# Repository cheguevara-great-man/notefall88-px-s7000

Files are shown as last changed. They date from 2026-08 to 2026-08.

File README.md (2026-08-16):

# NoteFall 88

NoteFall 88 是面向 Casio PX-S7000 的可拆卸单排琴键提示灯。钢琴通过 USB-MIDI 直接连接 ESP32-S3；ESP32-S3 驱动一条覆盖 88 键的 APA102C/SK9822 灯带，并通过 Wi-Fi 连接 NoteFall Studio 平板 App/PWA 或内置 Core 网页。

> 钢琴上只有一排灯。瀑布流只在屏幕里显示。

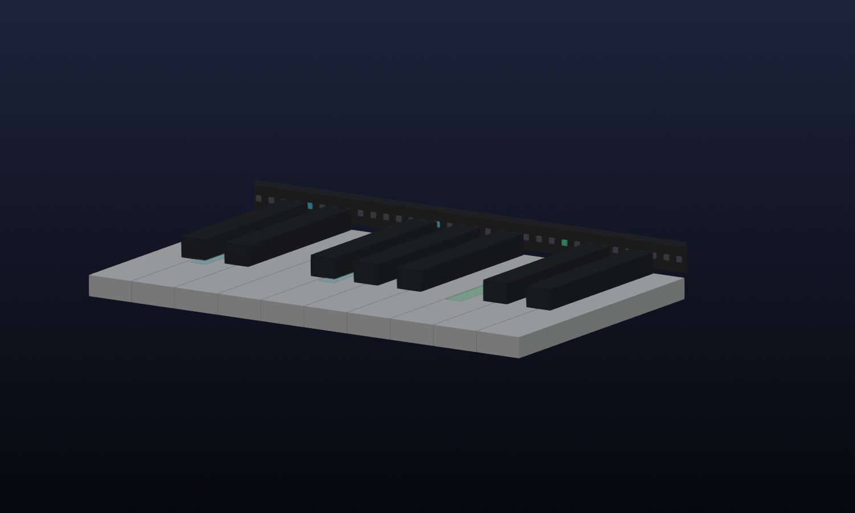
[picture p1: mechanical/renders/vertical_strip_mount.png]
竖直裸灯带安装原理


> 琴键一侧不使用贯穿全长的 3D 打印盒。灯带竖直安装、发光面朝演奏者且前方无遮挡，宽角度光束的下半部分直接照亮对应琴键。可选黑色薄承载片只负责保持灯带笔直，不包裹灯珠，也不是打印件。

安装时若对“朝演奏者”或照键角度有疑问，以 [带标注的剖面光路图](docs/optical-installation.svg) 为准：灯带不是朝上，也不是架高悬空，而是紧邻键面竖直安装在钢琴自带的固定黑色立面上。

## 最终架构

```text
PX-S7000 USB TO HOST <──USB-MIDI──> ESP32-S3-DevKitC-1 N8R8
                                             │
                                SPI ──> 74AHCT125 ──> 单排灯带
                                             │
                                           Wi-Fi
                                             │
                         NoteFall Studio App / PWA / Core 网页
```

网页端可直接导入 MIDI、MusicXML、XML 和 MXL，按需显示瀑布流或五线谱，并提供实时、等我弹和跟随我三种练习模式、左右手筛选、25%–200% 五个百分点步进变速、±12 半音同步移调、A–B 循环和命中/错键/漏键统计。MusicXML 的小节轨既可两点设整小节 A–B，也可从已选小节开始一轮新的、不会把前段误记为漏音的练习。实时模式可启用按 MIDI/MusicXML 真实拍号、速度变化和反复顺序生成的 Web Audio 节拍器，以及一小节预备拍；常用练习设置刷新后保留。实时分析还会计算拍点早晚、平均/P95 时序误差、力度均值与波动、最长连续命中和逐键难点；瀑布流在对应琴键上即时给出命中、错键、漏键标记。每次练习连同原始乐谱 SHA-256、模式、声部、速度、移调与循环范围仅保存在本机，可导出 JSON；任意历史会话可重新打开为时间/键位复盘，且同曲目多次记录会以稳定前后窗口显示准确率与时序改善趋势。自适应教练按内容身份而非曲名汇总同谱近期历史，避免同名不同谱串曲，再找出错漏最集中的片段和较弱声部，给出有证据的模式、速度、A–B 建议并可一键应用；进一步的“弱点巡回”会按反复展开后的小节、近期权重、错漏、拍点和左右手差异生成最多三关不重叠的训练路线，自动配置整小节循环、模式、声部与速度，并要求每关连续达标而不是偶然弹对；进度只保存在本机，可中断恢复。跟随我模式只要求用户弹一只手，另一只手经带时间戳的 USB-MIDI OUT 队列由 PX-S7000 自身音源演奏；若实机没有 OUT 端点则明确降级为无伴奏跟随。IndexedDB 曲库支持文件夹、并发内容去重，以及带 SHA-256、规模上限和原子恢复的完整备份；演奏录制包含力度、MIDI 通道和延音踏板，可导出标准 MIDI。钢琴按键数据走 USB 直达 ESP32，因此按键反馈不依赖无线链路。ESP32 自动连接已保存的家庭 Wi-Fi，同时永久保留 `NoteFall-88` 救援热点；Android Studio App 在局域网内自动发现设备并在地址变化后重连，浏览器可使用当前家庭 IP 或路由器支持时的 `http://notefall.local`，永久救援入口始终是 `http://192.168.4.1/recovery`。

曲库中的“今日练习”把单曲教练提升到跨曲目：只接受覆盖至少 60% 目标音、且没有 A–B 循环的全曲记录作为掌握证据，薄弱曲优先，连续稳定后按 1/3/7/14/30/60 天逐级安排复习。短循环刷出的 100% 不会延长整曲复习间隔；全部计算和历史仍只留在本机。

“示范当前声部”可从当前位置按所选左手、右手或双手，将乐谱音符和 CC64 踏板用 1.5 秒有界前瞻队列送回 PX-S7000 自身音源；变速、A–B 循环、换踏和重复同音都使用同一时间线。没有 MIDI OUT 时仍能静音预览谱面、瀑布流和实体目标灯；页面进后台、断连、循环回跳和手动停止都会执行踏板释放与 16 通道急停。演奏录制完成后也可不经导出直接用钢琴回放：保留 MIDI 通道、力度和 CC64/66/67，不把音量、音色等无关控制回写到钢琴，长音的 Note Off 按后续时间窗精确排程而不被 60 秒协议上限提前截断。

等待类模式要求目标和弦当前同时物理按住且没有仍按住的错误键，不能把各音逐个点过后松开来绕过和弦训练；目标音在整组和弦成立前只暂存、不计分，提前松键会撤销该音的暂存命中，因此也不能靠重复点按刷分。若正确和弦保持期间松开错误键，会立即一次性提交整组命中并推进，无需重弹。

实时判定与演奏录音使用 ESP32 在 USB 回调处采集的单调时间戳；浏览器通过低往返样本同步两端时钟，因此 Wi-Fi 排队抖动不会直接变成虚假的早/晚误差。旧固件或异常时间戳会明确降级为到达时间，不伪造同步精度。

实时模式不再用一套固定宽容度覆盖整首曲子：自适应、宽容、严格三档会按每个位置的真实拍速生成逐和弦窗口；快速重复同音还会受相邻同音间隔约束，避免一次按键误认成前后两个音。改变练习速度会保持相同的音乐拍值比例，练习面板同时显示当前现实毫秒范围。

录制导出会保留手指真实离键时刻、CC88 高分辨率力度前缀以及连续 CC64 半踏板、CC66/67 控制；实时练习分析在钢琴启用该选项时使用完整 14 位力度。若停止录制时延音踏板仍踩下，会自动补一个 CC64=0，避免文件回放时挂住踏板。

每个正确音还保留谱面目标力度。表现力分析会把整台琴/演奏者普遍偏轻或偏重的“力度基准”与相对强弱轮廓分开：前者单独显示，后者以 0–100 分进入历史趋势、复盘时间段和教练建议；谱面没有足够强弱变化时不会伪造轮廓分。

实时模式还会在 Note On 命中后继续跟踪物理 Note Off 与 CC64：分别记录手指松键和踏板抬起后的实际收音，计算谱面时值覆盖、无踏板释放精度、提前收音率与踏板延长量。MusicXML 的 staccato、staccatissimo、detached-legato 和 tenuto 会修正目标门控；没有可靠踏板记号时只报告踏板延长，不把过踏板武断判成错误。

和弦同步分析只合并乐谱中起点完全相同且完整命中的音，不把琶音、邻近快速音或漏音后的残缺和弦误判为“不齐”。它分别给出和弦展开宽度、P95、整齐度分，以及右手相对左手的有符号提前/滞后；这些证据进入时间复盘、历史趋势、教练调速和带连续达标门槛的双手专项巡回。

MusicXML 谱面中的延音踏板开始、停止、换踏和 0–100% 半踏深度会展开到真实反复播放时间线，先以 `PED ↓ / ↑ / ↻ / 百分比` 在 Web Canvas 与 Android 原生瀑布流中提前提示，再与 PX-S7000 的连续 CC64 输入逐动作匹配。判定按当前速度换算实际毫秒偏差，A–B 重复逐遍隔离，区分漏踏、多余动作、时机和深度；结果进入实时洞察、分段复盘、历史趋势、自适应调速与实时踏板专项关卡。没有踏板记号的谱面不会伪造提示或踏板分数。

手机锁屏、切换 App 或页面进入后台时，网页会确定性暂停乐谱时钟和预备拍、急停钢琴伴奏、熄灭目标灯，并停止且保留当前录音，避免浏览器节流造成批量漏键、延迟伴奏或静默录音缺口；返回前台后停在同一练习位置，由用户手动继续。

为避免手机在误开录制后无限占用内存，单次录制最多 4 小时或 200,000 个 MIDI 事件；达到任一上限会自动停止、明确提示，并允许下载上限前已经完整保存的部分。

MusicXML 目标时间线会按常见反复、多结尾和标准 D.C./D.S./Fine/Coda 导航属性展开，并支持普通/附点 beat-unit 的精确 metric modulation；五线谱光标通过播放小节到书写小节的映射正确回跳，而不是只按页面顺序判分。

首次仍通过 UART 线刷；此后可从家庭 LAN 或永久救援热点用管理密码更新双槽固件或 LittleFS 网页。上传中断不会切换启动槽；新固件必须通过内部自检并被真实 HTTP/WebSocket 客户端访问，未确认或启动异常会自动回滚。固件内置不依赖 LittleFS 的 `/recovery`。家庭 Wi-Fi 上的控制首次用管理密码解锁，随后浏览器持久保存随机令牌且 ESP 重启后仍有效；修改管理密码会撤销旧令牌。详见 [安全更新说明](docs/update.md)、[网络与救援](docs/deploy/network-and-recovery.md) 与 [WebSocket 协议](docs/protocol.md)。

手机离线使用由 ESP32 自己托管完整网页保证，不虚假依赖在局域网 HTTP 上通常不可注册的 Service Worker。浏览器曲库提供配额/持久化诊断和可校验备份；安全上下文、origin 隔离及 iOS/Android 验收边界见 [手机离线与本地数据](docs/mobile-offline-and-storage.md)。Studio 已把 3:2 横屏大平板作为正式目标，Xiaomi Pad 7 Ultra 的布局策略、首屏琴盘约束和自动化视口验收见 [Studio 平板布局](docs/studio-tablet-layout.md)。

Studio 还能在平板本地导入 MSCZ/MSCX、GP/GP3/GP4/GP5/GPX/GTP/PTB 和 KAR：锁定版本的 WebAssembly 在独立 Worker 中转为 MusicXML，不依赖 CDN，不进入 ESP32，完成后立即释放约 20 MB 运行时。转换后的标准 MusicXML 进曲库，二次打开无需重新转换。真实 MSCX 端到端浏览器门禁会同时验证三个音符的练习时间线和 OSMD 五线谱。

内置安装向导把断电接线/保险丝/无损材料/三点灯位/机械稳定等人工确认，与 ESP 连接、PX-S7000 USB 枚举、MIDI IN 端点和真实中央 C Note On 自动证据合并；未齐全时始终显示“硬件尚未验收”，并可导出不含密码的 JSON 报告。详见 [引导式验收说明](docs/commissioning.md)。

## 硬件基线

- 乐鑫 ESP32-S3-DevKitC-1-N8R8
- 5 V、144 像素/米、IP30 的 APA102C 或 SK9822；当前实物为 `32 + 72 + 72` 三段焊成的一条逻辑链
- 共 176 像素；计入两个照片拟合焊缝后物理长度约 `1230.42 mm`，覆盖 1222 mm 的 88 键键床
- 74AHCT125 成品电平转换模块
- 5 V / 5 A 有认证成品电源、3 A 总保险、20 AWG 首尾两端注电
- H5 给 USB-to-UART 口供电，H7 给 OTG Y 线的第 3 口供电；Y 线数据口经 USB-A 转 USB-B 打印机线连接钢琴
- Micro-Fit 4P 锁扣输入线和 XT30 远端注电线；所有引脚、线色和代焊验收已固定

第一次实际制作直接按 [五步装机清单](docs/first-build.md) 执行。完整采购见 [BOM 表](docs/bom.csv)，接线见 [硬件说明](docs/hardware.md) 与 [USB Host/供电决策记录](docs/decisions/001-native-usb-host-and-vbus.md)，可直接发给代焊方的规格见 [线束制造表](docs/harness.csv)、[线束图](docs/wiring-harness.svg) 和 [代工消息模板](docs/vendor-order-template.md)。逐项完成证据与实物边界见 [工程完成度审计](docs/completion-audit.md)。参数化控制盒如下；它只保护 ESP32 和接线，不安装在琴键上。

当前这台 PX-S7000 已购买商家确认可共点的 KF301‑2P/3P 端子与 74AHCT125N 裸芯片；KF301 到货后先逐孔验证共点关系，符合说明就直接用于配电，无需另买端子。实际购买记录、与通用 BOM 的差异及到货后唯一执行顺序见 [本机部署资料](docs/deploy/README.md)。历史问答保留用于解释决策，但不替代接线图和验收规范。

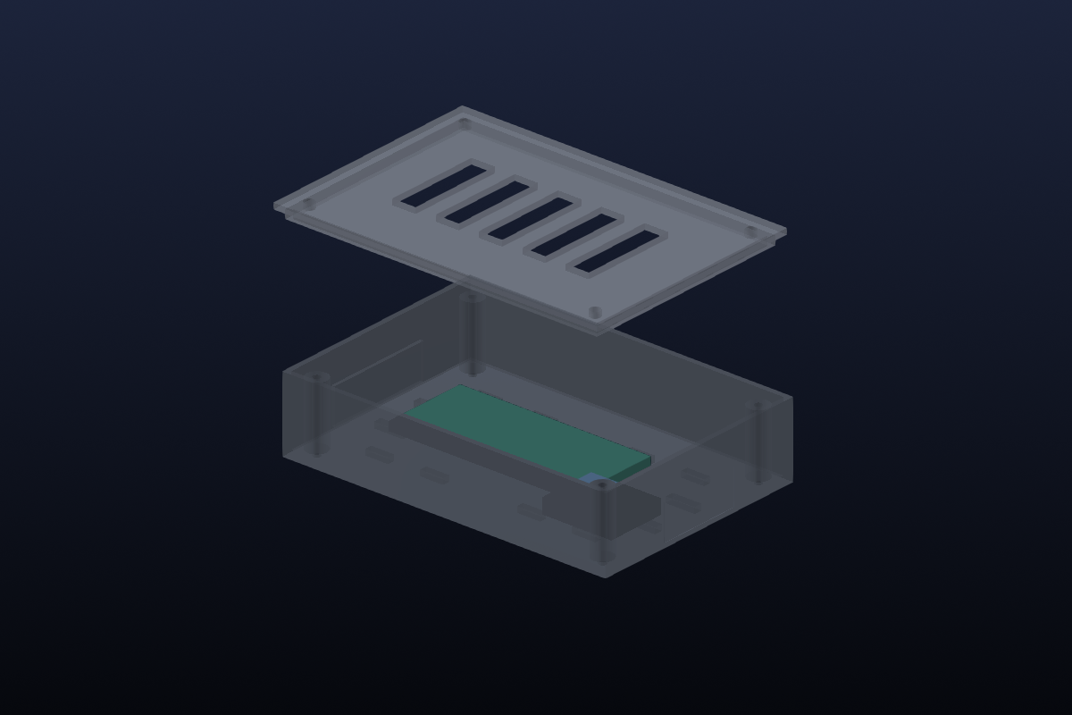
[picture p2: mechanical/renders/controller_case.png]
控制盒爆炸图


## 仓库内容

- `firmware/`：ESP32-S3 固件、USB-MIDI Host、Wi-Fi/WebSocket 和 APA102/SK9822 驱动
- `web/`：手机/平板/电脑通用网页，包含乐谱、曲库、练习、录制、诊断和校准
- `studio/`：Studio 独立 PWA 资源与 Capacitor Android/iOS 原生平台工程；平板主力入口
- `mechanical/`：可选控制器保护盒的 CadQuery 参数化模型；琴键侧没有打印导轨
- `config/system.json`：88 键、灯带、电气和机械参数的唯一来源
- `scripts/generate.py`：生成灯位映射、固件头文件和制造文件
- `tests/`：映射、功耗和机械包络测试
- `docs/`：接线、装配、校准、测试和开源项目技术调研

MusicXML 的当前支持范围、目标时间线与 OSMD 谱面之间的边界见 [MusicXML 说明](docs/musicxml.md)；练习指标定义和本地数据边界见 [练习分析说明](docs/practice-analytics.md)；手机与 ESP32 的稳定消息边界见 [WebSocket 协议](docs/protocol.md)。入站消息在进入练习状态前执行长度、类型、整数范围及 88 键校准完整性验证；实体按键灯先于网页广播刷新，并在诊断中显示 USB 回调到 SPI 完成的内部延迟。

## 从这里开始

全新乐鑫 N8R8 开发板无需先安装完整 PlatformIO：从 [GitHub Releases](https://github.com/cheguevara-great-man/notefall88-px-s7000/releases) 下载对应版本的 `notefall88-factory-*.zip`，完整解压并按包内 `FLASHING.md` 操作。脚本会验证板型、文件大小和 SHA-256，再要求明确确认后擦写。

1. 照片审查已确认琴键后方约 18–22 mm 固定立面可容纳 12 mm 灯带；下单后按 [一次性现场复核](docs/measurements.md) 用纸条做无接触安装验收，不需要打印试件或购买额外灯带。
2. 按 [BOM](docs/bom.csv) 买最终件，再按 [装配说明](docs/assembly.md) 让卖家代焊线束并组装。
3. 按 [刷机说明](docs/flashing.md) 首次写入固件和网页，并立即修改默认热点密码。
4. 严格依次执行 [断电检查、校准和验收](docs/testing.md)。

## 本地验证

```powershell
python -m pip install -r requirements-dev.txt
python scripts/generate.py --check
python -m pytest

cd web
npm.cmd ci
npm.cmd test -- --run
npm.cmd run build
npm.cmd run build:studio
npm.cmd run verify:studio
npx.cmd playwright-cli install-browser chromium
npm.cmd run smoke:browser
npx.cmd playwright-cli install-browser webkit
$env:NOTEFALL_BROWSER="webkit"; npm.cmd run smoke:browser

cd ..\studio
npm.cmd ci
npm.cmd run sync

cd ..
.\.venv\Scripts\platformio.exe run -d firmware
.\.venv\Scripts\platformio.exe run -d firmware -t buildfs
python scripts/render_cad.py
```

可选的真实 MusicXML 内容级交叉验证使用独立 `music21` 解析器；先按 [MusicXML 说明](docs/musicxml.md) 检出固定版本 OSMD 语料，再运行 `requirements-audit.txt` 与 `scripts/crosscheck_musicxml.py`。该环境不进入正式产品依赖。

网页构建结果直接写入 `firmware/data/`。JS/CSS 以预压缩 `.gz` 存储，ESP32 按原 URL 和正确 MIME/Content-Encoding 提供，既节省 Flash 也避开旧版 `mklittlefs` 的长文件名限制。随后可用 `platformio run -d firmware -t uploadfs` 写入开发板文件系统。

## 当前事实边界

软件、映射、CAD 和固件可以数字验证；Casio 官方文档确认 PX-S7000 的 USB-B 可双向发送/接收 MIDI 并驱动琴内音源，且把键盘发送的 Performance Controller 与外部接收的 C 组 Sound Generator 分开。固件不会依据时间相似性删除真实输入，只把疑似输出镜像计入诊断；具体实机的端点地址与镜像计数仍需验收。实际灯位偏移、温升和琴漆材料相容性也必须在实物上完成最终确认。网页校准允许反向灯带、修正全局像素偏移，并为个别琴键做 ±4 像素微调，不需要重新写固件。

NoteFall 原创源码和 Core 发行物采用 MIT 许可证。包含 GPL `webmscore-webpack5` 运行时的 Studio PWA/Android/iOS 组合发行物按 GPL-3.0 传递，完整正文、对应源码和固定完整性会随包提供；边界见 [ADR-005](docs/decisions/005-studio-score-converter.md)。现有项目的硬件拓扑、通信方式、功能、优缺点和采用边界见 [开源项目技术调研](docs/open-source-review.md)；为什么把 AGPL-3.0 的 Piano Trainer Studio 提升为第一软件参考但不直接 fork，见 [PTS 采用决策](docs/pts-adoption-decision.md)。组合能力的逐项领先性证据见 [竞争能力审计](docs/competitive-benchmark.md)，候选版与硬件验证版的严格边界见 [发布门禁](docs/release-readiness.md)。

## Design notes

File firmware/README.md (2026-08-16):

# ESP32-S3 固件

固件面向乐鑫官方 `ESP32-S3-DevKitC-1-N8R8`。原生 `USB/OTG` Micro-USB 口作为钢琴 USB Host；另一个 `UART` Micro-USB 口用于烧录和日志。

PlatformIO 构建横幅沿用通用板卡元数据，可能显示 `N8 (No PSRAM)`；本项目环境实际固定 `qio_opi`、OPI PSRAM 和 `BOARD_HAS_PSRAM`，链接映射使用 `esp32s3/qio_opi` SDK。最终仍以开发板启动日志和网页约 8 MiB 的 PSRAM 诊断为实物真相。

## 生成、构建和烧录

```powershell
python scripts/generate.py
cd web
npm.cmd ci
npm.cmd run build
cd ..
.\.venv\Scripts\platformio.exe run -d firmware
.\.venv\Scripts\platformio.exe run -d firmware -t upload
.\.venv\Scripts\platformio.exe run -d firmware -t uploadfs
```

首次必须同时烧录固件和 LittleFS 网页。后续只改网页时可仅执行 `uploadfs`。

## 运行状态

- 热点：`NoteFall-88`
- 密码：`notefall88`
- 家庭网络：Android Studio App 通过 UDP 32188 自动发现；浏览器使用当前 DHCP IP，或在路由器/客户端支持 mDNS 时使用 `http://notefall.local`
- 永久救援入口：连接 `NoteFall-88` 后打开 `http://192.168.4.1/recovery`
- WebSocket：端口 `81`
- 固件：0.7.2
- 协议：v6

亮度上限 `4/31` 写在生成头文件中。修改网页滑块不能越过该值。

## 实机诊断

网页“灯带校准 → 设备诊断”显示 USB VID/PID、MIDI IN/OUT 端点与包长、双向累计包数、IN/OUT 队列当前深度与峰值、OUT 排程深度、输入队列丢包/CIN 坏包/传输错误、疑似输出镜像、USB 回调到实时任务及 SPI 完成的两段内部延迟、SPI 帧耗时、实时任务心跳/栈余量/看门狗、ESP/浏览器拒绝消息、网页 MIDI 队列峰值/丢弃/重同步、连接次数、空闲堆、PSRAM、NVS、上次复位原因和 Wi-Fi RSSI。合法但不消费的 SysEx、时钟和 Active Sensing 会被忽略而不计为坏包；疑似镜像只计数，绝不吞掉无法与真实弹奏区分的输入。N8R8 启动时会检查 OPI PSRAM；网页应显示约 8 MiB 总量。正常连续弹奏和跟随伴奏时输入侧 `丢包 / 坏包 / 传输错误`、输出侧 `丢包 / 错误`、网页 MIDI 丢弃和两侧拒绝数都应保持 0，并且不得出现 `brownout`、`panic` 或 `watchdog` 复位。

`firmware/include/midi_core.h`、`realtime_core.h` 与 `usb_midi_descriptor.h` 是目标固件实际使用且不依赖 Arduino 的实时核心。`python -m pytest tests/test_firmware_core_native.py` 会以主机 `g++` 的严格警告选项编译并执行 MIDI 包、CC88、计时、真实灯位、固定容量环形队列、饱和延迟统计和 USB MIDIStreaming 描述符选择；这不是另写的模拟器。随后仍必须用 PlatformIO 的 Xtensa 工具链构建完整固件。

USB Host daemon 与 MIDI client 使用两个专用 FreeRTOS 任务，client 最长 5 ms 事件等待不再排在 daemon 的 20 ms 等待之后。IN 回调只打微秒时间戳并写入固定长度环形队列；整个 USB transfer（同批和弦）入队后只唤醒一次优先级更高、固定在 Core 0 的实时任务，既保留单帧和弦又不会被持续输入饿死。实时任务先完成灯带帧，再由 Core 1 的 Arduino 主任务从独立 128 项网页队列限量广播。网络、JSON 和 OTA 不进入实时任务，Wi-Fi 拥塞不会阻塞实体灯；网页队列极端溢出时以既有全通道 CC64/66/67/123 + 当前按键事件重同步，避免漏掉 Note Off 或踏板释放后永久挂键。APA102 的 719 字节帧用单次硬件 SPI 批量操作发送，RGB 顺序、5-bit 全局亮度和 8 MHz 线速不变；状态未改变时不再重复发送原有的 100 fps 空帧。网页只传相对时间事件，固件以 `millis()` 排程；钢琴 USB 断开会立即清空目标、按键和测试灯，并由实时任务提交熄灯帧；网页失联会执行 16 通道 Sustain Off 与 All Notes Off。

生产网页的 JS/CSS 只保存 `.gz` 文件。Arduino-ESP32 `WebServer` 在请求原始 `.js`/`.css` URL 时自动选择同名 `.gz` 并发送正确的 `Content-Encoding: gzip`；`index.html` 保持未压缩，确保根路由和救援提示始终可读。

## 无线维护

双 OTA 固件槽和独立 LittleFS 分区由 `partitions.csv` 固定。`/api/update` 在家庭 LAN 与永久 SoftAP 上都再次校验管理密码；上传开始会熄灯并清空 MIDI OUT。新固件保持 pending-verify，只有内部自检和真实网络访问同时成功才确认，否则 90 秒内自动回滚。`/recovery` 编译进应用镜像，不依赖 LittleFS。详细操作与恢复见 `docs/update.md`。

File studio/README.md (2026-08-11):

# NoteFall Studio

NoteFall Studio 是独立于 ESP32 LittleFS 的手机、平板和电脑端发行物。它与 NoteFall Core 共享经过测试的 MusicXML/MIDI、练习、曲库、分析和 WebSocket 协议源码，但拥有独立构建、PWA 清单、离线缓存、Core 地址设置和面向横屏平板的五线谱/瀑布流双视图。Studio 另外内置 Worker 隔离的离线 MuseScore、Guitar Pro 和 KAR 转换；首次导入转为 MusicXML 后存入曲库，后续打开不再加载转换引擎。

```powershell
cd web
npm.cmd ci
npm.cmd run build:studio
npm.cmd run verify:studio
npm.cmd run dev:studio
```

构建输出位于 `dist/studio/`，不会写入 ESP32 的 `firmware/data/`。首次完整打开后，同源静态资源由 Service Worker 缓存；乐谱与练习历史继续保存在当前设备 IndexedDB。

浏览器安全边界仍然真实存在：从公网 HTTPS 页面访问 ESP 的 `ws://` 连接可能被混合内容或本地网络权限阻止。正式移动端因此使用同一 Web 代码加 Capacitor 原生容器；Android/iOS 平台工程已进入 `studio/android` 与 `studio/ios`。Core 自带网页始终保留为无需安装的恢复入口。

## 两种发行物，不是两套产品

- **Android/iOS App**：练琴平板的主力入口，资源随安装包离线提供，原生层负责局域网权限与生命周期。
- **PWA**：电脑、临时设备和开发调试的备用入口。

二者共享 `web/src` 的界面、乐谱、练习和协议实现。用户无需同时安装；正式装配说明将把 Android/iOS App 列为推荐项，把 PWA 列为备用项。

## 构建与同步

```powershell
cd web
npm ci
npm run build:studio
npm run verify:studio
cd ..\studio
npm ci
npm run sync
```

Android 使用 JDK 21 与 Android SDK 36，可用 `android/gradlew.bat assembleDebug` 构建；它已注册 `NativeWaterfall` 插件，使用硬件加速 Android View 绘制瀑布流。iOS 工程必须在 macOS/Xcode 上签名构建，目前使用 Canvas/WebGL 回退。生成的 App 只加载随包资源，不加载远程站点。架构理由和性能门禁见 `docs/decisions/004-studio-hybrid-native.md`。

## 许可证

Core 固件和内置网页仍按 MIT 发行。Studio 安装包/PWA 因随包分发 GPL
`webmscore-webpack5` 转换运行时，组合发行物按 GPL-3.0 传递。详细边界见
[`LICENSE.md`](LICENSE.md) 和 `docs/decisions/005-studio-score-converter.md`；完整 GPL
正文会作为 `legal/GPL-3.0.txt` 随 PWA 和 App 离线分发。

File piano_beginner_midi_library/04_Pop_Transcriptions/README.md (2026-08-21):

# Pop-transcription fallback library

This folder is deliberately separate from the verified human-performance
library. A file here is a score/transcription MIDI, never a claim that the
artist or a pianist performed it live into MIDI.

## Admission rule

Only add a file after all of the following are recorded in its adjacent
`metadata.json`:

1. A lawful source URL and its arranger/uploader attribution.
2. The original work, arranger, and explicit classification
   `score_transcription_fallback`.
3. A full-file audit from `tools/audit_transcription_midi.py` that passes:
   - at least 90 seconds and 300 note-on events;
   - piano-only GM program data, with no drum-channel notes;
   - at least four distinct note velocities;
   - no silent conversion, re-timing, quantisation, or AI transcription by
     NoteFall.
4. A manual listen-through confirming it is a coherent solo-piano
   arrangement rather than a short demo or a backing-track reduction.

CC64 sustain pedal is preferred but not mandatory for an authored score
transcription. The metadata must state its actual presence.

## Rejected sources and files

The following are useful search leads but **not library entries**:

| Source | Finding | Decision |
| --- | --- | --- |
| MIDI云, `周杰伦系列 - 钢琴` | Returned 20–51-second demo clips instead of complete files. | Rejected as preview material. |
| MIDI云, `光年之外 - 邓紫棋 - 钢琴` | 211 notes, one fixed velocity, no CC64. | Rejected as low-expression excerpt. |
| Online Sequencer, `夜曲` | Export had synth/guitar programs, three velocity values, no CC64. | Rejected as non-piano instrumental reduction. |
| PianoSnap `夜曲` solo arrangement | A full score/MIDI product exists but requires a separate paid checkout. | Do not acquire without explicit purchase authority. |

The point of this registry is to prevent a low-quality fallback from ever
being mislabeled as a verified performance MIDI merely because it has a
popular title.

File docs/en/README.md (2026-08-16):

# NoteFall 88 documentation

This is the English documentation set for **NoteFall 88**, a removable, non-destructive LED key-guidance system designed for the Casio PX-S7000.

The piano sends USB-MIDI directly to an ESP32-S3. The controller drives one vertical, exposed APA102C/SK9822 strip behind the keys and provides a Wi-Fi control surface. NoteFall Studio runs on a phone, tablet, or computer and supplies notation, piano roll, practice modes, recording, analysis, and library management.

> The physical piano uses one LED strip only. Falling notes are a screen visualization, not a multi-row fixture on the piano.

## Start here

- [System architecture](architecture.md)
- [Purchased hardware and electrical design](hardware.md)
- [First build and non-destructive installation](assembly.md)
- [Commissioning and LED calibration](commissioning.md)
- [Test and acceptance procedure](testing.md)
- [WebSocket protocol](protocol.md)
- [Music and practice features](studio.md)
- [Quality and performance evidence](quality-and-performance.md)

## Installation sequence

1. Inspect and bench-test the delivered parts with the piano disconnected.
2. Build and electrically test the controller and harness.
3. Temporarily position the strip on the piano; do not apply permanent adhesive yet.
4. Use the A0 / middle-C / C8 test lights to align the strip and complete calibration.
5. Verify full travel of every black and white key.
6. Make the final removable attachment, then repeat the three-point check.

The Chinese source documentation remains in `docs/`. English files are maintained in `docs/en/`; neither replaces the other.

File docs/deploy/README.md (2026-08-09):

# 本机部署资料

本目录记录用户这台 PX-S7000 的实际采购与到货验收，不替代仓库的通用制造基线。

## 当前状态

- 采购日期：2026-08-08
- 状态：已下单，尚未到货
- 实际路线：SK9822 裸线灯带 + 商家确认可共点的 KF301‑2P/3P 配电端子 + ESP32-S3 原生 USB Host
- 已知差异：本机没有按通用 BOM 购买 Micro-Fit、XT30 或成品 74AHCT125 模块；KF301 共点能力以商家确认和到货通断复核为准，74AHCT125N 裸芯片仍需先上面包板并最终焊成可靠小板
- 下一门禁：到货清点与断电检查；在通过前不得给灯带或钢琴 USB 链路上电

## 文件怎么用

1. [已购硬件台账](as-purchased.csv)：本次已经购买或已有的物品，以及每项到货时要确认的规格。
2. [到货验收清单](arrival-checklist.md)：包裹到齐后唯一应执行的顺序；它会把结果引到 G1 台架测试。
3. [制作与采购操作手册](vendor-manufacturing.md)：第 1 节是本机实际路线，第 2 节是通用厂家代工参考。
4. [工程问答记录](q-and-a.md)：历史决策背景与解释，不作为接线图或最终验收依据。

若上述文件互相冲突，优先级为：

1. [ADR-001 USB Host 与供电](../decisions/001-native-usb-host-and-vbus.md)
2. [硬件与接线](../hardware.md)
3. [上电、校准与验收](../testing.md)
4. 本目录的本机部署覆盖
5. 历史问答记录

本目录不保存订单号、物流单号、收货地址、付款信息、聊天截图或含个人信息的实物照片。

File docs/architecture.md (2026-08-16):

# 系统架构

## 设计结论

实体端采用一条单排灯带，不在琴上制作多排瀑布流。屏幕瀑布流负责表达未来时间；实体灯带只表达下一组目标键、当前按键及对错反馈。

```mermaid
flowchart LR
  P["PX-S7000 USB TO HOST"] -->|"USB-MIDI IN，按键事件"| E["ESP32-S3 N8R8"]
  E -->|"USB-MIDI OUT，跟随伴奏"| P
  E -->|"SPI DATA + CLOCK"| L["74AHCT125 + 176 像素单排灯带"]
  E <-->|"本地 Wi-Fi + WebSocket"| W["NoteFall Studio App / PWA / Core 网页"]
  F["MIDI / MusicXML / MXL"] --> W
  A["MSCZ / MSCX / Guitar Pro / KAR"] -->|"Studio 离线 Worker 转 MusicXML"| W
  W --> V["五线谱 / 瀑布流 / 曲库 / 练习 / 录制 / 校准"]
```

## 时序分工

- USB-MIDI 事件由 ESP32 直接读取并立即更新灯带，按键反馈不绕行手机。
- 网页在本机浏览器解析 MIDI、维护播放时钟并绘制瀑布流。
- 网页只把“下一组目标键”发送给 ESP32。该信息本来就提前 0.3～2.0 秒显示，因此局域 Wi-Fi 的毫秒级波动不会改变可弹奏性。
- 等待模式由网页维护目标和得分，ESP32 将实际按键事件实时回传。
- 跟随模式在用户完成当前练习手和弦后，由网页生成另一只手的相对时间事件；ESP32 在本地排程并经钢琴 USB MIDI OUT 播放，不依赖浏览器定时器逐音发送。断线、复位和熄灯会清空排程并发送 Sustain Off / All Notes Off。
- 全谱示范和录音回放复用同一 MIDI OUT 所有权与急停边界，但各自使用有界的 1.5 秒前瞻时间窗。Note On、Note Off 和踏板按各自真实时刻分窗排程，因此长音不会被 60 秒单事件延迟上限截断。示范时网页仍推进谱面、瀑布流和目标灯；录音回放则保留原 MIDI 通道和 CC64/66/67，且两者均不进入练习评分或新录音。
- MIDI OUT 是受保护的写操作：设备存在 OUT 端点仍不等于当前页面可用。SoftAP 需自动授权，家庭 Wi-Fi 需先用热点密码换取当前标签页令牌；未授权页面会显示“需先解锁控制”，不会把端点存在误报成可播放。
- 网页每 1 秒刷新一次未变化的目标，允许用户在等待模式中长时间思考；WebSocket 断开或目标超过 3 秒未更新时，ESP32 仍会清除目标灯。
- USB Host 回调只负责接收、打微秒时间戳和写固定队列；Arduino 主任务排空同批事件后先完成一帧灯带 SPI，再从另一条固定队列广播网页 MIDI。慢客户端或 Wi-Fi 抖动不能排在实体按键灯之前，也不会跨任务操作网络对象。

## 两路音符数据与职责边界

这两个来源不能混为“一路 MIDI”：

| 数据流 | 来源 | 主要消费者 | 含义 |
|---|---|---|---|
| 参考/目标音符 | 浏览器加载的 MIDI 或 MusicXML/MXL | 浏览器练习引擎、ESP32 目标灯层 | 现在或将来应该弹哪些键 |
| 实际演奏音符 | PX-S7000 USB-MIDI → ESP32 | ESP32 即时按键灯、浏览器判分/录制 | 用户实际上弹了哪些键、力度和踏板状态 |

浏览器比较目标与实际演奏并计算命中、漏键和等待推进。ESP32 不解析完整乐谱，但保留目标集合的短期副本用于实体提示；同时它直接处理实际演奏事件，因此即使 Wi-Fi 短暂抖动，按键即时反馈仍可工作。

这与 Piano Trainer Studio 的“浏览器计算目标和判分、WLED 通常只收 RGB 帧”思路有相同的职责原则，但物理边界不同：NoteFall 由 ESP32 直接做 PX-S7000 USB Host 和 APA102/SK9822 驱动，不要求手机浏览器支持 Web MIDI，也不需要 WLED/helper。

## 软件实现与许可证边界

Piano Trainer Studio 是第一软件/产品参考，但采用 AGPL-3.0 且默认硬件拓扑不同。本仓库不 fork 或复制其主代码；NoteFall 原创源码与 Core 保持 MIT。MusicXML/MXL 已通过独立时间线解析器与 BSD-3-Clause 的 OSMD 接入。Studio 另外从上游 npm 发行包独立引入 GPL `webmscore-webpack5` 用于离线格式转换；含该库的 Studio 组合发行物按 GPL-3.0 传递，不改变不含该库的 Core 许可证。完整比较见 [PTS 采用决策](pts-adoption-decision.md)和 [ADR-005](decisions/005-studio-score-converter.md)。

### Core / Studio 分层

固件内置可离线使用的 **NoteFall Core**：USB Host、实时灯光、安全/诊断，以及足以完成日常练习的救援网页。独立的 **NoteFall Studio** 已建立自己的构建、PWA 清单、Android/iOS 原生平台工程、可配置 Core 地址，以及五线谱/瀑布流分屏。两者共享经过测试的 MusicXML、练习、曲库和协议源码，不复制两套业务引擎。

Core 的“离线”是 ESP32 本地托管，不是 Service Worker 缓存。Studio PWA 的资源由自己的安全 origin 缓存，包括固定版本的 MuseScore/Guitar Pro WebAssembly 转换运行时；Android/iOS App 则把同样资源随安装包提供，并由原生平台工程声明局域网和明文私网访问策略。设备热点的 HTTP origin、安全上下文与持久存储边界见 [手机离线与本地数据](mobile-offline-and-storage.md)。

Studio 仍通过同一语义协议连接 Core，重型资源由手机/平板/电脑存储，ESP 继续保留轻量救援网页。正式平板路线采用混合原生容器：OSMD 谱面保留 WebView；Android 瀑布流由硬件加速原生 View 使用单调时钟逐帧绘制，Web/PWA 与暂未有 Xcode 构建环境的 iOS 使用 Canvas/WebGL 回退。真正重写的是呈现/交互层，不是 MusicXML、评分、曲库、协议或固件。选型、性能门禁与局部原生化边界见 [ADR-004](decisions/004-studio-hybrid-native.md)。

练习页面提供统一的“全屏演奏”状态：入口固定在可视化画面内，不占顶部工具条；用户也可记忆“播放时自动进入全屏”。Web/PWA 使用 Fullscreen API，并在权限或浏览器策略拒绝时降级为纯 CSS 沉浸布局；Android 通过原生桥隐藏状态栏和导航栏。两条路径共享相同的三视图布局、退出按钮和安全区处理，不把全屏能力绑死在某个浏览器实现上。

瀑布流另有独立的“演奏视野”参数（近距离 2.8 秒、标准 4.2 秒、远距离 6.5 秒）。该参数只控制屏幕纵向时间尺度，与实体灯提前量分离；Web Canvas 与 Android 原生 View 使用同一持久化值，避免两个发行物出现视觉时序差异。

MusicXML 踏板目标在反复展开后转换为独立提示轨；踩下、抬起、换踏和半踏分别显示 `PED ↓ / ↑ / ↻ / 百分比`。换踏在评分层保留抬起和再踩两个边沿，在视觉层合并为一个动作；Web Canvas 与 Android 原生 View 共享相同提示数据。

瀑布流右缘绘制 72 段全曲指纹：左、右半轨分别编码左右手音符密度，白色游标表示整曲位置，白色框表示当前屏幕预览窗口，启用 A–B 时再叠加金色练习区间。密度在载入乐谱时预计算，逐帧只绘制固定 72 段，不随曲长增加渲染复杂度；Web Canvas 与 Android 原生 View 采用相同算法和语义。

目标力度通过音符体亮度、内部高光宽度和落键端白色“力度帽”共同编码，但绝不改变音符横向位置或宽度。归一化保留 72% 的 MIDI 绝对力度与 28% 的曲内 10%–90% 分位对比；整首弱奏仍明显弱于整首强奏，同时单个异常速度值不会压扁其余层次。未选择声部继续固定低亮度，避免力度编码破坏声部筛选语义。

实时命中还在对应琴键上显示短暂的“早 / 准 / 晚”时序尺：±25 ms 视为准点，偏差位置按有符号毫秒数移动并在 ±250 ms 截断。宽键位显示精确毫秒数，手机窄键位只保留箭头/圆点和颜色，避免文字互相覆盖；Web Canvas 与 Android 原生 View 共享同一阈值、方向与颜色语义。

## 练习引擎

- `等我弹`：当前和弦的所有目标音都命中后才前进；重复按同一个正确音不重复计分，错误音单独统计。
- `实时`：默认采用逐和弦自适应判定窗，按当前位置真实拍间隔计算提前/延后容差，并提供宽容/自适应/严格三档；快速重复同音会把窗口限制在相邻同音间隔的 48% 内，防止一个 Note On 跨到前后两个目标。窗口存于乐谱时间轴，改变练习速度时自动换算现实毫秒值，从而保持相同音乐拍值比例；窗口过后未命中的目标记为漏键。
- `跟随我`：限定练习一只手；用户完成目标和弦后，另一只手由 PX-S7000 自身音源播放，再按原谱间隔与所选速度进入下一组。伴奏同音重触发前会先结束旧音，循环跨界按 A–B 时间轴计算。
- 左手、右手或双手筛选发生在和弦分组之前，因此目标灯和判分使用同一组音符。
- A–B 循环限制目标、判分和播放时钟；到达 B 点后回到 A 点并开始新一轮匹配，累计成绩不清零。
- 移调限制为 ±12 半音：统一时间线、瀑布流、实体目标和 OSMD 五线谱同步改变；超出 A0–C8 的音符从可弹目标中剔除，原始曲库文件不被修改。
- MusicXML 先把反复、多结尾、D.C./D.S./Fine/Coda 展开为播放小节序列，再统一换算速度和秒时间；每个音符保留展开后的拍位置，每个播放小节保留书写小节索引。OSMD 光标因而能在同一小节内逐音前进，并在反复或跳转时回到正确的印刷小节；目标、判分、循环和跟随伴奏消费同一展开结果。光标颜色表达当前手别，判定反馈直接浮现在谱面光标旁，不强迫演奏者把视线移向成绩栏。
- 同一展开后时间线还驱动全曲小节练习热力带：每个播放出现次数分别聚合命中、错音、漏音和平均绝对时序偏差，映射为稳定/注意/薄弱三档。它与印刷小节标签同时显示，因此反复段不会把第一遍与第二遍的表现错误合并；点击任一热力段会走正式“小节重开”流程，而不是只移动画面游标。
- 瀑布流在装载乐谱时把 35 ms 内的近同时音符预聚合为和弦星座；逐帧只绘制未来 1.8 秒内、至少包含两个当前练习声部音符的弧线与节点。跨双手和弦在弧顶增加菱形协调标记。Web Canvas 和 Android 原生 View 使用相同时间窗、显隐和主题语义，既帮助识别和弦形状，又避免给单音旋律增加噪声。
- 屏幕仍可低亮度显示未选择声部，实体灯只提示正在练习的声部。
- 逐音分析记录正确、错键和漏键事件；命中同时保存实弹/谱面目标力度，实时模式额外记录相对目标起点的有符号时序误差。浏览器据此计算拍点偏置、平均/P95 绝对误差、连续命中和逐键错误率；表现力层把会话级普遍偏轻/偏重作为独立力度基准，再以相关性和基准校正残差评价相对强弱轮廓。目标力度没有足够变化时不产生轮廓分，避免用一个虚假的百分比代替证据。
- 实时命中还由独立的多通道/同音队列继续跟踪 Note Off 与 CC64。物理按键时长和踏板释放后的发声时长分别回填到原命中事件，不增加虚假的判定次数；目标时值按练习速度缩放，并识别 MusicXML 常见断奏/保持记号。时值覆盖、无踏板释放精度、提前收音和踏板延长进入复盘、趋势、教练及弱点巡回；由于当前时间线没有足够可靠的踏板记号，踏板过长只陈述事实而不伪判艺术对错。
- 和弦同步层只按完全相同的谱面起点聚合命中，并拒绝含漏音的残缺组；它由同一硬件采集时间轴计算最早/最晚落键跨度及右手相对左手的平均偏移，因而能把“整组都晚但内部整齐”与“拍点正确但双手散开”分开。稳定样本进入 24 段复盘、同谱趋势与教练调速；弱点巡回可生成只能在实时模式验收的双手/单手和弦专项关卡。
- USB 回调用 ESP32 单调时钟给每个琴键和踏板事件打时间戳；周期 `ping/pong` 同时返回浏览器发送时刻和 ESP32 处理时刻，网页在近期样本中选择往返时间最低者，将设备时钟投影到 `performance.now()`。实时匹配与 MIDI 录音使用投影后的采集时刻而非 WebSocket 到达时刻；算法显式处理 uint32 回绕、设备重启、未来/过旧事件，并把半个最佳 RTT 作为同步误差上界显示。没有可用样本时安全退回到达时间，不伪造同步精度。
- 一次练习结束、复位或改变模式/声部/循环/移调时，非空会话写入独立 IndexedDB。最多保留最近 500 次，完整事件最多 20,000 个；不上传云端，可由用户导出版本化 JSON。
- 自适应教练用原始乐谱 SHA-256 而不是易冲突的曲名识别同一乐谱，最多读取最近 20 次记录；再用加权错漏密度选择 4–12 秒难点窗口，用左右手独立错误率选择声部，并按准确率、时序误差、力度轮廓、时值释放和和弦整齐度在 25%–200% 范围内以 5%/10%/15% 渐进调整速度。音高和拍点已稳定但任一有证据的表达/同步指标未达标时也不会盲目提速；建议始终显示证据量和置信度，用户一键应用后才改变练习设置。
- 弱点巡回把“一次建议”升级为可执行的掌握路线：最多读取同谱最近 24 次记录并按新近程度衰减，分别聚合反复展开后的每个播放小节，综合漏音、错音、绝对时序、力度轮廓、时值覆盖、和弦同步、谱面踏板、证据量和左右手错误率，选出最多三个不重叠片段；每关自动带入一个上下文小节，给出模式、声部、速度及适用的准确率/时序/力度/时值/和弦/踏板门槛，并要求有效判定至少覆盖该关所选声部的全部目标音。同步和踏板关卡固定使用实时模式，因为 Wait for Me 没有绝对时点。用户显式提交本轮后，只有连续两次达标才进阶，失败会清零连续计数；同谱内容身份、关卡进度与尝试次数写入本机 `localStorage`，刷新可恢复，不上传网络，畸形或跨谱缓存会被拒绝。
- 跨曲目“今日练习”以曲库 SHA-256 连接最多 500 次本机历史，只接受无 A–B 且判定事件覆盖至少 60% 目标音的全曲记录。最近三次按 55/30/15% 加权，组合准确率、拍点、力度、时值、和弦与谱面踏板形成可解释掌握度；薄弱曲优先，连续稳定后按 1/3/7/14/30/60 天复习。它不上传数据，也不会让短循环的高分延长整曲复习间隔。
- MIDI 以 PPQ 和拍号事件生成拍点；MusicXML 以展开后的播放小节、`beats`/`beat-type` 与速度事件生成拍点。节拍器在动画帧中只选择未来 120 ms 的拍点，实际发声交给 Web Audio 时间轴，不依赖 `setInterval` 精度；A–B 回绕会取消旧排程并从 A 重新定位。
- 预备拍从起点所在拍号推断一小节长度和局部拍间隔；预备期间乐谱时钟与判分保持暂停。暂停、复位、切换模式或到达结尾都会取消尚未发声的振荡器，避免残留点击。

指标的严格定义和隐私边界见 [练习分析说明](practice-analytics.md)。

## 协议与诊断

当前 WebSocket 协议版本为 `6`。ESP32 每秒上报固件版本、控制会话/接口来源/默认密码布尔状态、认证失败数、USB 连接状态、VID/PID、IN/OUT 端点与包长、双向累计包数、排程深度、队列丢包、传输错误、疑似输出镜像次数、USB 回调到 SPI 完成的内部延迟、连接次数、空闲堆、PSRAM 总量/余量、NVS 状态、启动复位原因和 Wi-Fi RSSI。音符事件包含 1–16 通道；控制事件包含 CC 编号和值，当前使用 CC64 延音以及 CC120/123 全部音符关闭。浏览器的 MIDI OUT 消息只接受 60 秒内、状态/数据字节合法的事件，固件固定容量排程并再次限幅。Casio 官方 MIDI 实现把键盘发送的 Performance Controller 与外部接收的 C 组 Sound Generator 分开，没有定义 MIDI Thru 路径；因此与刚发送伴奏字节相同的输入只增加诊断计数，绝不被启发式删除。校准消息同步 88 个逐键像素修正，修正范围为 ±4 且由固件再次限幅。浏览器对所有入站消息执行类型、范围、长度与 88 键数组完整性校验；两端拒绝数均可见。诊断只读，只报告默认密码是否仍在使用，不包含任何 Wi-Fi 密码内容。

完整字段、示例、限幅和版本演进规则见 [WebSocket 协议 v6](protocol.md)。

## 灯位映射

88 键并非等距半音。映射生成器先按 52 个等宽白键建立白键中心，再把黑键中心放在相邻白键边界处，最后从实际物理坐标中选择最近 LED。当前 176 灯实物由 `32 + 72 + 72` 三段组成；段内名义节距 `6.944 mm`，31/32 与 103/104 缝按照片透视拟合分别额外加入 `4.22 / 3.98 mm`。重新生成后 88 键主像素仍全部唯一，最大理论中心误差为 `3.408 mm`。

网页可设置灯带方向、全局像素偏移和 88 键独立微调。参数保存在 ESP32 NVS 中，因此灯带从左或从右进线、或个别灯位存在装配公差，都不需要重新编译。逐键修正只在三点/全局校准后使用，限制为 ±4 个像素，避免误操作跳到远处琴键。

## 网络模式

ESP32 始终建立密码保护的 `NoteFall-88` 热点，地址固定为 `192.168.4.1`。如果网页写入家庭 Wi-Fi 凭据，设备同时以 STA 模式接入路由器并注册 `notefall.local`；热点继续保留作为恢复入口。

## 安全边界

- 灯带功率不经过开发板。
- 3.3 V DATA/CLOCK 经 5 V 供电的 74AHCT125 缓冲。
- 灯带固件全局亮度硬上限为 4/31，网页不能越权。
- 上电、USB 断开、WebSocket 目标超时和解析错误都以熄灭目标灯为安全状态。
- 钢琴 USB 只承载 MIDI，不给灯带供电。
- HTTP 更新写接口在家庭 LAN 与永久 SoftAP 上都要求不回显的管理密码请求头；固件身份检查、双槽 pending-verify、内部自检、真实客户端确认与 90 秒自动回滚共同保护更新。
- WebSocket 控制在 SoftAP 内自动授权；家庭 Wi-Fi/STA 首次在 `hello` 中验证管理密码。网页之后长期保存随机控制令牌，令牌也保存在 ESP NVS，因此浏览器关闭或 ESP 重启后无需重复输入；修改管理密码会换发令牌。重叠子网按 STA 失败关闭处理。
- 固件分区是两个等大的 2.5 MiB OTA 槽，运行槽不会被原地覆盖；LittleFS 独立为 2.875 MiB。更新开始前清空灯光、伴奏排程并发送全通道急停。
- 浏览器在上传前检查扩展名、最小合理体积和设备动态报告的分区上限；固件端仍由 Arduino Update 校验固件魔数、写入长度和激活结果。只有设备返回成功 JSON 后页面才提示重启。

## 引导式实机证据

安装向导的状态机把八个人工物理确认和五个自动证据分开。自动证据只由兼容协议状态帧、非默认密码状态、USB Host 端点和真实 MIDI Note On 写入；测试灯按钮不能伪造“弹过中央 C”。固件变化会撤销完成状态并清除需要重测的 USB/按键证据，恢复公开默认密码也会撤销完成状态。报告使用独立版本 1 JSON，只记录“已修改”布尔事实，不含网络密码。完整字段见 [引导式安装与实机验收](commissioning.md)。

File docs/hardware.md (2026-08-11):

# 最终硬件与接线

## 只买最终会使用的东西

| 项目 | 数量 | 淘宝/电商搜索词 | 参考价格区间（人民币） |
|---|---:|---|---:|
| APA102C 或 SK9822 灯带 | 连续 2 m ×1 | `5V 144灯 APA102 SK9822 黑板 IP30 非防水` | 120–260 |
| ESP32-S3-DevKitC-1-N8R8 | 1 | 已有；乐鑫官方板 | 0（已有） |
| 74AHCT125 成品模块 | 1 | `74AHCT125 四路 电平转换 模块 3.3V 5V` | 8–25 |
| 5 V / 5 A 成品电源 | 1 | `5V5A 3C 电源适配器 DC5.5 2.1` | 35–80 |
| DC5.5×2.1 一进三出配电线 | 1 | 按 `docs/harness.csv` 定制，20 AWG | 15–35 |
| 3 A 带座保险丝 + 2 只备件 | 1 套 | `3A 低压 保险丝座 线束` | 7–20 |
| 1000 µF / 10 V 低 ESR 电容 | 2 | `1000UF 10V 低ESR 电解电容 引线` | 4–12 |
| Micro-USB 供电 OTG Y 线 | 1 | `Micro USB OTG 一分二 USB母 独立供电` | 已有或 5–20 |
| USB-A 公转 USB-B 公数据线 | 1 | `打印机数据线 USB A公 B公` | 10–25 |
| Micro-Fit 3.0 兼容 4P 锁扣线 | 1 对 | `Micro-Fit 3.0 4P 公母 预压线` | 15–35 |
| XT30 预焊 20 AWG 线 | 1 对 | `XT30 公母 带线 20AWG` | 8–15 |
| 20–22 AWG 红黑线、26–28 AWG 信号线 | 若干 | `硅胶线 20AWG 红黑`、`四芯 26AWG` | 15–35 |
| 黑色 PET/PVC 薄载体 | 1（可选） | `黑色 PET 硬片 0.8mm 裁条` | 10–30 |
| 拉伸移除式无痕固定条 | 3–5 片 | `无痕固定条 拉伸移除` | 10–30 |
| 控制盒 | 1（可选） | 成品通风塑料盒或约 60 g 黑色 PETG 打印件 | 15–40 |

完整逐项物料和代焊要求以 [BOM CSV](bom.csv) 与 [线束制造表](harness.csv) 为准。通用重新采购规格仍优先选择连续 2 m 灯带并只裁一次；本机已购实物已经是 `32 + 72 + 72` 三段焊接的 176 灯逻辑链，不再裁剪或重焊，生成映射已经纳入两个焊缝。琴键侧没有 3D 打印盒或扩散条。

## USB 三条连接

```text
普通打印机线 USB-B 端 ─────────────> PX-S7000 的 USB TO HOST
普通打印机线 USB-A 端 ─────────────> OTG Y 线的 USB-A 母口
OTG Y 线 Micro-USB 公头 ───────────> ESP32 上标 USB / OTG 的 Micro-USB 口
H5 电源线 Micro-USB 公头 ──────────> ESP32 上标 UART / USB-to-UART 的 Micro-USB 口
H7 电源线 Micro-USB 公头 ──────────> OTG Y 线第 3 个 Micro-USB 供电口
电脑数据线 ────────────────────────> 首次刷机时替换 H5 接 UART 口；刷完拔电脑线再插回 H5
```

不要把 OTG Y 线插到开发板的 `UART` 口，也不要把 H5 电源线插到 `USB/OTG` 口。PX-S7000 连接的是方形 USB-B `USB TO HOST` 口，而不是安装 WU-BT10 的 USB-A 口。

乐鑫官方 [ESP32-S3-DevKitC-1 用户指南](https://docs.espressif.com/projects/esp-dev-kits/en/latest/esp32s3/esp32-s3-devkitc-1/user_guide_v1.1.html) 明确说明 USB-to-UART 口可给开发板供电。官方 [V1.1 原理图](https://dl.espressif.com/dl/schematics/SCH_ESP32-S3-DevKitC-1_V1.1_20221130.pdf) 还显示两个 USB 口的 VBUS 分别经 D1、D7 肖特基二极管进入板上 5V 网，因此 H5 从 UART 口给板子上电时，原生 `USB/OTG` 口不会反向输出设备 VBUS。本设计让 H5 给开发板供电，同时用同一保险后 5V 的 H7 给 Y 线第 3 口供电，为钢琴 USB 设备侧提供 VBUS。商品所称“不支持对手机供电”意味着 H7 不能替代 H5，而不是第 3 口无用。该结论的完整理由、禁止接法和验收项固定在 [ADR-001](decisions/001-native-usb-host-and-vbus.md)。

这是一条双向 USB-MIDI 链路：钢琴把按键/踏板发送给 ESP32，ESP32 也可把“跟随我”模式的另一只手音符送回钢琴音源。Casio [PX-S7000 用户手册](https://www.casio.com/content/dam/casio/global/support/manuals/electronic-musical-instruments/pdf/008-en/p/PXS7000_usersguide_EN.pdf) 明确说明该接口可发送和接收演奏 MIDI；固件仍会在每次连接时独立探测 OUT 端点，没有 OUT 时不盲目发送。

## 灯带接线

```text
ESP32 GPIO11 ─> 74AHCT125 A1 ─> Y1 ─> 100 Ω ─> 灯带 DATA IN
ESP32 GPIO12 ─> 74AHCT125 A2 ─> Y2 ─> 100 Ω ─> 灯带 CLOCK IN
ESP32 GND ────────────────────────────────┐
74AHCT125 GND ────────────────────────────┼─> 灯带 GND
5 V / 5 A 电源负极 ──────────────────────┘
5 V / 5 A 电源正极 ─> 3 A 保险 ─┬─> 灯带左右两端 5V
                                  ├─> H5 → ESP32 USB-to-UART 供电口
                                  ├─> H7 → OTG Y 线第 3 供电口
                                  └─> 74AHCT125 VCC
5 V / 5 A 电源负极 ─────────────> 灯带左右两端 GND
```

74AHCT125 的 `/OE1`、`/OE2` 接 GND；未使用通道的输入固定接 GND、`/OE` 接 5 V。灯带首尾各并联一只 1000 µF 电容，注意负极条纹接 GND。整机只使用一个 5 V 电源，保险丝保护灯带、控制器和 USB Host 供电全部支路，避免两只 5 V 适配器互相回灌或依赖上电顺序。

生产线束图

灯带箭头必须从 `DATA IN/CLOCK IN` 指向输出端。首尾两端只并联供电，不把末端数据接回首端。

## 免焊接现实边界

开发板、OTG 和电源均可直接插接；唯一强烈建议焊接的是灯带裁切端、首尾注电和两根 100 Ω 信号线。可让淘宝灯带卖家或手机维修店按接线图预焊，要求套热缩管并做导通/短路检查。高电流供电不建议长期依赖无锁扣的杜邦线或廉价灯带夹。

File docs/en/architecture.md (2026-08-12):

# Architecture

## Product boundary

NoteFall 88 separates latency-critical hardware from feature-rich practice software:

```text
PX-S7000 USB TO HOST -- USB-MIDI --> ESP32-S3 -- SPI --> 74AHCT125 --> APA102C/SK9822
                                         |
                                       Wi-Fi
                                         |
                       NoteFall Studio PWA / Android / iOS shell
```

The piano-to-light path is local to the ESP32-S3. A slow Wi-Fi connection must never delay live key feedback. Studio handles imported scores, rendering, practice state, recordings, reports, and the music library; it sends compact control and target-light messages to the controller.

## Responsibilities

| Layer | Responsibilities |
| --- | --- |
| PX-S7000 | Keyboard and pedal MIDI input; optional sound generator for MIDI output. |
| ESP32-S3 Core | USB host, timestamping, LED safety limits, APA102/SK9822 output, calibration persistence, diagnostics, local recovery UI. |
| NoteFall Studio | MusicXML/MIDI import, score and piano-roll views, real-time / wait / follow practice, recording, scoring, coaching and offline library. |
| Wire protocol | Versioned WebSocket messages, validation, diagnostics, time synchronization and explicit permission boundaries. |

## Physical LED model

The installed strip is a single serial chain with 176 addressable LEDs. It is physically made of three soldered sections: `32 + 72 + 72`. Two measured splice gaps are included in the generated mapping; the software does not pretend that every LED pitch is identical.

The mapping assigns each of the 88 piano keys a unique primary LED using actual white-key and black-key centres, not an incorrect equally-spaced chromatic grid. The user can reverse direction, apply a global pixel offset, and make bounded per-key corrections without recompiling firmware.

## Safety design

- LED power never passes through the ESP32-S3 board.
- A 74AHCT125 provides 3.3 V-to-5 V clock/data level conversion.
- Firmware owns the brightness ceiling and clears target lights on timeout, USB loss, parse error, or reboot.
- The piano USB connection carries MIDI only; it is not a power supply for the strip.
- Calibration and control traffic is authenticated on the device access point; home-network clients are read-only until explicitly authorized.

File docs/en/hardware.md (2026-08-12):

# Hardware and wiring

## Confirmed baseline

- Loxin/LeXin ESP32-S3-DevKitC-1-N8R8.
- One 5 V, 144 LED/m, IP30 APA102C or SK9822 strip. The delivered strip has 176 LEDs and two factory solder splices.
- 74AHCT125 level-shifter module.
- Certified 5 V / 5 A supply, inline 3–5 A fuse, 1000 uF bulk capacitor at both power-injection ends, and 0.1 uF ceramic bypass capacitor at the level-shifter supply.
- USB-B to USB-A printer cable from piano to the powered OTG host path.
- Micro-Fit 4-pin locking LED input connector and XT30 remote power-injection connector.

## Signal path

`ESP32 GPIO -> 74AHCT125 -> 100 ohm series resistor -> strip DATA/CLOCK`

The LED strip receives its own 5 V and GND wiring. DATA, CLOCK and GND must share a common reference. Do not connect LED power through an ESP32 GPIO, USB data connector, or breadboard jumper.

## USB roles

The PX-S7000 is a USB MIDI peripheral. The ESP32-S3 native OTG port is the USB host. The OTG Y-cable exists to provide VBUS power to the piano-side USB device path; its third leg powers the USB peripheral side, not the ESP32 board itself. The board has its own 5 V supply connection.

The exact connector labeling on the purchased N8R8 board must be confirmed from its silk screen on arrival. Follow the build checklist rather than guessing from cable gender.

## Delivered strip orientation

In the user's strip photographs, the four-wire/data-input end is on the physical right and printed arrows point left. Place the two-wire end at the piano's left, keep the four-wire input at the right/controller side, and enable the firmware direction-reversal setting if the A0/C4/C8 test proves it is needed.

Never cut, stretch, fold, or re-solder the delivered strip to remove the two splice gaps.

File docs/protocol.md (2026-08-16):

# WebSocket 协议 v6

NoteFall Core 在 TCP `81` 提供 WebSocket。消息均为 UTF-8 JSON；浏览器负责乐谱和练习语义，ESP32 负责 USB、灯位、排程与安全。协议不传 Wi-Fi 密码以外的敏感数据，诊断消息也不会回显已保存密码。

## 握手与状态

浏览器连接后发送：

```json
{"t":"hello","v":6}
```

从设备自己的 `NoteFall-88` 热点连接时，上述握手自动取得控制权；从家庭 Wi-Fi/STA 连接时，网页必须在同一条握手中附带当前热点密码：

```json
{"t":"hello","v":6,"auth":"current-hotspot-password"}
```

密码只在首次解锁时发送并由固件做常量时间比较，网页不会保存它。验证成功后，固件仅向这个已授权的 STA 会话返回 NVS 中的随机 `controlToken`；网页把该令牌保存在 `localStorage`，重连及正常重启后继续使用：

```json
{"t":"hello","v":6,"token":"persistent-random-control-token"}
```

令牌在正常 ESP 重启或关闭标签页后继续有效，但修改管理密码会立即换发并撤销旧令牌。它不进入 IndexedDB 曲库、练习记录、备份或诊断导出，也不能用于 Wi-Fi 配置、修改密码或固件更新；不应复制或导出。本地链路使用 `ws://`，不宣称端到端 TLS；家庭 WLAN 的链路加密和独有热点密码共同构成当前原型的网络边界。若 SoftAP 与家庭局域网子网重叠，固件按不可信 STA 处理并要求密码，不根据模糊地址自动授权。

ESP 返回 `status`；只有授权会话才返回 `calibration`、逐键 MIDI 与踏板事件。`status` 的稳定字段包括：

- `protocol`、`firmware`、`piano`、`clients`；
- `controlSessionReady`、`controlAuthorized`、`accessPointClient`、`webAuthRejected`；已授权 STA 的个性化状态还包含 `controlToken`，未授权或 SoftAP 客户端不返回该字段；
- `usbVid`、`usbPid`、`usbEndpoint`、`usbPacketSize`；
- `usbOut`、`usbOutEndpoint`、`usbOutPacketSize`；
- `usbPackets`、`usbDropped`、`usbMalformed`、`usbErrors`、`usbLastError`；其中 `usbMalformed` 只统计 CIN/status/data 边界不一致的坏包，合法但产品不消费的 SysEx、时钟与 Active Sensing 会被安全忽略而不误报；`usbLastError` 是不含凭据的最近枚举/传输原因，并随验收报告导出；
- `usbOutPackets`、`usbOutDropped`、`usbOutErrors`、`usbOutQueued`、`usbOutputMirrorCandidates`、`usbOutOwned`；
- `usbInputQueueDepth` / `usbInputQueueHighWater`、`usbOutputQueueDepth` / `usbOutputQueueHighWater`、`usbLargestInputBatch`、`usbInputResubmitRetries` 与两个 USB 任务的看门狗状态；
- `midiDispatchLatency*`（USB 回调到实时任务消费）、`ledInputLatency*`（USB 回调到 SPI 帧完成）；
- `ledFrames`、`ledFramesSkipped`、`ledSpiLastUs`、`ledSpiMaxUs`、`ledFrameBytes`；
- `realtimeReady`、`realtimeWatchdog`、`realtimeHeartbeatAgeMs`、`realtimeWakeups`、`realtimeStackFreeBytes`；
- `webMidiQueueDepth`、`webMidiQueueHighWater`、`webMidiDropped`、`webMidiResyncs`、`brightness`、`offset`、`reversed`、内存、NVS 状态、启动复位原因、运行时间和 RSSI。

`resetReason` 使用稳定字符串，例如 `power-on`、`software-reset`、`panic`、`watchdog` 或 `brownout`。它记录当前这次启动的来源；若满亮度或强奏测试后出现 `brownout`/`watchdog`，应先排查供电、短路、堆栈或阻塞，不得把自动重启当作正常恢复。

未知字段必须忽略。固件先把新连接标为未握手：只有匹配 `hello.v` 且控制授权成立后，才接受目标灯、校准、测试灯、熄灯或 MIDI OUT 等改变状态的消息。协议不一致时只允许查看状态诊断，并返回 `{"t":"protocolError","expected":6,"received":5}`；无效 JSON、超过 8192 字节、未握手、协议不符或未授权的控制消息计入只读字段 `webRejected`，错误 STA 密码另计入 `webAuthRejected`。未授权 STA 仍可读基础设备/USB/内存诊断并使用 `ping`，但收不到演奏事件和校准数组。

网页也把设备消息当作不可信输入：消息超过 65536 字节、字段类型错误、非整数/越界 MIDI、不是恰好 88 项或超出 ±4 的校准数组都会在进入练习状态前被拒绝。设备端与浏览器端拒绝数分别显示，避免把网络或版本故障静默转换成错误琴键。

## 钢琴输入

ESP 把 USB MIDI 标准化为：

```json
{"t":"midi","s":"on","ch":1,"n":60,"v":96,"vh":12345,"ts":123456}
{"t":"midi","s":"off","ch":1,"n":60,"v":0,"ts":123820}
{"t":"control","ch":1,"c":64,"v":127,"ts":123500}
```

`ch` 为 1–16，`n/v/c` 为 0–127，`ts` 是 USB 回调微秒时间戳换算出的 ESP32 启动后毫秒数。若 PX-S7000 启用了 High-Resolution Velocity MIDI Out，固件会把同通道 CC88 低 7 位与下一条 Note On/Off 的 `v` 合成为可选 `vh`（0–16383）；原始 CC88 仍单独转发，所以标准 MIDI 录制可无损往返。旧客户端可忽略 `vh`，Note On 力度 0 仍归一化为 Note Off。CC120/123 会清除本地按键状态。

## 目标灯与校准

目标是音符语义而非像素帧：

```json
{"t":"target","notes":[{"n":60,"h":1},{"n":48,"h":0}]}
```

`h=0` 为左手，`h=1` 为右手。网页每 250 ms 检查一次、至少每 1 秒重发当前非空集合；ESP 3 秒未收到目标则清除。校准使用 `config`、`keyOffset`、`test` 和 `blackout`；全局及逐键参数均由固件再次限幅并持久化。

## MIDI OUT 排程

跟随模式、乐谱所选声部示范和刚录演奏回放都发送相对于接收时刻的事件，不让手机逐音承担实时调度：

```json
{
  "t":"midiOut",
  "events":[
    {"delay":0,"s":144,"d1":48,"d2":90},
    {"delay":420,"s":128,"d1":48,"d2":0}
  ]
}
```

- `delay` 为 0–60000 ms；状态字节只接受 0x80–0xEF 的通道消息，数据字节限 0–127。
- 全谱示范与录音回放只前瞻 1.5 s，约每 0.65 s 补充；Note On 和 Note Off 分别按各自时刻进入后续时间窗，因此超过 60 s 的长音不会因 `delay` 上限被提前断开。从曲中开始时会恢复 CC64 状态，但不会为已经错过起点的音符发送孤立 Note Off。
- 录音直接回放保留 1–16 通道、力度与 CC64/66/67；其他 CC 仍保留在导出的标准 MIDI 中，但不自动回写到 PX-S7000，避免意外改变音量或音色。
- 单条网页消息最多发送 48 个事件；固件总排程固定为 256 个，USB OUT 固定队列为 128 个 USB-MIDI 事件包。
- ESP 回复 `midiOutResult`，包含 `ok`、`accepted` 与当前 `queued`；周期 `status` 是最终诊断真相。
- 同一时刻只有一个 WebSocket 客户端可持有 MIDI OUT；其他页面收到 `busy=true`。持有者复位、熄灯或断开即释放并先执行全音符关闭，避免两台手机重复伴奏。
- 固件观察 80 ms 内与刚发送伴奏完全相同的消息并累计 `usbOutputMirrorCandidates`，但仍把它当真实输入交给灯光与判分。PX-S7000 官方实现没有定义 MIDI Thru；在无法区分真实齐奏与设备镜像时，静默吞键比保留可诊断输入更危险。
- `{"t":"midiPanic"}` 只允许当前持有者执行；`blackout` 是任何页面都可触发的总急停。持有者断开、练习复位或末尾伴奏释放时会清空待排程并向 16 个通道发送 CC64=0、CC123=0。

## 延迟探测与网络配置

网页发送 `{"t":"ping","ts":1234}`，ESP 回复 `{"t":"pong","ts":1234,"deviceTs":5678}`。`ts` 原样回显浏览器 `performance.now()` 的整数毫秒令牌，`deviceTs` 是 ESP 处理请求时的 uint32 启动后毫秒数。网页只接受与当前请求匹配的回复，在近期 12 个有效样本中选往返时间最低者，以请求/回复中点估计两端单调时钟偏移；半个 RTT 是当前同步误差上界。算法处理约 49.7 天回绕、ESP 重启、超过 2 秒的同步样本和超过 5 秒的排队事件。旧固件不返回 `deviceTs` 时仍可显示 RTT，但判定与录音明确退回消息到达时刻。

这个同步只消除网络到达抖动对网页判定和录音时间线的污染，不等同于按键到灯光延迟。家庭 Wi-Fi 上的 WebSocket 控制使用当前管理密码做首次会话认证；家庭 Wi-Fi 凭据本身仍不能通过 WebSocket 修改。`POST /api/wifi` 在家庭 LAN 与设备 SoftAP 上都在 `X-NoteFall-Admin` 头再次核对当前管理密码；SSID 为 1–32 个 UTF-8 字节，密码为空或 8–63 个 UTF-8 字节。热点新密码同样按 UTF-8 字节计数，网页与固件使用同一边界，避免多字节字符在两端判定不一致。ESP 始终保留 `NoteFall-88` 热点作为恢复入口。

`midiDispatchLatency*` 测量 USB Host 传输回调收到事件到固定实时任务开始消费的区间；`ledInputLatency*` 继续测到对应 SPI 灯帧发送完毕。USB daemon 和 MIDI client 已拆为两个任务，client 事件等待上限由 20 ms 缩到 5 ms；收到包后直接唤醒 Core 0 实时任务。固件先排空同一批 USB 事件，再只发送一帧，所以和弦不会逐音重复刷灯；该帧先于任何 WebSocket 广播，网络和 JSON 只在 Core 1 的 Arduino 主任务执行。

176 灯 APA102 帧固定为 719 字节（4 字节起始、704 字节像素、11 字节结束），仍以 8 MHz、BGR、同一 5-bit 全局亮度发送，理论线时约 719 µs。实现由 719 次逐字节调用改为一次硬件 SPI 批量调用；状态未改变时不再每 10 ms 重发相同帧。USB client 先把整个 transfer 入队再只唤醒一次优先级更高的实时任务，因此同批和弦仍合成一帧，持续输入也不会饿死灯光任务。浏览器事件使用独立 128 项固定队列，每轮最多发 12 项，溢出计入 `webMidiDropped` 并用现有全通道 `control` CC64/66/67/123 加当前按键 `midi` 事件重同步；因此旧版协议 v6 客户端也能恢复且不会因漏掉 Note Off 或踏板释放永久挂键。此指标不包含 PX-S7000 自身键盘扫描、USB 传输前半段与 LED 光电响应，不能替代 120 fps 端到端视频，但能定位固件、SPI、网络或任务阻塞。

## 演进规则

- 增加可选字段不提升协议版本；改变字段含义、单位、限幅或安全行为必须提升版本。
- 固件不得信任网页校验；网页不得假定某台钢琴一定存在 MIDI OUT。
- 新的高频数据流不得放入 USB 回调直接调用网络库，必须经过固定容量队列。

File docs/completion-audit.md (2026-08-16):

# 工程完成度审计

本表按项目原始交付范围逐项区分“数字证据已经证明”和“必须依赖实物”。自动测试、照片估算与实际装机不是同一种证据；只有对应门禁通过，才能升级发布称谓。

当前判定以 **latest automated suite** 为准，不再在审计文档冻结会随回归覆盖增长的测试数量、固件占用率或资源字节数。当前 CI 必须让 Python、Web、Chromium/WebKit 真浏览器、生产构建、离线分发校验和适用的原生/固件构建一起通过；可审计的性能数字、证据类型与实物边界见 [English quality and performance evidence](en/quality-and-performance.md) 及 `release-readiness.md`。

| 交付要求 | 当前设计与证据 | 判定 |
|---|---|---|
| 单条 88 键实体灯带 | 176 像素 APA102C/SK9822；实物为 `32 + 72 + 72` 三段焊接串行链；参数源 `config/system.json`；生成器纳入两个焊缝额外间距并验证 88 键映射唯一 | 分段数量已由实物确认；焊缝中心距和电气可靠性待台架复核 |
| PX-S7000 实时链路 | 原生 ESP32-S3 USB Host、双向 USB-MIDI、每通道 CC88/14 位力度、USB IN/OUT 各 128 项、网页 128 项与排程 256 项固定队列、Core 0 优先级 7/6144 B 栈实时任务、断线急停、疑似输出镜像只诊断不吞输入；USB 回调只入队并唤醒；实时任务把同批按键合成单个 719 B/8 MHz SPI 帧后，Core 1 才广播网页；USB 回调采集时间经最低 RTT 单调时钟同步用于网页判定和录音；内部延迟、同步误差和网络路径分别诊断；丢包、真正坏包和传输错误分开计数；枚举/传输最后原因进入网页与验收报告 | 官方 MIDI 路由、Xtensa 编译、顺序门禁，以及固件共用纯 C++ 核心在主机上对全通道消息、CIN 边界、合法系统消息、CC88、回绕、真实映射和 MIDIStreaming 多种描述符的执行测试已证明；Web 测试另覆盖同步最低 RTT、uint32 回绕、设备重启、异常/过旧消息与旧固件降级；实机端点、CC88 开关、镜像计数和延迟数值待验 |
| USB 与供电拓扑 | [ADR-001](decisions/001-native-usb-host-and-vbus.md)、H5/H7、3A 总保险、单 5V 电源 | 原理图与线束已证明；实物极性/枚举待验 |
| 灯带驱动与安全 | 74AHCT125、100Ω 串阻、8MHz SPI、亮度 4/31 硬上限、3秒失联熄灯 | 代码/预算已证明；克隆灯带电流与温升待验 |
| Core / Studio 界面 | Core 响应式本地网页；Studio 独立 PWA 与 Capacitor Android/iOS 工程、设置面板内可配置 Core 地址、版本化全资源预缓存、单谱面/单瀑布流/谱面+瀑布流分屏、画面内一键全屏与可记忆的播放自动全屏、平台全屏与应用内沉浸降级、2.8/4.2/6.5 秒可调演奏视野、逐音且反复安全的手别彩色谱面光标、谱面内即时判定、可点击的反复安全小节练习热力带、稳定阅读带自动翻谱、72 段双手全曲指纹、目标力度、和弦星座与谱面踏板提示编码、原生 App 生命周期监听；Android 硬件加速原生瀑布流 View 以单调时钟本地逐帧绘制，并带逐键命中/错漏和早/准/晚毫秒时序反馈、临近落键跑道、跨手和弦弧线、踏板提示、历史复盘、同谱趋势、小节重开、弱点巡回和跨曲目今日练习；Studio 还可在本地 Worker 离线转换 MSCZ/MSCX/Guitar Pro/KAR，MIDI 保留原事件作判分真值并另存 MusicXML 五线谱伴侣；乐谱可按所选声部经 PX-S7000 音源示范或静音预览，刚录演奏可保留通道/力度/CC64/66/67 直接回放；390×844、1280×900、1600×1068（3:2 平板 CSS 视口）与 3200×2136（1× 极限压力）真浏览器导入 MusicXML/OSMD 回归 | latest automated Web suite、Chromium Core/Studio smoke、WebKit Core smoke、生产构建、Capacitor 双平台同步及 JDK 21/API 36 debug APK 已证明基线；Core/Studio 真浏览器已验证所选声部示范可在无 OUT 时安全静音推进并恢复普通练习；Studio 真浏览器另外完成真实 MSCX 端到端离线转换，以及原生 MIDI→五线谱伴侣、原 MIDI/伴侣同时持久化和本地运行时 URL（无 CDN）断言；反复 MusicXML 真浏览器探针证明 4 个踏板提示进入瀑布流，谱面 CC64 显示 100% / 2/2 / ±20 ms；今日练习实际从本机曲库与历史生成带预计分钟数的队列，算法测试证明短循环与覆盖不足不会冒充整曲掌握。弱点巡回真浏览器探针证明历史会解锁计划、反复展开弱段生成首关、关卡持久化，并把整小节循环/右手/等我弹设置实际落到练习控件；完整覆盖首关全部八个目标音后，连续掌握计数从 0 变为 1，界面明确要求再连续通过一次。3200×2136 沉浸状态实测画面高 2130 px、顶部 3 px，顶栏/控制栏/成绩条均为零布局占位，自动全屏偏好随播放触发并持久化。同小节四分音符光标真浏览器实测横移约 91 px，左右手变化触发光标着色变化；重复播放出现次数分离，但两次均回到同一正确印刷小节。谱面内 -90 ms 探针显示“早 90”并保持在谱面视口内。四播放小节热力探针实测 `clean/weak/untouched/untouched`，当前薄弱段高度 10.5 px、基准带 7 px。跨双谱表 C4/C6 探针在 Chromium Core/Studio 检出 406 个和弦弧线亮像素，在 WebKit 检出 411 个；标准 MusicXML `p`/`fff` 同时落键探针的落键帽峰值亮度差超过 28，且不改变键位几何；-90/+110 ms 探针在 Chromium 和 WebKit 均检出早/晚特征像素。单谱面在 1600×1068 下实测占谱面容器宽度至少 90% 且无横向溢出。自动生成的 48 小节/240 音符双谱表长谱通过自动翻谱；Studio Canvas 72 点采样检出左右手主题色。APK 内含原生瀑布流、全曲指纹、目标力度、和弦星座、踏板与时序反馈和系统栏沉浸桥。iOS 原生瀑布流/签名构建、Android/iOS 热点重开/锁屏/持久化/STA 再认证与自动切网仍待平台或实机验 |
| 乐谱与练习 | MIDI、MusicXML/XML/MXL、OSMD、瀑布流、反复/结尾/跳转、普通/加法/复合/自由拍号、附点速度、普通/附点拍值 metric modulation、25%–200% 五个百分点变速、力度、静默 cue、Realtime/Wait/Follow；等待和弦要求当前物理按住且无持续错键，整组成立前暂存命中并在提前松键时撤销 | 解析、状态机、速度端点/规范化、逐音防作弊和 1016 文件固定版本标准/厂商/谱面引擎语料已证明，含 UTF-16/MXL 与复杂 volta；另有 6 首真实曲目、2638 音符对 music21 的内容级交叉验证，最大起音差 0.109 ms；仍需不同导出器真实双手曲目的显示/演奏人工比对，tuplet metric modulation 与无机器端点的连续渐变是明确边界 |
| 曲库、录制和分析 | IndexedDB、并发去重、SHA-256/规模校验、原子恢复、保留真实 Note Off、CC88 与连续 CC64/66/67 的 MIDI 录制、14 位力度、谱面力度轮廓、物理松键/踏板发声时值、精确起点和弦展开/双手同步、MusicXML 踏板/换踏/半踏评分、4小时/20万事件显式录制上限、带乐谱内容身份的历史、单轮建议和多片段弱点巡回 | 单元测试与生产构建已证明；同名不同谱隔离、反复展开弱点排序、不重叠关卡、左右手选择、连续达标/失败清零、进度恢复、力度/内存边界、同音重触发、断奏门控、踏板往返、逐遍谱面踏板匹配、琶音/残缺和弦拒绝、双手方向、表达/同步/踏板趋势与专项关卡测试通过 |
| 灯位校准 | 三点/全局偏移、反向、88键 ±4 像素微调、NVS 限幅与持久化诊断 | 协议/代码已证明；实际 88 键结果待验 |
| 机械与无损安装 | 照片估算 18-22mm 固定黑色立面；裸灯带竖直朝演奏者；可选 PET 载体；控制盒 STL/STEP | CAD/照片估算已证明；12mm 纸条与24小时胶贴待验 |
| 光学与弹奏影响 | 无高位全长打印盒；灯珠靠近白键后缘，无遮挡裸露发光 | 几何方向已定义；眩光、键面照度和全行程干涉待验 |
| 可制造电气系统 | BOM、逐线 `harness.csv`、线色/线径/端接、Micro-Fit/XT30、双端注电、压降预算 | 文档/计算/打包已证明；第三方线束成品待验 |
| 控制盒 | 112×76×25mm PETG 参数化托盘和螺钉盖，STL/STEP/渲染/哈希清单 | 数字制造文件已证明；打印装配待验 |
| 更新、诊断与恢复 | 双 OTA、LittleFS、热点本地再认证、STA 控制再认证、默认密码验收门禁、版本化报告、USB IN/OUT 队列深度/高水位与最大批次、回调→MIDI 分发及回调→LED SPI 完成 last/avg/max、LED SPI last/max/帧数/跳帧、网页 MIDI 队列深度/高水位/丢弃/重同步、实时任务 ready/WDT/心跳/唤醒/空闲栈、主循环 last/max，以及双端拒绝数/认证失败数/内存/NVS/复位原因诊断 | 自动测试、固件构建与镜像反查已证明；家庭网络与重叠子网实机待验 |
| 文档与开源发布 | MIT 源码、第三方声明、开源对标、装配/烧录/测试说明、制造/OTA/单文件首刷包脚本、草稿 PR；首刷脚本校验板型/大小/SHA-256 且不猜串口，LICENSE 与第三方声明随三类 ZIP 分发 | 仓库/PR/CI 已证明；只允许先发明确标注 G1/G2 未完成的 Pre-release，正式硬件版标签待 G1/G2 |
| 隐私 | 银行卡现场照片未进入仓库/制品；制造清单显式 `privateSourcePhotosIncluded=false` | Git 路径审计与打包测试已证明 |

## 当前发布判定

- G0 数字工程：通过，允许生成 release candidate；
- G1 台架：缺 ESP32、最终线束和灯带实测；
- G2 装琴：缺 PX-S7000 USB 枚举、88 键、温升、延迟、眩光与无损安装实测；
- 因此 PR 保持草稿，不能把当前版本称为“硬件验证版”或“量产验证版”。

详细门禁与阈值见 [发布候选门禁](release-readiness.md) 和 [完整测试流程](testing.md)。

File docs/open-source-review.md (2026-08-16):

# 钢琴灯光与 MIDI 可视化开源项目技术调研

> 调研快照：2026-08-05
> 适用项目：NoteFall 88 / Casio PX-S7000 单排实体灯带辅助系统
> 目的：确认哪些成熟设计值得吸收、哪些技术债不应继承，并据此固定本项目的硬件和软件边界。

## 1. 结论先行

没有一个现有项目能原样满足本项目，但下列项目分别解决了不同问题。2026-08-05 的二次审计确认 Piano Trainer Studio 有公开源码和明确的 AGPL-3.0 许可证；此前把它写成“不可审计、未明确授权”是错误的，本版已经纠正：

| 最值得参考的部分 | 对应项目 | 原因 |
|---|---|---|
| **第一软件/产品参考** | [Piano Trainer Studio](https://github.com/ztbishop/piano-trainer-studio) | MusicXML 谱面、三种练习模式、左右手、循环/变速/移调/得分、IndexedDB 曲库和逐键 LED 校准已形成完整产品闭环 |
| 最接近的硬件拓扑 | [PianoLux ESP32](https://github.com/serifpersia/pianolux-esp32) | 已验证 ESP32-S2/S3 可同时承担 USB MIDI Host、Wi-Fi 网页和单排灯带控制 |
| 最完整的实体灯带产品流程 | [Piano-LED-Visualizer](https://github.com/onlaj/Piano-LED-Visualizer) | 曲库、练习、录制、校准、配置、网页控制和独立运行最完整 |
| 最可靠的 ESP32 MIDI 输入参考 | [ESP32_Host_MIDI](https://github.com/sauloverissimo/ESP32_Host_MIDI) | USB 枚举、端点解析、断线恢复、事件队列和测试覆盖最有价值 |
| 最好的瀑布流与桌面练习交互参考 | [Openthesia](https://github.com/ImAxel0/Openthesia) | 播放时钟、等待练习、左右手配色、速度控制和录制交互成熟 |
| 浏览器 MIDI 文件解析 | [Tonejs/Midi](https://github.com/Tonejs/Midi) | 能正确处理 tempo map，避免重复编写容易出错的 SMF 时间换算 |

因此 NoteFall 88 不会复制其中某一个项目，而采用组合后的架构：

```mermaid
flowchart LR
    P["PX-S7000<br/>USB-MIDI"] -->|"USB 2.0 Full Speed<br/>ESP32-S3 为 Host"| E["ESP32-S3 N8R8"]
    E -->|"硬件 SPI：Clock + Data"| L["74AHCT125<br/>5 V 电平转换"]
    L -->|"APA102/SK9822 协议"| S["单条 5 V、144 LED/m 灯带"]
    PSU["独立 5 V 电源<br/>保险丝 + 分段注电"] --> S
    U["手机 / 平板 / 电脑<br/>同一套响应式界面"] <-->|"本地 Wi-Fi<br/>HTTP + WebSocket"| E
```

关键区别是：**琴键到实体灯的实时路径走钢琴到 ESP32 的 USB 直连，不经过 Wi-Fi。** ESP 仍把带 USB 回调时间戳的按键事件广播给界面；网页用最低 RTT 时钟同步恢复硬件采集时刻，所以网络到达抖动不直接污染判分与录音。灯带采用带时钟线的 APA102/SK9822，而不是参考项目中常见的 WS2812；这让刷新时序更可控，也更适合 ESP32-S3 同时处理 USB 和网络任务。

## 2. 调研方法与代码规模

本报告不是只阅读项目首页。调研时固定到以下源码快照，检查了入口、依赖、硬件说明、MIDI 输入、灯带驱动、网络服务、状态存储和许可证：

| 项目 | 调研提交 | 许可证 | 近似非空源码行数¹ |
|---|---|---:|---:|
| Piano Trainer Studio | [`9b21d7e`](https://github.com/ztbishop/piano-trainer-studio/tree/9b21d7e7277aa1da8d82b3d67fe036bfccd11e81)（v1.2.4） | AGPL-3.0 | 自写 JS/CSS/HTML/Helper 约 15,720；另含第三方资源 |
| Piano-LED-Visualizer | [`b567fd1`](https://github.com/onlaj/Piano-LED-Visualizer/tree/b567fd1237fa) | MIT | 约 32,000 |
| PianoLux ESP32 | [`2a9d10c`](https://github.com/serifpersia/pianolux-esp32/tree/2a9d10c3c744) | MIT | 约 5,700 |
| ESP32_Host_MIDI | [`dea1578`](https://github.com/sauloverissimo/ESP32_Host_MIDI/tree/dea1578d596a)（v7.2.0） | MIT | 核心约 5,100；含示例/测试约 12,700 |
| Openthesia | [`04d6e37`](https://github.com/ImAxel0/Openthesia/tree/04d6e378f178) | GPL-3.0 | 约 7,600 |
| NoteFall 88 当前工程基线 | 本仓库 | MIT Core；Studio 组合发行物 GPL-3.0 | 超过 8,500 行非空原创代码与测试；345 项自动测试（71 Python/工程 + 274 Web，含固件共用纯 C++ MIDI/USB 描述符核心的主机编译执行），显式 Web 模块覆盖率门限进入 CI，另有 1016 文件 MusicXML/MXL 固定语料审计、Studio 本地 Worker 高级格式转换和 MIDI 五线谱伴侣、ESP/浏览器单调时钟同步、逐和弦局部拍速自适应判定与快速同音防串匹配、目标力度基准/轮廓、物理松键/CC64 发声时值、和弦展开/双手同步、MusicXML 踏板提前提示/时机/半踏深度评分与专项关卡、乐谱所选声部示范和录音立即回放、48 小节真浏览器自动翻谱、逐音/反复安全谱面光标、可点击的小节热力带、循证弱点巡回、跨曲目间隔复习队列、全曲指纹、跨双手和弦星座、目标力度与早/晚反馈 Canvas 像素门禁；控制面采用 SoftAP 自动授权、STA 会话再认证与默认密码验收门禁 |

¹ 这是用相同规则排除依赖目录、构建产物和压缩文件后的物理非空行近似值。翻译表、生成代码、示例和测试都会显著改变数字，所以代码行数只能说明项目体量，不能代表功能质量。

## 3. 总体对比

### 3.1 硬件与通信拓扑

| 项目 | 主控/运行设备 | 钢琴如何接入 | 灯带如何接入 | 界面如何通信 | 是否依赖云端 |
|---|---|---|---|---|---|
| Piano Trainer Studio | 浏览器；可选 PC/Mac 本地 helper | USB/蓝牙 MIDI → 浏览器 Web MIDI；iOS 需 MIDIWeb | 浏览器以 HTTP JSON 发 WLED；低延迟 DDP 经 helper；或输出到 MIDI LED 设备 | 浏览器本地处理；WLED/helper 走局域网 | 否，但移动端可能依赖辅助 App/电脑 |
| Piano-LED-Visualizer | Raspberry Pi Zero / Zero 2 W | USB-MIDI，经 Linux ALSA、mido、python-rtmidi | GPIO18 驱动 WS281x，灯带独立 5 V 供电 | Flask/Waitress HTTP + WebSocket；Wi-Fi 热点或家庭网络 | 否 |
| PianoLux ESP32 | ESP32-S2/S3 | 原生 USB Host；也提供 BLE MIDI、RTP-MIDI 等替代入口 | GPIO + RMT/FastLED 驱动 WS2812 | ESPAsyncWebServer HTTP + WebSocket；AP/STA/mDNS | 否 |
| ESP32_Host_MIDI | ESP32-S2/S3/P4 等 | USB Host、BLE、RTP-MIDI、DIN UART、ESP-NOW 等可选 | 不包含灯带 | 只提供 MIDI 传输 API，不包含成品界面 | 否 |
| Openthesia | Windows 电脑 | 操作系统 MIDI 设备接口 | 不包含实体灯带 | 本机桌面 UI；无 ESP32 网络协议 | 否 |
| **NoteFall 88** | **ESP32-S3 N8R8 + 手机/平板/电脑浏览器** | **PX-S7000 USB-MIDI 直连原生 USB Host** | **硬件 SPI + 74AHCT125 驱动 APA102/SK9822** | **本地 HTTP + WebSocket；AP/STA** | **否** |

### 3.2 功能矩阵

符号含义：● 已有；◐ 部分支持或需组合使用；— 不属于该项目。

| 功能 | Piano Trainer Studio | Piano-LED-Visualizer | PianoLux | ESP32_Host_MIDI | Openthesia | NoteFall 88 目标 |
|---|:---:|:---:|:---:|:---:|:---:|:---:|
| 按下琴键即时亮灯 | ● | ● | ● | 仅输出 MIDI 事件 | ◐ 屏幕显示 | ● |
| MusicXML/MXL 谱面 | ● | — | — | — | — | ● |
| MIDI 文件预提示 | ●，先转换为 MusicXML | ● | ● | — | ● | ● |
| 等待用户弹对再继续 | ● | ● | ◐ | — | ● | ● |
| Follow Me 左右手伴随 | ● | ◐ | — | — | ◐ | ● |
| 屏幕瀑布流/谱面跟随 | ● 谱面跟随 | ◐ | ◐ | — | ● 瀑布流 | ●，单谱面/单瀑布流/分屏、稳定阅读带与全曲指纹 |
| 单排 88 键实体灯带 | ●，经 WLED/MIDI 设备 | ● | ● | — | — | ● |
| 用户校准灯位/方向 | ●，逐键偏移 | ● | ● | — | — | ●，几何模型 + 必要时逐键微调 |
| 曲库与上传管理 | ● IndexedDB/备份 | ● | ● | — | ● | ● |
| 循环、速度、左右手、移调 | ● | ● | ◐ | — | ● | ● |
| 录制与回放 | — | ● | — | 提供事件能力 | ● | ●，标准 MIDI 导出 + PX-S7000 直接回放 |
| 乐谱所选声部示范 | ● | ◐ | ◐ | 提供事件能力 | ● | ●，钢琴音源/静音预览双路径 |
| 逐音节奏/力度洞察与本地历史 | ◐ 得分/统计 | ◐ | — | — | ◐ | ●，有符号时序、P95、力度基准/轮廓/趋势、难点键、版本化导出 |
| 物理松键、踏板发声时值与释放训练 | — | ◐ 录制 Note Off/CC | — | — | — | ●，CC64 分离、断奏门控、复盘/趋势/教练/关卡 |
| 和弦展开与左右手同步训练 | — | — | — | ◐ 和弦聚合 | ◐ 视觉和弦 | ●，完整和弦评分、方向诊断、复盘/趋势/教练/关卡 |
| MusicXML 踏板时机与半踏深度训练 | — | — | — | — | — | ●，逐动作/逐遍评分、复盘/趋势/教练/关卡 |
| 可解释的自适应练习建议 | — | — | — | — | — | ●，SHA-256 同谱历史驱动片段/声部/模式/速度，一键应用且同名文件不串曲 |
| 多片段掌握路线与连续达标进阶 | — | — | — | — | — | ●，反复展开小节聚合、非重叠关卡、失败清零与本机恢复 |
| 乐谱拍号/变速感知节拍器与预备拍 | ● | ◐ | — | — | ◐ | ●，MIDI/MusicXML 统一拍点、Web Audio 提前调度 |
| OTA 固件升级 | — | — | ● | — | — | ● |
| 手机/平板友好界面 | ◐；iOS 有 MIDI/WLED 限制 | ◐ | ◐ | — | — | ● |
| USB 断线自动恢复 | 由浏览器/系统处理 | ◐ | ◐ | ● | 由操作系统处理 | ● |
| 自动化测试 | 未见完整自动化套件 | 较少 | 较少 | ● | ◐ | ● |

## 4. Piano-LED-Visualizer

### 4.1 它是什么

这是参考项目中最接近“可长期放在钢琴上使用的完整设备”的方案。它把 Raspberry Pi 变成一台独立灯光主机，既能监听钢琴实时 MIDI，也能从本机曲库播放 MIDI 并执行等待练习。

```mermaid
flowchart LR
    P["钢琴 USB-MIDI"] --> H["USB OTG Hub"] --> R["Raspberry Pi<br/>ALSA + Python"]
    R -->|"GPIO18 / WS281x 单线"| LED["WS2812B 灯带<br/>独立 5 V 电源"]
    R <-->|"HTTP / WebSocket<br/>Wi-Fi AP 或家庭网络"| B["手机/平板/电脑浏览器"]
    R --> SD["SD 卡曲库、设置、录音"]
    R -.可选.-> LCD["Waveshare LCD HAT<br/>按键/摇杆"]
```

### 4.2 实现功能

- 实时 MIDI 灯光、力度与延迟熄灭效果、背景光和多种颜色模式。
- MIDI 文件上传、重命名、删除、播放、录制和下载。
- 等待练习、左右手/音轨选择、速度控制、灯光预提示。
- 灯带方向、起始音、偏移、反转、像素密度等校准。
- 浏览器管理界面、WebSocket 实时状态、LED 模拟器。
- 可选 LCD HAT，使设备在不打开手机的情况下运行。
- 可与 Synthesia 等外部软件通过 Linux MIDI 端口配合。

### 4.3 优点

1. **产品闭环最完整。** 它证明用户真正需要的不只是“一个音符对应一个灯”，还包括曲库、持久配置、恢复播放、练习状态、录音和诊断。
2. **硬件资料丰富。** 电源、GPIO、灯带密度、可选铝槽/扩散件、保护壳和热点配置都有现成经验。
3. **独立运行能力强。** 断开互联网后仍能工作，符合乐器附件的预期。
4. **MIT 许可证宽松。** 可在保留版权与许可证的前提下研究或复用局部思想。

### 4.4 缺点

1. **Raspberry Pi 对本项目偏重。** Linux、SD 卡、系统服务、Python 依赖和 USB Hub 增加了成本、启动时间、维护面和故障点。
2. **实时链路更长。** 数据要经过 USB、Linux ALSA、Python 事件循环再到 WS281x 驱动。它可以达到可用体验，但比 ESP32 裸机路径更难做到完全确定的时序。
3. **WS281x 是无时钟单线协议。** 刷新期间对时序要求严格；本项目还要并发 USB Host 与 Wi-Fi，因此选择带独立时钟的 APA102/SK9822 更稳妥。
4. **工程形态较“树莓派应用”。** root/systemd、系统镜像、SD 卡写入和多进程端口不适合我们想要的插电即用小控制盒。
5. **键位映射仍以偏移和比例校准为主。** 它没有成为 PX-S7000 真实白键/黑键中心的参数化几何模型。

### 4.5 我们具体学习什么

- 曲库的“上传—检查—播放—练习—录制—导出”完整生命周期。
- 设备配置持久化、配置档案、恢复默认值和状态诊断页面。
- 等待练习状态机、左右手/音轨过滤、速度与循环交互。
- MIDI 端口断开重连、录音事件时间戳和浏览器 LED 模拟器。
- 首次开机热点、局域网发现和不依赖云端的产品原则。

不会照搬 Raspberry Pi/Linux 主机、WS281x 驱动、LCD HAT、root 服务和整套旧网页。

## 5. PianoLux ESP32

### 5.1 它是什么

PianoLux 是与 NoteFall 88 **硬件结构最接近**的参考：ESP32-S2/S3 直接作为 USB Host 读取数码钢琴，同时自己提供 Wi-Fi 网页并驱动最多约 176 个 WS2812 像素。

```mermaid
flowchart LR
    P["钢琴 USB-MIDI"] -->|"原生 USB Host"| E["ESP32-S2/S3"]
    BLE["BLE MIDI"] -.可选.-> E
    RTP["手机/电脑 RTP-MIDI"] -.可选 Wi-Fi.-> E
    E -->|"RMT/FastLED 单线"| LED["WS2812 灯带"]
    E <-->|"HTTP :80<br/>WebSocket :81"| UI["浏览器"]
    E --> FS["LittleFS<br/>设置与 MIDI 文件"]
```

### 5.2 实现功能

- ESP32-S2/S3 原生 USB MIDI Host。
- 备选 BLE MIDI 客户端和 AppleMIDI/RTP-MIDI 网络输入。
- AP 配网、家庭 Wi-Fi、mDNS、本地网页与 WebSocket 实时控制。
- 颜色、亮度、力度、淡出、背景光、分区和动画效果。
- 灯带反转、键盘尺寸、偏移和 1:1/1:2 像素映射。
- LittleFS 文件存储、MIDI 文件播放、OTA 和 WebSerial 诊断。

### 5.3 优点

1. **证明了核心组合可行。** ESP32-S3 可以同时做 USB Host、Wi-Fi 服务和灯带控制，不需要再加 MAX3421E USB Host 芯片。
2. **成本低、启动快、设备简单。** 没有 Linux、SD 卡和后台服务。
3. **网络接入方式适合乐器附件。** AP/STA、mDNS、WebSocket 和 OTA 都能迁移为我们的设备管理能力。
4. **实现体量可控。** 相比树莓派方案，更容易做成真正的嵌入式产品。

### 5.4 缺点

1. **主固件和网页都较集中。** 大型 `.ino` 与单个约 2,200 行的网页脚本会逐渐难以测试和维护。
2. **兼容分支较多。** USB、BLE、RTP-MIDI、多种芯片和多种启动模式混在同一产品中，会扩大故障面。
3. **仍使用 WS2812。** RMT 能改善驱动，但灯带刷新仍是严格时序的单线操作；本项目用硬件 SPI 更容易隔离实时任务。
4. **键位映射以线性索引、整体偏移和修正值为主。** 这在“看起来大致对齐”时够用，但不能保证每个白键/黑键实际中心的误差最小。
5. **工程发布流程偏开发者。** Arduino IDE、板型条件编译和部分手工配置不够适合普通用户的一键升级。

### 5.5 我们具体学习什么

- ESP32-S3 原生 USB Host 与 Wi-Fi 同机并发的任务划分。
- AP 首次配网、STA 正常使用、mDNS 发现和 WebSocket 状态同步。
- OTA、LittleFS 曲目上传和网页端设备诊断。
- 把 ESP32 作为唯一硬件主控，而不是再加入树莓派。

不会照搬 WS2812/RMT、巨型单文件结构、所有备用 MIDI 传输方式以及线性键位映射。

## 6. ESP32_Host_MIDI

### 6.1 它是什么

它不是完整钢琴灯光产品，而是一套 ESP32 MIDI **传输与事件库**。它最有价值的部分是把多种物理传输统一成 MIDI 事件，并处理 USB 设备枚举、断线、队列和 MIDI 1.0/2.0 数据格式。

```mermaid
flowchart LR
    USB["USB Host MIDI 1.0/2.0"] --> Q["统一事件队列"]
    BLE["BLE MIDI"] --> Q
    RTP["RTP-MIDI<br/>Wi-Fi/Ethernet"] --> Q
    DIN["DIN-5 / UART"] --> Q
    NOW["ESP-NOW / OSC"] --> Q
    Q --> APP["用户应用逻辑<br/>项目本身不自动路由"]
```

### 6.2 实现功能

- ESP32-S2/S3/P4 的 USB Host MIDI 1.0 与 MIDI 2.0 UMP。
- BLE MIDI、AppleMIDI/RTP-MIDI、ESP-NOW、OSC、UART/DIN-5 和可选以太网。
- 线程安全事件队列、活动音符跟踪、和弦聚合、力度过滤、SysEx 和历史记录。
- 设备连接/断开处理、示例工程和针对解析/队列行为的测试。

### 6.3 优点

1. **最难的底层问题覆盖最好。** USB 描述符、接口/端点识别、传输回调、异常包和设备移除都比普通示例完整。
2. **事件模型值得采用。** 上层灯光和练习逻辑不应直接依赖 USB 原始包，而应消费统一的 Note On/Off 等事件。
3. **测试价值高。** 和弦、队列、MIDI 2.0、过滤器和边界数据都有可复用的测试思路。
4. **MIT 许可证。** 可以在履行许可证要求后采用经过裁剪的实现思想。

### 6.4 缺点与一个需要纠正的上游说法

1. **功能范围远超本项目。** 把 BLE、ESP-NOW、OSC、RTP-MIDI、以太网和 MIDI 2.0 全部编入首版，只会增加 Flash/RAM、依赖和回归测试成本。
2. **它不包含灯光、网页、曲库或练习逻辑。** 不能把这个库误认为完整方案。
3. **文档中关于“USB Host 与 Wi-Fi/BLE 不能同时运行”的表述不准确。** ESP32-S3 的共享关系是内部 USB PHY 在 **USB-OTG 与 USB-Serial/JTAG** 之间共享，不是与 Wi-Fi/BLE 射频共享。Espressif 的[官方 USB Host 文档](https://docs.espressif.com/projects/esp-idf/en/stable/esp32s3/api-reference/peripherals/usb_host.html)和[ESP32-S3 数据手册](https://documentation.espressif.com/esp32-s3_datasheet_en.pdf)都把 Wi-Fi/BLE 与 USB OTG 列为独立外设。PianoLux 的实际架构也旁证了 USB Host 与 Wi-Fi 可以并发。

这意味着本项目可以让 ESP32-S3 同时连接 PX-S7000 和手机 Wi-Fi；需要避开的只是让同一个内部 USB PHY 同时承担 OTG Host 与 USB-Serial/JTAG。开发日志/刷机使用开发板独立的 UART 桥接口即可。

### 6.5 我们具体学习什么

- USB MIDI 1.0 枚举、端点筛选、输入包解析和断线重连。
- USB 回调只负责入队，灯光、练习和网络任务消费规范化事件。
- 活动音符集合、队列溢出计数、异常包诊断和可重复单元测试。
- 为未来 MIDI 2.0 留事件字段，但首版不启用不必要的传输后端。

当前策略不是把整个库直接塞进固件，而是保留一个项目专用、可测试的 `UsbMidiHost` 子集；这样既吸收成熟边界处理，又避免把未使用功能变成维护负担。

## 7. Openthesia

### 7.1 它是什么

Openthesia 是 Windows 桌面端的开源 Synthesia 类软件。它从操作系统 MIDI 设备读取键盘事件，在 GPU 界面中显示瀑布流，并可用 SoundFont/VST 发声。它没有 ESP32，也不控制实体灯带。

```mermaid
flowchart LR
    P["USB MIDI 键盘"] --> OS["Windows MIDI 设备"] --> O["Openthesia C#"]
    F["MIDI 文件"] --> O
    O --> GPU["Veldrid / ImGui<br/>屏幕瀑布流"]
    O --> A["NAudio / SoundFont / VST2<br/>本机音频"]
```

### 7.2 实现功能

- MIDI 文件瀑布流、实时演奏显示和播放控制。
- 等待弹对再继续、速度调整、方向切换和左右手颜色。
- MIDI 录制/导出、SoundFont、VST2、视频录制和主题设置。
- 针对桌面 GPU 的高帧率渲染和音频播放。

### 7.3 优点

1. **练习交互成熟。** 播放时钟、等待状态、音符命中、左右手和速度变化是很好的行为参考。
2. **屏幕渲染职责清楚。** MIDI 时间线、输入状态、音频和画面是不同子系统。
3. **适合作为功能上限参考。** 它说明“代码少”不应等于“只做几个按钮”；我们的手机/平板界面也应达到完整练习软件的体验。

### 7.4 缺点

1. **平台和本项目不同。** Windows、GPU、VST、音频插件都不适合直接塞进 ESP32 或手机网页。
2. **没有实体灯带时序和校准问题。** 屏幕像素连续可绘制，而 144 LED/m 灯带只能选择离散物理像素。
3. **许可证是 GPL-3.0。** NoteFall 88 当前采用 MIT；如果直接复制并发布其 GPL 代码，会引入相应的许可证义务。因此只研究公开行为和交互，独立实现，不复制源码。

### 7.5 我们具体学习什么

- 以统一 MIDI 时间线驱动屏幕瀑布流、灯带预提示和等待练习。
- 循环片段、变速、左右手分色、命中判定和录制时间线。
- 屏幕渲染器与硬件灯带渲染器分开：前者追求连续动画，后者只发送当前需要的离散灯位。

不会复制 GPL 源码，也不会引入 VST、Windows API 或电脑端音频合成管线。PX-S7000 自己负责发声，本项目只负责提示和练习状态。

## 8. 两个辅助参考

### 8.1 Tonejs/Midi

[`@tonejs/midi`](https://github.com/Tonejs/Midi) 是 MIT 许可的浏览器/Node MIDI 文件解析库，不是钢琴硬件项目。它的价值是正确解析 SMF 的音轨、tempo map、拍号和音符时值，再转成统一秒时间线。NoteFall 网页端保留这一依赖，但不会使用 Web Audio 合成钢琴声。

它不能替代：

- 实时 USB MIDI Host；
- MusicXML/五线谱排版；
- 练习判定状态机；
- ESP32 灯位调度。

### 8.2 Piano Trainer Studio

[Piano Trainer Studio（PTS）](https://github.com/ztbishop/piano-trainer-studio) 是公开、可审计的 AGPL-3.0 项目，也是 NoteFall 88 的**第一软件/产品参考**。本次审计固定在提交 [`9b21d7e`](https://github.com/ztbishop/piano-trainer-studio/tree/9b21d7e7277aa1da8d82b3d67fe036bfccd11e81)（v1.2.4），而不是只根据在线界面猜测。

#### 已确认的功能与实现

- MusicXML/XML/MXL 是主格式；MIDI、MuseScore 和 Guitar Pro 文件通过 webmscore 转成 MusicXML 后进入同一条处理链。
- OSMD 负责解析与绘制谱面，浏览器游标和谱面数据共同产生目标音符与左右手/谱表归属。
- Realtime、Wait for Me、Follow Me 三种模式已经实现；另有左右手选择、循环、变速、移调、得分、节拍器和反馈标记。
- IndexedDB 保存文件夹、乐谱、原始文件和最近打开时间，并支持批量导入、重命名、移动、删除、完整备份和恢复。
- LED 子系统维护 RGB 帧缓冲、方向/数量配置以及每个 MIDI 键的独立像素偏移；校准可导入和导出。
- 自写 JS/CSS/HTML/Node helper 约 15,720 行。最大的业务文件 `trainer-core.js` 和 `led.js` 分别约 3,600 和 1,900 个非空行，说明它不是只有一层界面的简单演示。

#### 它实际有两路 MIDI/音符数据

```mermaid
flowchart LR
    SCORE["MusicXML / MXL<br/>或转换后的 MIDI"] --> B["浏览器练习引擎<br/>计算参考/目标音符"]
    PIANO["钢琴 USB / 蓝牙 MIDI"] -->|"Web MIDI；iOS 需 MIDIWeb"| B
    B -->|"比较目标与实际演奏"| UI["谱面、得分、练习状态"]
    B -->|"HTTP JSON 像素帧<br/>或 helper → DDP"| WLED["WLED ESP32<br/>通常不解析乐谱"]
    B -.可选.->|"MIDI 输出"| MLED["MIDI LED 设备"]
```

第一路是浏览器从乐谱得到的**参考/目标音符**；第二路是钢琴实际弹奏产生的**演奏音符**。浏览器负责比较两者并生成练习状态。默认 WLED 控制器通常只接收已经算好的像素颜色帧，不知道乐谱、左右手或命中规则。

#### 与 NoteFall 88 的关键差异

PTS 默认要求浏览器自己收到钢琴 MIDI：桌面浏览器使用 Web MIDI；iPhone/iPad 因 Safari/Chrome 不提供 Web MIDI，需要 MIDIWeb。WLED 默认走浏览器 HTTP JSON，低延迟 DDP 需要 PC/Mac helper；官方说明还指出 iOS 的 WLED 使用场景需要 helper。NoteFall 88 则让 PX-S7000 直接接 ESP32-S3，实体按键反馈不经过浏览器或 Wi-Fi，ESP32 再把标准化按键事件发给任意手机/平板页面，因此移动端不需要 Web MIDI 权限。

PTS 的完整发布包本来也不以塞进 WLED 为目标：网页、OSMD、webmscore、曲库和练习引擎通常运行/存储在手机、平板或电脑，WLED 主要收像素帧。审计快照中的 webmscore 资源约 24.2 MB、OSMD 压缩脚本约 1.2 MB，只说明它们不能原样随 NoteFall Core 烧进 2.875 MiB LittleFS，不能作为拒绝 PTS 前端路线的单独理由。Core 已把 OSMD gzip 到约 306 kB 并通过 buildfs；webmscore 现已进入预安装 Studio PWA/原生 App 的离线 Worker，而不占 ESP Flash。

#### 许可证边界与采用结论

PTS 的授权非常明确，但它是 AGPL-3.0，不是 MIT。直接 fork、修改并把它作为网络交互应用发布，需要保留 AGPL 许可/通知，并按 AGPL 第 13 节向远程交互用户显著提供相应源码。把 PTS 主代码并入本仓库，也不能再把组合后的 PTS 衍生前端仅标为 MIT。

本项目因此选择：**PTS 作为第一软件参考，但不 fork、不复制其代码或资源；NoteFall 的 MIT 核心保持独立实现。** 这里是“独立重写/不复制”的工程规则，不声称已经建立由隔离团队执行的法律意义 formal clean room。若未来需要直接修改 PTS，则放在单独的 AGPL 仓库/发行物中，并在发布前做许可证复核。

详细的 fork 与独立实现成本、组件边界和逐项采用计划见 [PTS 采用决策](pts-adoption-decision.md)。

## 9. 映射算法：为什么不能简单“第 N 个键 = 第 N 个灯”

很多开源灯带项目采用如下简化：

```text
led = midi_note - first_note + global_offset
```

或者再加一个整体比例和左右修正。这种方法实现很快，但 88 键钢琴与 144 LED/m 灯带的节距并不相同：

- 灯带像素中心间距约为 `1000 / 144 = 6.944 mm`；
- 白键中心间距约为 23.5 mm；
- 黑键不是等距排列，而且它们的视觉中心与白键序列不同；
- 一枚琴键可能对应相邻 3～4 个像素中的某一个，而不是连续的第 N 个像素。

NoteFall 88 因此采用两层映射：

1. 用参数化键盘几何生成 88 个实际键位中心；
2. 用安装后测得的灯带原点、方向和有效长度，把每个键位中心量化到最近像素，并检查重复、越界和误差。

校准界面只调整少数可理解参数，不让用户手工填写 88 个数字。这样既能适配 PX-S7000 实物误差，也能在换灯带或反向安装后重新生成映射。

## 10. NoteFall 88 固定下来的工程决策

| 决策 | 采用方案 | 从参考项目得到的证据 |
|---|---|---|
| 主控制器 | ESP32-S3 N8R8，不使用 Raspberry Pi | PianoLux 证明单 MCU 拓扑成立；Pi 方案的系统维护成本无必要 |
| 钢琴通信 | PX-S7000 USB-MIDI 直连 ESP32-S3 原生 USB Host | ESP32_Host_MIDI 提供成熟的枚举与队列参考 |
| 手机/平板通信 | 本地 Wi-Fi HTTP + WebSocket | 两个实体灯带项目都证明浏览器管理适合无云设备 |
| 实时边界 | USB MIDI 直接驱动灯光；Wi-Fi 不在按键关键路径 | 避免网络抖动影响即时反馈 |
| 两路音符数据 | 乐谱产生参考/目标音符；ESP32 上报钢琴实际演奏音符；浏览器比较二者 | PTS 证明目标与演奏必须分流，WLED/灯控设备不应承担谱面解析 |
| 灯带 | 一条完整的 5 V、144 LED/m APA102C 或 SK9822 | 比 WS2812 多时钟线，但刷新更确定，两个型号协议兼容 |
| 电气接口 | 3.3 V SPI 经 74AHCT125 转 5 V；灯带独立供电、共地 | 防止 ESP32 直接驱动 5 V 逻辑造成边缘不可靠 |
| 机械安装 | 灯带竖直面向演奏者/琴键方向；不采用全长 3D 打印盒或导轨 | 保留光线直接照到键面的效果，减少高度和遮光 |
| 键位映射 | 参数化真实键位中心 + 少量现场校准 | 改进现有项目常见的线性偏移模型 |
| 软件形态 | ESP32 托管响应式 Web/PWA 核心；需要商店安装时再用 Capacitor 封装 | 一份代码覆盖手机、平板和电脑；ESP 作为 MIDI 网关后，iOS 不需要 Web MIDI/MIDIWeb |
| 软件参考与许可证 | PTS 为第一软件参考；MIT 独立实现，不 fork/复制 AGPL 主代码 | fork 能较快获得成熟功能，但会引入 AGPL 发布义务和 MIDI/灯控拓扑重构；资源可由外部 Studio 承载，不是决定性反对项 |
| 谱面与格式 | 已独立引入 BSD-3-Clause OSMD、MusicXML/MXL 安全解压和统一时间线；MIDI 继续直接解析；Studio 已用独立上游 GPL 包离线转换 MSCZ/MSCX/Guitar Pro/KAR | PTS 验证 MusicXML-first 产品路线；Core 只嵌入日常必需资源，重型转换器在 Studio Worker，不复制 PTS 代码 |
| 练习引擎 | 统一时间线，谱面、屏幕瀑布流和实体灯带使用不同渲染器 | 学习 PTS/Openthesia 的公开行为和状态边界，不复制 AGPL/GPL 代码 |
| 首版传输范围 | 只启用 USB MIDI；BLE/RTP/OSC 等留作未来插件 | ESP32_Host_MIDI 的广度有参考价值，但不是首版需求 |

## 11. 由调研转化出的实现清单

### P0：硬件可靠性与基本闭环

- USB MIDI 枚举、Note On/Off、延音踏板和断线恢复实机测试。
- APA102/SK9822 SPI 驱动、全黑安全启动、总亮度和电流限制。
- 88 键参数化映射、方向/原点校准和映射诊断图。
- ESP32 AP/STA、WebSocket 状态、设置持久化和故障日志。
- 浏览器选择 MIDI 文件，向设备下发带时间戳的预提示事件。

### P1：完整练习产品

- IndexedDB 曲库、文件夹、最近使用、批量导入、删除/重命名、版本化备份与恢复。
- Realtime、Wait for Me、Follow Me、左右手、循环、变速、移调、提前量和倒计时。
- MusicXML/MXL 谱面跟随、屏幕瀑布流、虚拟键盘、实体灯带状态预览和命中反馈。
- 演奏录制、回放、错误统计和可导出 MIDI。
- 逐音时序/力度洞察、难点键、本地历史和可移植导出。
- 手机/平板横竖屏布局、PWA 安装和离线缓存。

### P2：产品化能力

- OTA 固件与网页资源升级、版本回滚和兼容性检查。
- 首次安装向导、电源/灯带方向自检、USB 状态诊断。
- 设备配置备份、多个用户档案、多个键盘/灯带校准档案。
- 如真实需求成立，再评估 Capacitor 原生壳、BLE 或 RTP-MIDI；不提前增加无用分支。

## 12. 最终判断

正确路线不是“找到代码最多的项目然后照抄”，也不是只写一个能点灯的 2,000 行演示：

- 用 **Piano Trainer Studio** 定义 MusicXML-first 谱面、三种练习模式、曲库/备份和 LED 校准的第一产品参考；
- 用 **PianoLux** 证明 ESP32-S3 单主控硬件路线；
- 用 **ESP32_Host_MIDI** 提高 USB 底层可靠性；
- 用 **Piano-LED-Visualizer** 补齐长期使用所需的曲库、校准、录制和诊断；
- 用 **Openthesia** 定义瀑布流、时间线和练习体验的功能上限；
- 结合 PX-S7000、APA102/SK9822 和真实琴键几何，独立实现一个更确定、移动端优先、保留 MIT 边界的系统。

这套取舍保留了成熟项目最难验证的经验，同时避免继承 Linux 主机、WS2812 时序、线性灯位、AGPL/GPL 主代码和无关 MIDI 传输造成的复杂度。PTS 不是“未授权项目”；不 fork 它是经过许可证、硬件拓扑、移动端限制和固件容量共同比较后的主动选择。

## 13. 主要资料

- [Piano Trainer Studio 固定源码快照](https://github.com/ztbishop/piano-trainer-studio/tree/9b21d7e7277aa1da8d82b3d67fe036bfccd11e81)
- [Piano Trainer Studio 官方说明](https://pianotrainerstudio.com/README.html)
- [GNU AGPL-3.0 正文，特别是第 13 节](https://www.gnu.org/licenses/agpl-3.0.en.html)
- [PTS 采用决策：fork 与 MIT 独立实现比较](pts-adoption-decision.md)
- [Piano-LED-Visualizer 源码与安装说明](https://github.com/onlaj/Piano-LED-Visualizer)
- [PianoLux ESP32 源码与接线说明](https://github.com/serifpersia/pianolux-esp32)
- [ESP32_Host_MIDI v7.2.0 源码与示例](https://github.com/sauloverissimo/ESP32_Host_MIDI/tree/dea1578d596a)
- [Openthesia 源码](https://github.com/ImAxel0/Openthesia)
- [Tonejs/Midi 源码](https://github.com/Tonejs/Midi)
- [Espressif ESP32-S3 USB Host 官方文档](https://docs.espressif.com/projects/esp-idf/en/stable/esp32s3/api-reference/peripherals/usb_host.html)
- [Espressif ESP32-S3 数据手册](https://documentation.espressif.com/esp32-s3_datasheet_en.pdf)

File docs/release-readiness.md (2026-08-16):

# 发布候选门禁

NoteFall 88 只有在数字门禁全部自动通过后才能生成候选包；只有实物门禁通过后才能把候选版本改称硬件验证版。

## G0：数字工程（自动）

| 门禁 | 执行方式 | 当前状态 |
|---|---|---|
| 单一参数源与 88 键映射 | `python scripts/generate.py --check` | 通过 |
| CAD 有效、尺寸与哈希一致 | Python 测试 + STL/STEP manifest | 通过 |
| 供电/保险/压降预算 | `generated/power_budget.json` + Python 测试 | 通过 |
| 线束防呆与 SVG 可解析 | `tests/test_hardware_package.py` | 通过 |
| Web 练习/和弦持键与事务记分语义、逐和弦局部拍速自适应判定、快速同音防串匹配、力度基准校正/轮廓、物理 Note Off/CC64 发声时值/常见断奏门控、精确起点和弦展开/左右手同步、MusicXML 踏板/换踏/半踏提示与逐遍评分/趋势/教练/专项关卡、25%–200% 速度规范化、手机后台暂停、设备 WebSocket 握手/重连/STA 再认证/分批、ESP/浏览器单调时钟同步与硬件采集时间判定、节拍器音频生命周期、UTF-8 Wi-Fi 凭据边界、自建 + W3C 固定 MusicXML 语料、数据/长录制资源边界、历史复盘/小节重开、反复安全小节热力导航、循证弱点巡回/连续达标/本机恢复、跨曲目掌握度/防短循环刷分/间隔复习队列、Studio 离线高级格式转换与 MIDI 谱面伴侣、乐谱所选声部示范与录音直接回放的有界 MIDI OUT 排程、可调瀑布流视野、全曲指纹、目标力度与和弦星座视觉编码、早/准/晚逐键时序反馈、逐音/反复安全谱面光标、长谱自动翻页、平台全屏降级与入站协议边界 | Vitest + V8 coverage | 274 项通过；显式纳入除 DOM 主入口和两个浏览器渲染适配器外的全部产品模块，Statements 92.42%、Branches 82.47%、Functions 94.09%、Lines 95.84%，CI 最低门限 85/75/85/90%；排除项由 Playwright 回归 |
| Web / 原生容器供应链 | Web 与 Studio 分别执行 `npm audit --audit-level=moderate`；`cap doctor`、双平台 sync、Android assembleDebug | 0 漏洞；Capacitor 运行时保持 8.5.0，构建 CLI 固定 8.4.2，避开 8.5.0 CLI 的 `xcode → uuid 7.0.3` 中危链；Android 兼容性与构建通过，Xcode/iOS 签名仍只能在 macOS 验证 |
| W3C MusicXML 官方完整语料 | 固定提交 `b2e6a162` + `npm run audit:musicxml` | 150/150 分类完成：149 解析，1 个非法反复文件按预期安全拒绝，0 意外异常 |
| 厂商 MusicXML 功能语料 | MuseScore 官方提交 `d6f84b78` + eNote CC-BY-4.0 提交 `03896bf8` | 447/447 MuseScore 仓库文件无异常；100/100 跨厂商文件分类完成（97 解析、3 预期拒绝），0 意外异常 |
| 谱面引擎互操作语料与示例总谱 | OSMD BSD-3-Clause 提交 `c663e0d3` | 317/317 测试文件 + 2/2 Finale 示例总谱解析，0 意外异常；示例音符数/小节数/时长固定断言 |
| 真实曲目内容级交叉验证 | `music21 9.9.1` + OSMD 固定提交 + `scripts/crosscheck_musicxml.py` | 6 首、2638 个音符：数量与逐音音高序列完全一致；最大起音差 0.109 ms，小于 2 ms 门限 |
| NVS 校准、复位原因与灯先于网络的实时顺序 | Python 源码门禁 + 固件诊断 | 通过 |
| USB-MIDI 包、描述符、CC88 与真实灯位核心 | 固件共用 C++ 头文件由主机 `g++` 编译执行，再由 Xtensa 工具链编入固件 | 全 16 通道与 0x8–0xE 消息往返、CIN/status/data 故障、合法系统消息忽略、CC88 通道隔离/一次消费、`millis()` 回绕、176 像素正反 88 键唯一映射，以及 MIDIStreaming 双向/仅输入/多接口/截断/畸形端点选择通过 |
| 390×844 手机、1280×900 桌面、1600×1068 代表性 3:2 平板 CSS 视口与 3200×2136 物理面板压力布局、STA 控制解锁表单、MusicXML 文件选择器与 OSMD 谱面 | 固定 `@playwright/cli 0.1.17`，Chromium + WebKit 双引擎 `smoke:browser`，GitHub CI 上传截图/快照 | 两个引擎、四个视口均无横向溢出；单谱面至少使用容器宽度 90%；手机练习抽屉和关闭按钮完整位于视口内；设置页真实填写短密码并显示 8–63 字节边界；真实导入 Parser Etude 后显示 4 音符、4 秒与非空五线谱；不把桌面 WebKit 冒充真 iOS 实机 |
| README/装机/制造文档本地链接 | Python 文档门禁 | 全部可解析 |
| 嵌入资源可解析且 `<500 KiB` | Python 资源测试 + `buildfs` 反向列表 | 通过 |
| ESP32 固件链接 | 仓库内固定 N8R8 板型清单 + PlatformIO；项目源码启用 `-Wall -Wextra -Werror` | 精确识别 8 MB Flash + 8 MB Octal PSRAM；RAM 17.2%，Flash 34.8%，零编译警告 |
| OTA、单文件首刷与制造包可重复且许可证随包分发 | 双次打包 SHA-256 相同；factory 镜像组件偏移/分区上限/篡改拒绝、标签与固件版本一致性、LICENSE/THIRD_PARTY_NOTICES 逐文件哈希 | 通过 |
| 私密现场照片不进入发布包 | 制造清单显式为 false + Git 路径审计 | 通过 |

GitHub Actions 在每次 push/PR 重跑 G0，并产出 `notefall88-manufacturing` 工件；合法 `vMAJOR.MINOR.PATCH[-rc.N]` 标签另外产出带 SHA-256 清单的 OTA 包、单文件 N8R8 首刷包与制造包。`-rc.N` 标签强制标为 GitHub Pre-release，且版本号必须与固件一致。

工作流使用 Node 24 运行时的 `checkout@v6`、`setup-node@v6`、`setup-python@v6` 和 `upload-artifact@v6`；GitHub 托管 runner 满足其最低版本，不保留已弃用的 Node 20 Action 运行时警告。

## G1：台架（需要现有 ESP32 与最终线束）

- 断电逐线蜂鸣、5V-GND 无短路、连接器极性与供电侧凹端子；
- 无负载 4.75–5.25 V，3 A 保险拔除后全部下游断电；
- 176 灯在 10% → 固件上限分级点亮，无闪烁、复位或接头发热；
- 5 次 USB 枚举，IN/OUT 端点与诊断计数正确，队列丢包/错误为零；
- 浏览器关闭、Wi-Fi 关闭、USB 拔出、急停、OTA 进入时均熄灯且伴奏不挂音。

## G2：装琴（需要 PX-S7000）

- 12 mm 纸条在 C4 附近全行程不触键、不盖红毡；
- A0/C4/C8 三点后完成 88 键半音阶与必要的逐键校准；
- 全键强奏、轻拉线束、移动谱架均不位移、不异响；
- 固件亮度上限运行 30 分钟，任一点 `<55°C`，灯带两端相对电源入口压降 `≤0.25 V`；
- 120 fps 视频抽查 20 次，按键反馈中位数 `<25 ms`、P95 `<40 ms`；
- 全部 13 项安装向导证据完成并导出报告，其中包含“默认热点密码已修改”的设备自动证据。

## G3：发布判定

- G0 通过：允许创建带 `-rc` 的候选标签；
- G0+G1 通过：允许称“台架验证候选”；
- G0+G1+G2 通过：允许称“PX-S7000 硬件验证版”；
- 未经至少三套独立装机长期回归，不使用“量产验证”字样。

这套命名防止把自动测试、照片估算或单次点亮误写成已经完成的物理可靠性证明。

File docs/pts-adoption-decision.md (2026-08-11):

# Piano Trainer Studio 采用决策

> 状态：已接受  
> 日期：2026-08-05  
> 适用范围：NoteFall 88 网页、固件通信协议、乐谱与练习引擎  
> 审计对象：Piano Trainer Studio [`9b21d7e`](https://github.com/ztbishop/piano-trainer-studio/tree/9b21d7e7277aa1da8d82b3d67fe036bfccd11e81)（v1.2.4，AGPL-3.0）

## 决策

Piano Trainer Studio（PTS）提升为 NoteFall 88 的**第一软件/产品参考**，但本仓库不 fork、不复制 PTS 的源码或网页资源。NoteFall 88 继续采用 MIT，按公开功能和可观察行为独立实现；第三方库单独评估并保留各自许可证。

如果未来决定直接修改 PTS，修改版将进入独立的 AGPL 仓库/发行物，不与当前 MIT 核心混为一个仅标 MIT 的产品。此处是工程许可证边界记录，不替代正式法律意见。

## 为什么必须先做这个决策

PTS 与目标功能高度重合：MusicXML/MXL 谱面、Realtime、Wait for Me、Follow Me、左右手、循环、变速、移调、得分、IndexedDB 曲库/备份和逐键 LED 校准都已经存在。忽略它会重复探索产品行为；直接搬用它又会改变许可证、运行位置和硬件链路。因此在继续曲库、MusicXML 和 Follow Me 之前，必须明确哪些是产品需求，哪些是可复用依赖，哪些不能复制。

## 已审计的 PTS 架构

PTS 的核心计算在浏览器，不在 WLED：

```mermaid
flowchart LR
    SCORE["MusicXML / MXL<br/>MIDI 等先转换"] --> TARGET["浏览器<br/>谱面解析与目标音符"]
    PIANO["钢琴 USB / 蓝牙 MIDI"] -->|"Web MIDI<br/>iOS 需 MIDIWeb"| ACTUAL["浏览器<br/>实际演奏音符"]
    TARGET --> MATCH["练习状态机<br/>命中、等待、跟随、得分"]
    ACTUAL --> MATCH
    MATCH --> UI["谱面与反馈"]
    MATCH --> PIXEL["浏览器 RGB 帧缓冲"]
    PIXEL -->|"HTTP JSON"| WLED["WLED ESP32"]
    PIXEL -->|"localhost helper → DDP/UDP"| WLED
    PIXEL -.可选 MIDI 输出.-> MIDI_LED["MIDI LED 设备"]
```

必须区分两路数据：

1. **参考/目标音符**来自浏览器加载的 MusicXML/MXL，或由 MIDI、MuseScore、Guitar Pro 转换后的 MusicXML。
2. **实际演奏音符**来自钢琴 MIDI 输入。

浏览器比较两路数据。WLED 通常只收最终 RGB 像素帧，不解析乐谱，也不知道左右手和命中规则。PTS 的低延迟 DDP 不是浏览器直接发送 UDP，而是把完整帧 POST 给本机 Node helper，再由 helper 发到 WLED 的 UDP 4048 端口；无 helper 时回退 HTTP JSON。

## NoteFall 的目标拓扑

```mermaid
flowchart LR
    SCORE["MIDI / MusicXML / MXL"] --> B["手机 / 平板 / 电脑浏览器<br/>参考音符、谱面、练习状态"]
    P["PX-S7000"] -->|"USB-MIDI IN"| E["ESP32-S3<br/>实际演奏事件 + 灯光实时层"]
    E -->|"USB-MIDI OUT<br/>跟随伴奏"| P
    E -->|"SPI"| LED["APA102 / SK9822 单排灯带"]
    E -->|"WebSocket：实际演奏音符"| B
    B -->|"WebSocket：语义目标音符"| E
```

与 PTS 相比，NoteFall 把钢琴 MIDI Host 和灯带驱动放在同一台 ESP32-S3：

- 按下琴键后的即时亮灯不经过 Wi-Fi；
- iPhone/iPad/Android 页面不需要 Web MIDI，也不需要 MIDIWeb；
- 浏览器发送的是“哪些 MIDI 音符是目标、显示何种角色”的语义消息，而不是持续发送 176 个 RGB 像素；
- ESP32 掌握真实灯位映射、亮度/电流上限、超时熄灯和安全状态；
- 浏览器仍掌握乐谱、时间线、循环、左右手、判分和曲库。

这条边界允许界面暂时掉线时仍保留本地按键反馈，也不会让 Wi-Fi 抖动进入最短实时路径。

## 两种路线比较

| 维度 | 直接 fork PTS 网页（AGPL） | NoteFall 独立实现（MIT，已选） |
|---|---|---|
| 首批成熟功能 | MusicXML、三模式、谱面、曲库和校准可较快获得 | MIDI/MusicXML/MXL、谱面、三模式、循环、左右手、移调、曲库、录制和逐键校准已有独立实现 |
| 许可证 | 衍生前端必须遵守 AGPL；网络交互版本须显著提供相应源码 | 自写核心保持 MIT；每个第三方依赖按自己的许可证归档 |
| 与现有硬件的匹配 | 默认 Web MIDI → 浏览器 → WLED；需重写输入、灯光和连接状态 | 原生就是 PX-S7000 → ESP32 → APA102/SK9822 |
| iOS/Android | iOS MIDI 需 MIDIWeb，WLED 场景还可能需 PC/Mac helper | 移动浏览器只连 ESP WebSocket，不需要 Web MIDI/helper |
| 实时灯光 | 浏览器生成 RGB 帧并经网络发往 WLED | ESP 直接处理实际按键；目标音符才经 Wi-Fi 提前下发 |
| 部署资源 | PTS 重型资源通常运行/存储在手机、平板或电脑，不要求进入 WLED；若坚持 ESP 单机托管才受 LittleFS 限制 | Core 内置离线网页与 gzip OSMD；Studio 已由预装 PWA/Capacitor 原生容器承载重型转换资源 |
| 工程结构 | Plain JS + 多个全局模块；核心/LED 大文件，适配会是侵入式改造 | TypeScript 模块、协议版本、单元测试和固件 CI 已建立 |
| 长期维护 | 能获得上游修复，但每次合并都要处理自定义硬件分叉 | 需要自己实现功能，但边界更小、设备行为更确定 |
| 最终用户步骤 | 可能需要浏览器 MIDI 权限、MIDIWeb 或 helper | 预期只需钢琴接 ESP、手机连设备 Wi-Fi 并打开页面 |

结论不是“AGPL 不好”，也不是“PTS 太大所以不能用”，而是 PTS 的许可证和默认拓扑都对应另一种产品。即使接受 AGPL，仍需大规模改写 MIDI 输入、WLED 帧输出、设备诊断和移动端路径；fork 并不能直接变成 NoteFall 成品。若未来的功能差距证明独立实现成本失控，可把 PTS 改造版作为单独 AGPL Studio 重新评估，而不推翻已经稳定的 ESP Core。

## 资源容量与运行位置

PTS 原本就不是把网页、OSMD、webmscore、曲库和练习引擎放进 WLED ESP32；这些资源运行在浏览器，WLED 主要接收灯光帧。以下数据只回答“哪些资源能随 NoteFall Core 一起烧进 N8R8”，不能单独决定是否采用 PTS 前端。

当前 ESP32-S3 N8R8 分区为双 OTA 应用各 `0x280000`，LittleFS 为 `0x2E0000`（2.875 MiB）：

| 资源 | 审计大小 | NoteFall 处理 |
|---|---:|---|
| OSMD 压缩脚本 | 1,206,484 bytes | 已独立集成 1.9.9；生产 gzip 为约 306 kB，buildfs 与 390 px 手机渲染已通过 |
| Tone.js | 349,169 bytes | 不需要；PX-S7000 自己发声 |
| webmscore 目录 | 24,173,611 bytes | 不嵌入固件；已作为 Studio 锁版本离线 Worker 转换包 |
| PTS 自写 JS/CSS/HTML/helper | 约 15,720 非空行 | 只研究功能与边界，不复制 |

因此 Core 仍采用“MusicXML/XML/MXL 原生导入 + MIDI 原生导入”。重型转换器已按这个边界进入预安装的 Studio 层：无 CDN、Service Worker 离线缓存、Capacitor 随包、转换后存 MusicXML，不进入 ESP。完整实现与 GPL 组合发行边界见 [ADR-005](decisions/005-studio-score-converter.md)。

## 分功能采用计划

| PTS 已验证的能力 | NoteFall 做法 | 采用边界 |
|---|---|---|
| MusicXML/MXL + 谱面 | 已独立集成 OSMD（BSD-3-Clause）与自己的安全解压/时间线/谱面适配层 | 不复制 PTS 的 OSMD 包装和 trainer-core |
| MIDI/MuseScore/Guitar Pro 转换 | MIDI 保留 `@tonejs/midi`；Studio 用独立上游 GPL 发行包实现 MSCZ/MSCX/Guitar Pro/KAR 离线 Worker 转换 | 不复制 PTS 包装代码；不把 24 MB webmscore 塞入 ESP |
| Realtime / Wait / Follow | 已在现有 TypeScript 引擎独立实现；Follow 将另一手相对时间事件交给 ESP 固定队列，再由 PX-S7000 自身音源播放 | 用测试定义节拍、同音重触发和降级行为，不复制状态机代码 |
| 左右手/循环/变速/移调/得分 | 左右手、循环、25%–200% 五个百分点步进变速、±12 半音目标/OSMD 同步移调和得分已实现 | 目标灯、判分、瀑布流和谱面消费同一变换结果 |
| IndexedDB 曲库/备份 | 已独立实现版本化 schema、文件夹、最近使用、内容去重和 SHA-256 可校验备份 | 借鉴产品需求，不复制对象结构或 UI 代码 |
| LED 逐键校准 | 已用真实琴键几何 + 方向/全局偏移 + 88 键独立 ±4 像素修正实现 | 灯位真相和 NVS 持久化在 ESP；浏览器只操作语义参数 |
| WLED HTTP/DDP | 不作为主链路 | ESP 直接 SPI 驱动 APA102/SK9822，无 helper |
| Web MIDI/MIDIWeb | 不作为 PX-S7000 主链路；未来可作为无硬件演示输入 | 手机只消费 ESP 标准化事件 |

## 独立实现的可审计规则

- 本仓库不导入 PTS 文件、代码片段、CSS、图片、曲库或构建产物。
- 新功能先写 NoteFall 行为规格与测试，再在现有 TypeScript/C++ 模块中实现。
- 可复用第三方依赖从其官方发行渠道单独引入，固定版本，保存许可证和 NOTICE，而不是从 PTS 的 vendored 副本复制。
- 提交说明标明“受哪项公开产品行为启发”与“实际独立实现文件”，便于后续审计。
- 若需要制作 PTS 兼容桥或直接给 PTS 增加 NoteFall 输出端，单独建 AGPL 项目并保留显著源码入口。

因为当前工程人员已经阅读过 PTS 源码，本方案不宣称是由隔离团队执行的 formal clean-room 工程；准确说法是“源码可审计后的独立实现，并禁止复制”。

## 进度与继续开发顺序

1. **已完成**：延音踏板（CC64）、All Notes Off、通道化演奏录制和 MIDI 导出。
2. **已完成**：IndexedDB 曲库、文件夹、并发内容去重、版本化校验备份、规模上限与跨目录/乐谱原子恢复。
3. **已完成数字验收**：OSMD、MusicXML/MXL 安全解压、统一时间线、gzip 固件资源，以及桌面/390 px 手机浏览器渲染。
4. **已完成数字验收**：标准反复、次数、多结尾、D.C./D.S./Fine/Coda 已展开为统一播放顺序并映射回 OSMD 书写小节；下一步用 MuseScore、Dorico/Finale 和网络 MXL 建立真实兼容性语料。
5. **已完成数字验收**：逐键微调、同步移调和 Follow Me 已完成；伴奏选择 PX-S7000 USB MIDI OUT，包含端点能力探测、固件本地排程、全音符关闭、疑似输出镜像诊断及无 OUT 端点降级。Casio 官方实现把键盘发送和外部接收分属 Performance Controller / C 组 Sound Generator，因此不使用会误吞真实齐奏的回声启发式；端点与镜像计数仍列入实机验收。
6. **已完成数字验收**：Studio PWA/原生壳已内置无 CDN 的 webmscore Worker，真实 MSCX 自动转换、五线谱渲染和三音符时间线通过；Core 构建不含该运行时。

## 参考资料

- [Piano Trainer Studio 官方仓库](https://github.com/ztbishop/piano-trainer-studio)
- [Piano Trainer Studio 官方使用说明](https://pianotrainerstudio.com/README.html)
- [PTS 固定审计提交](https://github.com/ztbishop/piano-trainer-studio/tree/9b21d7e7277aa1da8d82b3d67fe036bfccd11e81)
- [GNU AGPL-3.0 正文](https://www.gnu.org/licenses/agpl-3.0.en.html)
- [GNU GPL FAQ：AGPL 网络交互](https://www.gnu.org/licenses/gpl-faq.en.html#AGPLv3InteractingRemotely)
- [OpenSheetMusicDisplay 官方仓库（BSD-3-Clause）](https://github.com/opensheetmusicdisplay/opensheetmusicdisplay)
- [Casio PX-S7000 用户手册：USB MIDI 双向收发](https://www.casio.com/content/dam/casio/global/support/manuals/electronic-musical-instruments/pdf/008-en/p/PXS7000_usersguide_EN.pdf)
- [Casio PX-S6000/PX-S7000 MIDI Implementation](https://www.casio.com/content/dam/casio/global/support/manuals/electronic-musical-instruments/pdf/008-nl/p/PX-S7000_midi_implementation_NL.pdf)

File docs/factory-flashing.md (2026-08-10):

# 全新开发板首次烧录

本 ZIP 只适用于乐鑫官方 `ESP32-S3-DevKitC-1 N8R8`。它会清除目标开发板的全部 Flash，并一次写入引导程序、分区表、固件和 NoteFall 网页；不要用于其他 ESP32 型号或已有重要数据的开发板。

## Windows 操作

1. 完整解压 ZIP，不要直接在压缩软件预览窗口里运行脚本。
2. 暂时断开钢琴、灯带和外部 5V，只用可靠的数据线把开发板的 `UART` Micro-USB 口连接电脑。
3. 在设备管理器查看串口，例如 `COM5`。
4. 安装 Python 3.10 或更高版本，然后在解压目录打开 PowerShell：

```powershell
python -m pip install esptool==4.5.1
python flash_factory.py --port COM5
```

把 `COM5` 换成实际端口。脚本会先验证板型、文件大小和 SHA-256，再显示即将执行的命令；只有输入大写 `ERASE` 后才清除并写入。不要用 `--yes` 跳过首次确认。

## 烧录后

1. 等待开发板重启，手机搜索 `NoteFall-88` 热点。
2. 使用首次密码 `notefall88`，打开 `http://192.168.4.1`。
3. 立即在“设备设置 → 设备维护”把默认密码改成至少 12 位的独有密码。
4. 再按仓库中的《第一次制作》和《完整测试流程》连接 H5/H7、Y 线、钢琴和灯带。

若脚本在写入前失败，不会改变设备；若写入中途断电，重新运行同一命令即可。脚本不自动猜串口，避免误擦除其他串口设备。

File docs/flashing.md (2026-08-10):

# 刷机与首次使用

## 推荐：使用发布页单文件首刷包

全新乐鑫官方 `ESP32-S3-DevKitC-1 N8R8` 可直接从 [GitHub Releases](https://github.com/cheguevara-great-man/notefall88-px-s7000/releases) 下载 `notefall88-factory-<版本>.zip`。完整解压后阅读包内 `FLASHING.md`，安装固定版本 esptool，再运行：

```powershell
python flash_factory.py --port COM5
```

该路径只需 Python，不需要克隆源码、Node、CadQuery 或 PlatformIO。脚本先验证板型、镜像大小与 SHA-256，明确输入 `ERASE` 后才擦除目标板，并以单一地址 `0x0` 写入包含 bootloader、分区表、OTA 初始数据、固件和 LittleFS 的合并镜像。它不会自动猜串口。以下源码构建流程用于开发、审计和故障恢复。

## 自动构建

在仓库根目录执行：

```powershell
python -m pip install -r requirements-dev.txt
python scripts/generate.py --check
cd web
npm.cmd ci
npm.cmd test -- --run
npm.cmd run build
cd ..
.\.venv\Scripts\platformio.exe run -d firmware
.\.venv\Scripts\platformio.exe run -d firmware -t buildfs
```

`platformio.ini` 把临时构建目录放到纯英文用户缓存，是为了规避旧版 Xtensa Windows 链接器不能在中文路径创建 map 文件的问题；源代码和输出仍由仓库管理。`firmware/boards/notefall-esp32-s3-devkitc1-n8r8.json` 固定乐鑫 N8R8 的 8 MB Quad Flash、8 MB Octal PSRAM、原生 USB 与烧录参数，避免把同外形的 N8 无 PSRAM配置误用于实板；项目自身 C/C++ 代码以 `-Wall -Wextra -Werror` 编译。

## 烧录

1. 用数据线把开发板标 `UART` 的 Micro-USB 口接电脑；此时不要连接钢琴。
2. 执行：

```powershell
.\.venv\Scripts\platformio.exe run -d firmware -t upload
.\.venv\Scripts\platformio.exe run -d firmware -t uploadfs
```

3. 如果自动找不到串口，在命令后加 `--upload-port COMx`，其中 `COMx` 以设备管理器显示为准。
4. 首次必须同时烧固件和文件系统。网页改动后只需 `uploadfs`；固件改动后执行 `upload`。

首次成功打开网页后，进入“设备设置 → 设备维护”，连接 `NoteFall-88` 热点并把默认热点密码改为至少 12 位的独有密码。密码保存在 ESP32 NVS，不会由诊断接口或网页回显；忘记时仍可用 UART 重新烧录/清除 NVS 恢复。

## 后续无线更新

正式 GitHub 标签会自动构建 `firmware.bin`、`littlefs.bin`、SHA-256 清单和组合 ZIP。无线更新必须：

1. 先导出曲库和练习历史；
2. 手机/平板切换到设备自身 `NoteFall-88` 热点，而不是只通过家庭 Wi-Fi 访问；
3. 在“设备维护”再次输入当前热点密码；
4. 分别选择固件或网页 `.bin`，核对页面显示的分区上限后上传；
5. 看到“设备确认成功”前绝不拔电。固件成功后设备自动重启，再确认版本、USB 和校准仍正常。

无线更新不能替代首次 UART 烧录，也不能修复供电、USB 或完全无法启动的问题。完整威胁边界、失败恢复和发布包格式见 [安全更新说明](update.md)。

## 使用

手机或平板连接 `NoteFall-88`，首次密码 `notefall88`，浏览器打开 `http://192.168.4.1`。首次进入后立即在“设备维护”修改该公开默认密码；修改前安装向导不会允许完成。设置页可把 ESP32 加入家中 Wi-Fi；保存后会重启，热点仍保留作为故障恢复入口。通过家庭 Wi-Fi 打开时默认只能看诊断，输入当前热点密码后才会为当前标签页解锁灯光、校准和 MIDI OUT；密码不写入浏览器存储，页面只保存本次 ESP 启动有效的会话令牌。

网页是本地文件，不需要互联网、账号或手机 App。手机只负责显示瀑布；钢琴按键经 USB 直接进入 ESP32。

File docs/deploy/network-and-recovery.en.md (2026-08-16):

# Home networking, rescue access, and brick prevention

NoteFall 88 normally joins the saved 2.4 GHz home WLAN. Credentials live in ESP32 NVS and survive power cycles, application OTA, and filesystem updates. The tablet may use either the router's 2.4 or 5 GHz radio. The installed **NoteFall Studio** app is the normal entry point: its Android layer discovers the ESP32 over UDP port 32188 and discovers it again after a disconnect or DHCP address change, so the user does not need to remember an IP address.

The `NoteFall-88` rescue AP remains enabled at all times. If the router, credentials, DHCP, or mDNS fail, join that AP and open `http://192.168.4.1/recovery`. The recovery page is compiled into every application image and does not depend on LittleFS.

The Xiaomi Pad 7 Ultra running Android 16 has been verified against the real device: after the one-time Nearby devices permission grant, Studio discovered the ESP32 at `192.168.1.7`, opened its WebSocket, reused its persistent random control token, and reconnected after an ESP32 restart. The firmware still advertises `notefall.local`, but that name did not resolve reliably on this tablet/router combination and is therefore optional rather than a single point of access.

Firmware upload is safe against interruption: an incomplete image never becomes bootable. A completed candidate must match the running NoteFall project identity. ESP-IDF rollback remains pending until the new application has run for at least 10 seconds, passed storage/LED/USB-host/realtime/network checks, and received a real HTTP or WebSocket request. A crash or reset before confirmation causes bootloader rollback; an alive but unreachable or unhealthy image actively rolls back after 90 seconds.

The client stores a random persistent control token rather than the plaintext management password. The native app performs factory-default authentication only when the device explicitly reports that the factory password is still active. The token survives normal ESP32 and app restarts; changing the management password revokes it. Only NVS erasure or a factory flash clears home Wi-Fi, the token, and per-key calibration.

The native app uses a dedicated internal `https://studio.notefall` origin and does not register the PWA service worker, preventing an APK update from being shadowed by stale cached JavaScript. Browser PWA builds keep their offline service worker. For browser-only recovery, use the current DHCP address or try `http://notefall.local` where mDNS works; the router-independent fallback is always `http://192.168.4.1/recovery` on the rescue AP.

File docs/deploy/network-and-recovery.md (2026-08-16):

# 家庭网络、救援热点与防变砖机制

NoteFall 88 正常使用时优先连接已保存的 2.4 GHz 家庭 Wi-Fi。凭据保存在 ESP32 的 NVS 中，断电、普通固件 OTA 和网页更新都不会清除；平板也只需让 Android 保存一次家庭 Wi-Fi 密码。练琴时直接打开已安装的 **NoteFall Studio**：Android 原生层会在局域网内发现 ESP32，并在断线或 DHCP 地址变化后重新发现和连接，不要求用户记 IP。

## 永久可达的两条网络路径

- **日常路径**：ESP32 自动连接家庭 2.4 GHz Wi-Fi；平板可以连接同一路由器的 2.4 GHz 或 5 GHz。Studio 用 UDP 32188 自动发现设备；固件关闭 Wi-Fi 省电并启用自动重连，断线后每 10 秒主动重试。
- **救援路径**：`NoteFall-88` 热点始终开启，不因家庭 Wi-Fi 成功而关闭。家庭路由器故障、密码变更或 mDNS 不可用时，平板连接该热点并打开 `http://192.168.4.1/recovery`。

设备管理密码与家庭 Wi-Fi 密码不是一回事。客户端成功解锁后保存的是随机控制令牌，不保存明文管理密码；令牌和 ESP32 重启前后一致，因此同一客户端不需要每次重新输入。原生 Studio 只在设备明确报告仍使用出厂管理密码时自动完成首次换取令牌；修改设备管理密码会立即撤销旧令牌。

小米 Pad 7 Ultra 的 Android 16 实机已经完成以下验收：首次授予“附近设备”权限后，Studio 能发现 `192.168.1.7` 的实机、建立 WebSocket、在 ESP32 重启后自动恢复连接，并继续使用已保存的随机令牌。`notefall.local` 仍由固件发布，但在该平板和当前路由器组合上不能可靠解析，因此它只是可选入口，不是日常方案的单点依赖。

## OTA 失败时的确定行为

| 故障 | 设备行为 |
|---|---|
| 上传途中断网、浏览器关闭或断电 | 未完成镜像不会被设为启动槽；继续运行原固件 |
| 上传了非 NoteFall 固件 | 项目标识检查失败，拒绝切换启动槽 |
| 新固件启动崩溃或被看门狗复位 | ESP-IDF bootloader 自动回滚到上一 OTA 槽 |
| 新固件能启动但网页/网络不可达 | 90 秒内收不到真实 HTTP/WebSocket 健康访问，主动回滚 |
| 新固件可达但存储、灯带、USB Host 或实时任务自检失败 | 不确认新槽，90 秒后回滚 |
| LittleFS 普通网页损坏 | 固件内置 `/recovery`，仍可重刷网页或固件 |
| 家庭 Wi-Fi 不可用 | 永久 `NoteFall-88` 热点仍可进入救援页 |

新固件只有在启动至少 10 秒、内部关键模块健康，并且平板或浏览器确实访问成功后，才调用 `esp_ota_mark_app_valid_cancel_rollback()`。在此之前它保持 `ESP_OTA_IMG_PENDING_VERIFY`。没有得到确认的版本在 90 秒后调用 `esp_ota_mark_app_invalid_rollback_and_reboot()`。

## 日常使用

1. 平板保持连接家庭 Wi-Fi。
2. 打开已安装的 NoteFall Studio；首次出现“附近设备”权限时允许一次，以后无需重复操作。
3. 临时使用浏览器 Core 时可打开设备设置中显示的家庭 IP；当前实机为 `http://192.168.1.7`，但 DHCP 地址以后可能变化。若路由器支持 mDNS，也可尝试 `http://notefall.local`。
4. 家庭网络或自动发现不可用时，切换到 `NoteFall-88` 并访问 `http://192.168.4.1/recovery`。这一入口不依赖家庭路由器、mDNS 或 LittleFS。

原生 App 使用独立的 `https://studio.notefall` 内部 origin，并禁用 PWA Service Worker 注册，避免 APK 更新后继续运行缓存中的旧脚本；浏览器 PWA 仍保留离线缓存。该 origin 只存在于 App 内，不是需要在浏览器中访问的网站。

不要擦除 NVS 或反复刷 factory 镜像；这两种操作才会清除家庭 Wi-Fi、控制令牌和 88 键校准。普通双槽 OTA 不会清除这些数据。

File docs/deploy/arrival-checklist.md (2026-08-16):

# 本机到货验收清单

> 当前状态：硬件已下单、尚未到货。本清单只要求清点和断电测量；未到“允许上电”标记前，不连接 5 V 电源。
> 在本清单第 5 节全部满足前，不得给灯带或钢琴 USB 链路上电。

## 0. 先不要做

- 不要剪灯带，不要贴琴，不要给灯带上电。
- 不要仅凭红黑绿蓝线色判断引脚；先看灯带焊盘标识和箭头，再用万用表确认。
- **2026-08-16 实物复核：** 所购 KF301‑3P 的三个相邻脚两两均不导通，是标准独立极位 PCB 端子；商家所说的“可以连起来”仅能理解为外壳可机械拼接，不能作为 5 V/GND 公共配电节点直接使用。
- 这批 KF301 只保留给后续焊接小板使用；主电源配电改用明确标注内部共点、可夹软线且额定电流不低于 5 A 的一进六出（或更多位）绝缘分线端子，5 V 与 GND 各一只，到货仍需逐孔蜂鸣复核。
- 不要用杜邦线承载灯带电流，不要把裸 DIP 芯片直接装入最终控制盒。
- 不要把两只不同电源同时接入 ESP32、Y 线或灯带。

## 1. 拍照留证但不要上传个人信息

只拍物品、标签、接口和焊盘近照；画面中不要出现订单、快递面单、地址、电话、付款页、银行卡或聊天账号。建议照片命名：

- `power-label.jpg`
- `strip-input.jpg`、`strip-output.jpg`
- `y-cable-ports.jpg`
- `esp32-label-and-ports.jpg`
- `h5-h7-wire-ends.jpg`
- `level-shifter-parts.jpg`

这些照片只在需要诊断时提供；仓库默认不收录私人实物照片。

## 2. 按台账清点

逐行打开 [as-purchased.csv](as-purchased.csv)，把“已买未到”核成实物。数量、型号或接口不符时先单独放置，不尝试“能插就插”。重点确认：

- ESP32 丝印为官方 `ESP32-S3-DevKitC-1`，模组为 `N8R8`；
- 灯带电气规格为 `SK9822 / 5V / 144 px/m / 非防水`；本机照片显示实际 PCB 为白色且由 `32 + 72 + 72` 三段焊接，与原黑色连续 PCB 采购描述不一致，作为已知到货偏差记录，不再凭订单描述验收；
- 电源铭牌为 `5 V / 5 A`，DC 插头与 DC015 匹配；
- 芯片完整料号含 `74AHCT125`，不是 `74HC125`、TXS0108E 或 BSS138；
- Y 线确有 Micro-USB 公头、USB-A 母口、Micro-USB 供电口三个接口；
- 打印机线是 USB-A 公到 USB-B 公，接钢琴方形 `USB TO HOST`。

## 3. 断电电气检查

1. 万用表表笔短接应蜂鸣；分开不蜂鸣。
2. 按商家说明拼好 KF301‑2P/3P，在端子完全断电且未接其他器件时逐孔蜂鸣，画一张“哪些孔互通”的小图。预定作同一 5V 或 GND 节点的孔必须全部互通；5V 组与 GND 组必须完全不通。结果与商家说明不符就停用并联系商家。
3. 保险丝装入时保险座两端导通，取下时断开。
4. 100 Ω 电阻逐只测得约 100 Ω；电解电容确认负极条纹，暂不测带电容量。
5. 打印机线的 USB 外壳无松动；不要用通断档盲碰相邻 USB 针脚。
6. 灯带输入端必须能看到 `DI/DIN`、`CI/CIN` 或箭头起点；输出端应是箭头终点。把实际焊盘文字和线色写进验收记录，线色与文档冲突时以焊盘为准。
7. 两根 Micro-USB 供电线在接入任何设备前，确认哪根裸线到 VBUS、哪根到 GND；若不能可靠查明，停止使用并更换明确标注的供电线。

## 4. 到货后最小补件判定

以下不是让用户现在重新采购，而是根据实物决定：

- **0.1 µF（100 nF）陶瓷电容：必需。** 裸 74AHCT125N 与成品模块不同，必须在 14 脚 VCC 和 7 脚 GND 附近去耦；如果现有电子套件没有，只补这一只或小包。
- **KF301 配电形态：已判定不共点。** 实物三个相邻脚两两均不导通，不得自由搭接或作为主电源汇总；只可焊到可靠小板。主电源使用独立绝缘共点分线端子。
- **绝缘与应力释放：条件必需。** 若电阻、电容、DC015、保险座或盒体开口存在裸导体/磨线风险，补热缩管、护边或扎带后才允许上电。
- **接触式温度计：G1 前必需，可借。** 不影响清点，但没有温升数据不能通过 G1。

## 5. 允许进入 G1 的条件

必须同时满足：

- [ ] `as-purchased.csv` 每个最终件完成型号与数量核对；
- [ ] 灯带方向、像素数量和头尾线定义已经记录；
- [ ] 电源、DC015 与保险的规格匹配；
- [ ] H5/H7 的 VBUS/GND 已能逐线确认；
- [ ] 74AHCT125N 有 0.1 µF 就近去耦方案，未使用通道不会悬空；
- [ ] KF301 的实物共点图已记录，5 V 组内部全通、GND 组内部全通、两组之间不通；
- [ ] 所有裸导体有绝缘方案，所有重线有应力释放；
- [ ] 万用表工作正常。

满足后，按 [上电、校准与验收](../testing.md) 的 A→B 顺序进入 G1：先烧录并只验证 ESP32，再验证 USB，最后才接灯带。任何过热、异味、闪烁、随机重启或 USB 反复掉线都立即断电。

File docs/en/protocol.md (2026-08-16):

# Controller protocol

The controller exposes a versioned WebSocket protocol for Studio, a local recovery page, and diagnostics. The protocol is intentionally compact: Studio calculates practice targets; the ESP32 validates a message, applies safety limits and calibration, and drives pixels.

## Core message families

- `hello` / authorization: establishes protocol compatibility and scoped control access.
- Device status: firmware version, USB state, MIDI endpoints, signal counters, memory, reset reason, Wi-Fi strength, and safe diagnostics.
- MIDI event: timestamped keyboard and pedal events from the controller.
- Target frame: requested key targets and colors; invalid values are rejected and brightness is clamped by firmware.
- Calibration: strip direction, global offset, and bounded 88-key corrections.
- Time synchronization: ping/pong samples enable Studio to project ESP32 timestamps into browser time without treating network arrival time as musical timing.

## Real-time transport and observability

USB host daemon events, USB MIDI client events, the Core 0 MIDI/LED pipeline, and the Core 1 Arduino network loop are isolated from one another. A USB packet wakes the real-time task directly; all events already in the fixed queue are merged into one coherent LED frame before JSON or WebSocket work runs. The 176-pixel APA102 frame remains exactly 719 bytes at 8 MHz with the same BGR and 5-bit brightness semantics, but is emitted as one bulk hardware-SPI operation and unchanged idle frames are skipped.

Additive protocol-v6 status fields expose USB input/output queue depth and high-water marks, callback-to-dispatch and callback-to-LED latency, SPI duration/frame count, real-time heartbeat/stack/watchdog state, and browser MIDI queue depth/drop/resynchronization counters. The USB client wakes the higher-priority real-time task once after a complete transfer is queued, retaining one-frame chords without allowing sustained input to starve LED rendering. Browser forwarding uses a fixed 128-event queue and a bounded batch per loop; after an extreme overflow it clears CC64/66/67/123 on every channel and reconstructs held keys with the existing messages, so older v6 clients recover without learning a new message type. USB loss immediately clears held, target, and test LEDs before the disconnected state is published.

The full normative Chinese protocol is [docs/protocol.md](../protocol.md). This English guide is a navigation document; generated protocol versions and tests are the authoritative implementation artifacts.

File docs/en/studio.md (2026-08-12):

# NoteFall Studio

Studio is the feature-rich practice layer. It is delivered as an installable PWA and as Capacitor-based Android/iOS packages so the same practice engine can be used in a browser, on a tablet, or in an app shell.

## Music and views

- MIDI and MusicXML/MXL import, with offline conversion support for common score formats.
- Piano-roll view, notation view, and a combined view; either visualization can be used alone.
- Responsive landscape layout designed for a 3:2 large tablet, including Xiaomi Pad 7 Ultra (3200 x 2136).
- Full-screen practice mode that removes nonessential chrome.

## Practice engine

- Real-time, Wait for Me, and Follow Me modes.
- Hand/part selection, A-B looping, tempo steps, transpose, count-in, metronome, and MIDI demonstration playback.
- Pitch, timing, velocity, duration, pedal, chord synchronization, and cross-hand analysis where the source score provides enough evidence.
- Recording to standard MIDI, session replay, local history, exports, adaptive weak-passage drills, and a spaced-review "Today" queue.

## Offline and privacy

Scores, recordings, analysis, and backups remain on the user's device unless explicitly exported. The ESP32 does not host the large Studio application; it hosts the lightweight control/recovery experience while Studio is installed or cached on the tablet/phone/computer.

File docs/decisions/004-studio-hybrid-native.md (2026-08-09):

# ADR-004：Studio 采用混合原生容器与 GPU Web 渲染

- 状态：已接受
- 日期：2026-08-09

## 决策

NoteFall Studio 同时交付可安装 PWA 和 Capacitor Android/iOS 应用。移动应用是原生安装包与原生生命周期容器，MusicXML/练习引擎和协议继续共享 TypeScript；OSMD 谱面保留专用 WebView。Android 已实现硬件加速原生瀑布流 View：乐谱与键盘几何只在变化时跨桥传送，播放时钟低频校正后由原生视图按系统单调时钟逐帧绘制，不传像素帧。iOS 当前使用 Canvas/WebGL 回退，保留相同接口等待 Xcode 环境实现对应原生视图。

这不是把远程网站塞进壳里：Studio 的全部前端资源随应用打包、可离线启动，并通过协议 v6 连接 ESP32 Core。Core 内置网页继续作为零安装救援入口。

## 为什么不立即整套真原生重写

SwiftUI/Compose/Flutter 直接绘制的理论上限更高，但 OSMD 的 SVG/DOM 谱面仍需 WebView 或重新实现专业排版。实体灯的实时决策与 SPI 输出在 ESP32 内完成，不依赖 UI 调度。需要重写的是呈现和交互层，不是 MusicXML、练习、评分、曲库、协议或固件；因此瀑布流原生化是局部、可控的升级，不应被描述成“整套工程重写”。

## 不是永久锁定

Canvas/WebGL 基线和 Android 原生版本必须在相同数据集上通过以下门禁：

- 典型双手密集谱在 60 Hz 屏幕持续低于 55 FPS；
- 触控到画面反馈的 P95 超过 50 ms；
- 连续练习 60 分钟发生 WebView 回收、音画时序漂移或不可恢复断连；
- 局域网、文件或后台恢复无法由受限原生桥接可靠解决。

因此，本决策是“共享引擎 + 混合谱面 + 原生 GPU 瀑布流”，而不是声称 WebView 与真原生完全相同。

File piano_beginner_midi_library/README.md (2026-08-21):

# Verified human-performance piano MIDI library

本目录只收录可核验的真人演奏 MIDI。文件均为原始 performance MIDI 的字节复制：没有由乐谱/MusicXML 转换、量化、重定时或 AI 转录。

## 使用方式

将需要的 `performance.mid` 导入 NoteFall Studio。不要把本目录中的元数据当成乐谱；它只记录演奏来源和审计结果。

## 结果

| 曲名 | 来源 | 真人确认 | velocity | pedal | 难度 |
| --- | --- | --- | --- | --- | --- |
| 01. River Flows in You | not_found_in_verified_performance_dataset | 否（未收录） | — | — | 入门 |
| 02. Comptine d'un autre été | not_found_in_verified_performance_dataset | 否（未收录） | — | — | 入门 |
| 03. Kiss The Rain | PianoVAM v1 direct digital-piano performance MIDI | 是 | 是 | 是 | 入门 |
| 04. Merry Christmas Mr. Lawrence | not_found_in_verified_performance_dataset | 否（未收录） | — | — | 入门 |
| 05. Gymnopédie No. 1 | PianoVAM v1 direct digital-piano performance MIDI | 是 | 是 | 是 | 入门 |
| 06. Canon in D | not_found_in_verified_performance_dataset | 否（未收录） | — | — | 初级进阶 |
| 07. Always With Me (千与千寻) | PianoVAM v1 direct digital-piano performance MIDI | 是 | 是 | — | 初级进阶 |
| 08. Castle in the Sky (天空之城) | not_found_in_verified_performance_dataset | 否（未收录） | — | — | 初级进阶 |
| 09. Summer | PianoVAM v1 direct digital-piano performance MIDI | 是 | 是 | 是 | 初级进阶 |
| 10. Merry Go Round of Life | not_found_in_verified_performance_dataset | 否（未收录） | — | — | 初级进阶 |
| 11. Prelude in C Major, BWV 846 | ASAP performance MIDI | 是 | 是 | 是 | 古典入门 |
| 12. Für Elise | PianoVAM v1 direct digital-piano performance MIDI | 是 | 是 | 是 | 古典入门 |
| 13. Moonlight Sonata, 1st Movement | not_found_in_verified_performance_dataset | 否（未收录） | — | — | 古典入门 |
| 14. Prelude Op. 28 No. 4 | SMD direct Yamaha Disklavier performance MIDI | 是 | 是 | 是 | 古典入门 |
| 15. Waltz Op. 69 No. 2 | not_found_in_verified_performance_dataset | 否（未收录） | — | — | 古典入门 |
| 16. Clair de Lune | PianoVAM v1 direct digital-piano performance MIDI | 是 | 是 | 是 | 展示型 / 高级 |
| 17. Nuvole Bianche | not_found_in_verified_performance_dataset | 否（未收录） | — | — | 展示型 / 高级 |
| 18. Experience | not_found_in_verified_performance_dataset | 否（未收录） | — | — | 展示型 / 高级 |
| 19. Nocturne Op. 9 No. 2 | MAESTRO v3 performance MIDI | 是 | 是 | 是 | 展示型 / 高级 |
| 20. La Campanella | MAESTRO v3 performance MIDI | 是 | 是 | 是 | 展示型 / 高级 |

## 额外适合当前阶段的真人演奏曲目

| 曲名 | 来源 | 真人确认 | velocity | pedal | 难度 |
| --- | --- | --- | --- | --- | --- |
| B01. Canon in C (verified alternate arrangement) | PianoVAM v1 direct digital-piano performance MIDI | 是 | 是 | 无 CC64 | 入门 |
| B02. My Neighbor Totoro Ending | PianoVAM v1 direct digital-piano performance MIDI | 是 | 是 | 无 CC64 | 入门 |
| B03. Surprise Symphony (piano arrangement) | PianoVAM v1 direct digital-piano performance MIDI | 是 | 是 | 无 CC64 | 入门 |
| B04. Home, Sweet Home | PianoVAM v1 direct digital-piano performance MIDI | 是 | 是 | 无 CC64 | 入门 |
| B05. Stay in Memory | PianoVAM v1 direct digital-piano performance MIDI | 是 | 是 | 是 | 初级进阶 |
| B06. Ballade Pour Adeline | PianoVAM v1 direct digital-piano performance MIDI | 是 | 是 | 是 | 初级进阶 |
| B07. The Blue Danube (beginner piano arrangement) | PianoVAM v1 direct digital-piano performance MIDI | 是 | 是 | 无 CC64 | 入门 |
| B08. Sonatina Op. 36 (short classical study) | PianoVAM v1 direct digital-piano performance MIDI | 是 | 是 | 是 | 古典入门 |
| B09. Mozart Sonata K. 545 (accessible classical sonata) | PianoVAM v1 direct digital-piano performance MIDI | 是 | 是 | 是 | 初级进阶 |
| B10. Antifreeze | PianoVAM v1 direct digital-piano performance MIDI | 是 | 是 | 是 | 初级进阶 |
| B11. This Is the Moment | PianoVAM v1 direct digital-piano performance MIDI | 是 | 是 | 是 | 初级进阶 |
| B12. The Virgin's Prayer | PianoVAM v1 direct digital-piano performance MIDI | 是 | 是 | 是 | 初级进阶 |
| B13. Last Carnival | PianoVAM v1 direct digital-piano performance MIDI | 是 | 是 | 是 | 初级进阶 |
| B14. Morning Mood | PianoVAM v1 direct digital-piano performance MIDI | 是 | 是 | 是 | 初级进阶 |
| B15. Reminiscence | PianoVAM v1 direct digital-piano performance MIDI | 是 | 是 | 是 | 初级进阶 |
| B16. Graceful Ghost Rag | PianoVAM v1 direct digital-piano performance MIDI | 是 | 是 | 是 | 初级进阶 |

## 严格筛选规则

- **MAESTRO v3**：Yamaha Disklavier 对真人钢琴家演奏的高精度 MIDI 记录。
- **ASAP**：只允许其 `metadata.csv` 中 `midi_performance` 字段指定的文件；绝不使用同目录的 `midi_score.mid` 或 MusicXML。
- **PianoVAM v1**：只使用其标为从数码钢琴直接录得的 ground-truth performance MIDI，且有同步音频/视频与演奏者元数据。
- **SMD**：只使用 Saarland Music Data 中学生在 Yamaha Disklavier 上演奏时直接捕获的 MIDI；原站同时提供同步音频。
- **PianoCoRe 1.0（正式 TISMIR 版）**：已正式发布，但只接受其元数据中 `is_transcription=false` 的原始 performance MIDI。已审计正式版 250,046 条记录：仅 1,066 条满足该条件，且全部来自 ASAP 的 Disklavier 直录；Aria-MIDI、ATEPP、GiantMIDI-Piano 等标记为转录的条目一律排除。
- 未明确存在于上述可用且可验证来源的曲目统一标记为 `not_found_in_verified_performance_dataset`，不以任何其他 MIDI 替代。

## 文件与可复核性

每个收录曲目目录含 `performance.mid` 和 `metadata.json`。`metadata.json` 给出数据集、原始成员路径、下载链接、SHA-256，以及对音符力度和 CC64 延音踏板的实际审计。

## 许可与归属

收录 MIDI 保留上游的 CC BY-NC-SA 许可：仅限非商业使用；若再分发，必须保留归属、许可和相同方式共享。MAESTRO 归属 Google LLC / International Piano-e-Competition；ASAP、PianoVAM 与 SMD 归属各数据集作者。详见各 `metadata.json` 和官方数据集页面。

生成器：[`tools/build_verified_performance_midi_library.py`](../tools/build_verified_performance_midi_library.py)。

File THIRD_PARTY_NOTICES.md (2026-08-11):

# Third-party notices

## ESP32_Host_MIDI

The USB-MIDI host task/client architecture in `firmware/src/UsbMidiHost.*` is derived from ideas and portions of [ESP32_Host_MIDI v7.2.0](https://github.com/sauloverissimo/ESP32_Host_MIDI/tree/v7.2.0), used under the MIT License.

The NoteFall version removes all non-USB transports, keeps exactly one outstanding IN transfer, allocates no isochronous descriptors for a bulk MIDI endpoint, and adds explicit interface cleanup. The original English MIT notice is reproduced below:

```text
MIT License

Copyright (c) 2025 Saulo Veríssimo

Permission is hereby granted, free of charge, to any person obtaining a copy
of this software and associated documentation files (the "Software"), to deal
in the Software without restriction, including without limitation the rights
to use, copy, modify, merge, publish, distribute, sublicense, and/or sell
copies of the Software, and to permit persons to whom the Software is
furnished to do so, subject to the following conditions:

The above copyright notice and this permission notice shall be included in all
copies or substantial portions of the Software.

THE SOFTWARE IS PROVIDED "AS IS", WITHOUT WARRANTY OF ANY KIND, EXPRESS OR
IMPLIED, INCLUDING BUT NOT LIMITED TO THE WARRANTIES OF MERCHANTABILITY,
FITNESS FOR A PARTICULAR PURPOSE AND NONINFRINGEMENT. IN NO EVENT SHALL THE
AUTHORS OR COPYRIGHT HOLDERS BE LIABLE FOR ANY CLAIM, DAMAGES OR OTHER
LIABILITY, WHETHER IN AN ACTION OF CONTRACT, TORT OR OTHERWISE, ARISING FROM,
OUT OF OR IN CONNECTION WITH THE SOFTWARE OR THE USE OR OTHER DEALINGS IN THE
SOFTWARE.
```

## Browser bundle

Production JS is compiled into `firmware/data/` and therefore contains third-party code. Versions are fixed by `web/package-lock.json`.

| Package | Version | License | Use |
|---|---:|---|---|
| `@tonejs/midi` | 2.0.28 | MIT | MIDI parsing and recording export |
| `midi-file` | 1.2.4 | MIT | transitive Standard MIDI File codec |
| `@xmldom/xmldom` | 0.9.10 | MIT | MusicXML DOM parsing |
| `fflate` | 0.8.2 | MIT | bounded MXL decompression |
| `opensheetmusicdisplay` | 1.9.9 | BSD-3-Clause | MusicXML engraving |
| `vexflow` | 1.2.93 | MIT | OSMD notation renderer |
| `jszip` | 3.10.1 | MIT option of MIT/GPL dual license | OSMD bundled ZIP support |
| `loglevel` | 1.9.2 | MIT | OSMD logging |
| `typescript-collections` | 1.3.3 | MIT | OSMD data structures |
| `pako` | 1.0.11 | MIT | JSZip deflate implementation |

Copyright notices for the MIT components:

- © 2016 Yotam Mann (`@tonejs/midi`)
- © 2016 Carter Thaxton (`midi-file`)
- © 2019–present Christopher J. Brody and contributors; © 2012–2017 @jindw and contributors (`@xmldom/xmldom`)
- © 2023 Arjun Barrett (`fflate`)
- © 2010 Mohit Muthanna Cheppudira (`vexflow`)
- © 2009–2016 Stuart Knightley, David Duponchel, Franz Buchinger and António Afonso (`jszip`, MIT option selected)
- © 2013 Tim Perry (`loglevel`)
- © 2010–2017 Tomasz Ciborski (`typescript-collections`)
- © 2014–2017 Vitaly Puzrin and Andrei Tuputcyn (`pako`)

The MIT terms printed in the ESP32_Host_MIDI section above apply to each MIT-licensed component and its listed copyright holder.

OSMD BSD-3-Clause notice:

```text
Copyright 2019 PhonicScore

Redistribution and use in source and binary forms, with or without
modification, are permitted provided that the following conditions are met:

1. Redistributions of source code must retain the above copyright notice,
   this list of conditions and the following disclaimer.
2. Redistributions in binary form must reproduce the above copyright notice,
   this list of conditions and the following disclaimer in the documentation
   and/or other materials provided with the distribution.
3. Neither the name of the copyright holder nor the names of its contributors
   may be used to endorse or promote products derived from this software
   without specific prior written permission.

THIS SOFTWARE IS PROVIDED BY THE COPYRIGHT HOLDERS AND CONTRIBUTORS "AS IS"
AND ANY EXPRESS OR IMPLIED WARRANTIES, INCLUDING, BUT NOT LIMITED TO, THE
IMPLIED WARRANTIES OF MERCHANTABILITY AND FITNESS FOR A PARTICULAR PURPOSE
ARE DISCLAIMED. IN NO EVENT SHALL THE COPYRIGHT HOLDER OR CONTRIBUTORS BE
LIABLE FOR ANY DIRECT, INDIRECT, INCIDENTAL, SPECIAL, EXEMPLARY, OR
CONSEQUENTIAL DAMAGES (INCLUDING, BUT NOT LIMITED TO, PROCUREMENT OF
SUBSTITUTE GOODS OR SERVICES; LOSS OF USE, DATA, OR PROFITS; OR BUSINESS
INTERRUPTION) HOWEVER CAUSED AND ON ANY THEORY OF LIABILITY, WHETHER IN
CONTRACT, STRICT LIABILITY, OR TORT (INCLUDING NEGLIGENCE OR OTHERWISE)
ARISING IN ANY WAY OUT OF THE USE OF THIS SOFTWARE, EVEN IF ADVISED OF THE
POSSIBILITY OF SUCH DAMAGE.
```

## NoteFall Studio advanced score converter

NoteFall Studio PWA and Android/iOS distributions bundle
`webmscore-webpack5` 0.21.0-a, published under the GNU GPL. It runs in a Web
Worker and converts MuseScore, Guitar Pro, and KAR files to MusicXML. It is not
linked into or distributed with the ESP32-hosted NoteFall Core web bundle.

- Upstream source: <https://github.com/LibreScore/webmscore>
- npm tarball: <https://registry.npmjs.org/webmscore-webpack5/-/webmscore-webpack5-0.21.0-a.tgz>
- npm integrity: `sha512-AI1e+knofehVOwQT9FJHhuNQcOvpz+EfzzfC+U2ANTrj2KgC9kZe6/Ukmm/xCL/ojyBoC0hSb8iq3ZqVJgRYRg==`
- Copied runtime files: `webmscore.mjs`, `webmscore.lib.data`,
  `webmscore.lib.mem.wasm`, and `webmscore.lib.wasm`
- Complete GPL-3.0 text in every Studio distribution:
  `legal/GPL-3.0.txt`
- NoteFall corresponding source and build instructions: this public repository,
  especially `web/src/score-converter.ts`,
  `web/scripts/sync-studio-vendor.mjs`, and
  `docs/decisions/005-studio-score-converter.md`

Because the Studio application loads and communicates with this GPL runtime as
part of one distributed application, the combined Studio PWA/App distribution
is conveyed under GPL-3.0. NoteFall-authored source remains independently
available under MIT; Core remains MIT because its build neither includes nor
loads this runtime. See `studio/LICENSE.md` for the distribution boundary.

## Firmware and engineering dependencies

- `arduinoWebSockets` 2.7.2 — LGPL-2.1; source and license are distributed by the fixed PlatformIO package. Binary distributors must preserve the LGPL notice and applicable relinking/reverse-engineering rights. [Upstream source](https://github.com/Links2004/arduinoWebSockets) and [LGPL-2.1 text](https://www.gnu.org/licenses/old-licenses/lgpl-2.1.html).
- `ArduinoJson` 7.4.3 — MIT.
- Arduino-ESP32 / ESP-IDF toolchain components — their upstream mixed licenses apply to compiled firmware.
- CadQuery — Apache-2.0; used to generate manufacturing exports, not linked into firmware.
- `@playwright/cli` 0.1.17 and its Playwright/Chromium test runtime — Apache-2.0/BSD-family upstream terms; used only for CI browser verification and not linked into or distributed with the firmware web bundle.

Piano Trainer Studio code and assets are not copied or linked. It is an audited AGPL-3.0 product reference only; see `docs/pts-adoption-decision.md`.

## W3C MusicXML test fixtures

Three unmodified compatibility fixtures under `web/test-fixtures/w3c-musicxml/`
come from the W3C Music Notation Community Group's
[`musicxmlTestSuite`](https://github.com/w3c-cg/musicxmlTestSuite/tree/b2e6a1627b8574c9714e1fd0a8a5b1921e10f8f3)
at pinned commit `b2e6a1627b8574c9714e1fd0a8a5b1921e10f8f3`, under the MIT
License. The upstream copyright and full license text are preserved beside the
fixtures in `web/test-fixtures/w3c-musicxml/LICENSE`.

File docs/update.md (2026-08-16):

# 安全更新、发布包与恢复

实机网络与自动回滚的操作说明见 [家庭网络、救援热点与防变砖机制](deploy/network-and-recovery.md)。当前固件允许在家庭 LAN 或永久救援热点中进行带管理密码的 OTA；无需为日常升级切换 Wi-Fi。`/recovery` 页面编译在应用固件中，不依赖 LittleFS。

全新或已擦除的开发板不能使用网页 OTA，应从 GitHub Release 下载 `notefall88-factory-*.zip`，用包内校验脚本通过 UART 口完成单文件首刷。factory 包会清除 NVS 中的设备配置、Wi-Fi 和灯位校准；日常升级应使用 `notefall88-update-*.zip`，不要反复刷 factory 镜像。

## 目标与威胁边界

NoteFall 可选加入家庭 Wi-Fi，因此“同一局域网里能打开网页”不能等于“有权刷固件”。写入接口同时要求：

1. 家庭 STA 与永久 SoftAP 两条路径都可更新，二者都必须提供设备管理密码；
2. `X-NoteFall-Admin` 必须与当前热点密码恒定时间比较一致；密码不会进入 URL、日志、状态或响应；新密码在网页和固件两端都按 UTF-8 字节计数，必须为 8–63 字节；
3. 文件必须通过目标分区和 Arduino Update 的固件/写入校验。

默认管理密码公开在仓库中，不应被视为多人网络中的长期秘密；当前单用户实机可暂时保留。所有写接口在家庭 LAN 和救援热点上都要求同一个管理密码，浏览器只长期保存随机控制令牌，不保存明文密码。它不是密码学签名启动链，不能防止掌握管理密码的攻击者。签名镜像若成为量产要求，应在锁定硬件后启用 ESP32 Secure Boot 与 Flash Encryption，并建立不可丢失的签名密钥流程，不能在原型阶段草率熔断 eFuse。

## 分区与失败行为

| 分区 | 大小 | 行为 |
|---|---:|---|
| `app0` / `app1` | 各 `0x280000`（2.5 MiB） | 固件写入非运行 OTA 槽，成功后切换启动槽 |
| `littlefs` | `0x2E0000`（2.875 MiB） | 独立网页镜像 |
| `nvs` | `0x5000` | 校准、家庭 Wi-Fi 和热点密码；正常 OTA 不覆盖 |

更新开始前固件会清除目标灯、取消伴奏排程并发送 16 通道 Sustain Off / All Notes Off。浏览器只有收到设备 `{ok:true,written:...}` 才显示成功；超时、断线或非 JSON 响应均保持“不确定/失败”，不会把上传进度 100% 当成写入成功。

如果新固件无法完成启动与真实网络访问，它会在 90 秒内自动回滚；上传中途失败不会切换启动槽。若普通网页损坏，使用固件内置的 `http://192.168.4.1/recovery` 重刷。只有两个 OTA 槽和救援页都遭到异常破坏时才需要 UART。不要用反复断电尝试“碰运气”，也不要在电源不稳、灯带过热或 USB 反复掉线时更新。

## 发布包

合法版本标签触发 `.github/workflows/release.yml`：重复运行 Python、网页覆盖率、Chromium/WebKit、固件和 LittleFS 门禁，再发布：

- `notefall88-update-<tag>.zip` 与 `manifest.json`：已装设备的双槽 OTA；
- `notefall88-factory-<tag>.zip` 与 `factory-manifest.json`：全新 N8R8 的单文件 UART 首刷；
- `notefall88-manufacturing-<tag>.zip` 与 `manufacturing-manifest.json`：线束、机械和制造资料。

构建中间的裸 `firmware.bin` 和 `littlefs.bin` 不单独作为 Release 附件，避免用户把 OTA 镜像误写到地址 `0x0`。`vMAJOR.MINOR.PATCH-rc.N` 必须与固件版本匹配并自动标为 Pre-release；每个标签还必须有同名人工发布说明。

`manifest.json` 是版本 1 信封，记录产品名、固件版本、协议、分区表 SHA-256，以及两个 OTA 镜像的目标、字节数和 SHA-256。factory 清单另外逐项记录 bootloader、分区表、OTA 初始数据、应用和 LittleFS 的偏移、大小与哈希；合并结果已经与 esptool 4.5.1 独立 `merge_bin` 输出交叉验证。三类 ZIP 都固定包含项目 `LICENSE` 与 `THIRD_PARTY_NOTICES.md`，并在清单中记录字节数与 SHA-256。这样从 Release 单独取得二进制或制造资料的人也同时取得 MIT/BSD/LGPL 等适用声明。可在本地复现 OTA 包；首刷包参数见 `scripts/package_factory.py --help`：

```powershell
python scripts/package_update.py `
  --firmware C:\path\to\firmware.bin `
  --filesystem C:\path\to\littlefs.bin `
  --output dist\notefall88-update.zip
```

在 PX-S7000 实机验收、温升和断电恢复通过前不打正式稳定版标签；草稿 PR 的 CI 成功不等于物理发布许可。

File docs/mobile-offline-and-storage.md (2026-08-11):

# 手机/平板离线与本地数据

## 当前可证明的离线方式

NoteFall Core 的完整 HTML、压缩 JavaScript、CSS 和乐谱渲染资源都位于 ESP32 LittleFS。手机连接 `NoteFall-88` 热点后访问 `http://192.168.4.1`，即使没有互联网也能重新加载页面；这不是依赖云端缓存的“离线模式”，而是设备本身提供网页。

不要对 ESP 热点上的 **Core** 承诺 Service Worker/PWA 离线缓存。Service Worker 通常只允许 HTTPS 或 `localhost` 安全上下文，而 Core 使用局域网 HTTP 地址。独立 **Studio PWA** 已生成版本化预缓存清单，把 HTML、JS、CSS、OSMD、图标和 manifest 全部纳入；但 HTTPS Studio PWA 访问本地 `ws://` 设备仍可能受混合内容策略限制，因此练琴平板推荐随资源打包的 Android/iOS App，PWA 作为电脑和临时设备备用。

## 哪些数据保存在手机

- 曲库：当前页面 origin 下的 IndexedDB；Studio 高级格式会保存规范化 MusicXML，原生 MIDI 则同时保存原事件文件与用于五线谱显示的 MusicXML 伴侣；
- 练习历史：独立 IndexedDB，最多 500 次，每次最多 20,000 个判定事件；
- 常用练习选项：localStorage；
- ESP 的亮度、灯位和 Wi-Fi 配置：设备 NVS，不在浏览器备份中。

浏览器数据按 origin 隔离。`http://192.168.4.1`、开发电脑的 `http://localhost`、Studio PWA 和 Studio App 是不同数据域，不能假定自动共享。清除站点数据、卸载浏览器、私密模式结束或系统存储压力都可能删除非持久数据；跨发行物迁移必须使用版本化备份。

## 页面提供的保护

“我的曲库”显示浏览器报告的已用空间、配额和持久化状态。“保护本地数据”只在用户点击后调用 Storage Persistence API：

- 获准后显示“已获持久存储保护”；
- 浏览器拒绝或 HTTP 环境不支持时，页面继续工作并提示保留备份；
- 配额不足、私密模式或站点存储被禁用时，曲库和练习历史显示可执行的中文错误，不把失败伪装成保存成功。

持久化不是备份。曲库使用“导出曲库备份/恢复曲库备份”，练习历史在练习选项中单独导出 JSON。两个入口故意使用不同名称，因为当前不存在一个已经验证可原子恢复两套数据库与 ESP NVS 的全系统备份。

## 实机验收

至少在计划长期使用的 iOS/Android 浏览器各执行一次：

1. 连接 `NoteFall-88`，打开页面并导入一首测试乐谱；
2. 打开“我的曲库”，记录容量、持久化状态和是否获准；
3. 断开互联网但保持 ESP 热点，强制关闭浏览器后重新打开页面；
4. 确认页面资源、曲库和练习功能仍可用；
5. 导出曲库备份，删除测试乐谱，再恢复并核对文件 SHA-256；
6. 在浏览器测试环境模拟配额不足，确认页面提示备份与清理建议且已有数据不被删除。
7. 实时播放、预备拍、Follow 两组音之间、乐谱示范、录音回放及录音过程中分别锁屏或切换 App；实体目标灯应熄灭、钢琴伴奏/示范/回放不得挂音，返回后不得把后台时间计为漏键，也不得自动发声；若正在录音，应明确停止并可下载已保存部分。

若浏览器把无互联网热点自动切回蜂窝网络，应关闭该网络的“自动切换/智能网络”或明确选择继续连接；这是手机联网策略，不是 ESP USB 或灯带故障。

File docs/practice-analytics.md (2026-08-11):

# 练习分析与本地历史

NoteFall 不把“成绩”压成一个无法解释的百分比。每个判定保留为语义事件，再从同一事件流计算页面指标和历史记录。这样界面、导出文件和自动测试使用同一套定义。

## 事件与会话

一次非空会话包含：

- 乐谱名称、原始文件 SHA-256 内容身份、练习模式、声部、速度倍率、移调半音数和可选 A–B 范围；
- 正确音：MIDI 音高、实弹力度、谱面目标力度、目标时间、声部，以及实时模式下的有符号时序差；
- 错键：实际 MIDI 音高、力度和当时谱面时间；
- 漏键：目标 MIDI 音高、声部和目标时间；
- 开始/结束时间、墙钟时长、聚合指标和被安全上限丢弃的事件数。

复位、切换模式/声部/循环/移调或自然完成会结束当前非空会话。只打开乐谱、拖动设置但没有演奏或漏音，不生成空历史。

## 指标定义

| 指标 | 定义 |
|---|---|
| 准确率 | `命中 / (命中 + 错键 + 漏键)` |
| 时序差 | `实际 Note On 时间 - 目标起点`；负数偏早，正数偏晚 |
| 平均时序误差 | 所有实时命中的 `abs(时序差)` 算术平均 |
| P95 时序误差 | 绝对时序误差从小到大排列的 nearest-rank 95 百分位 |
| 拍点偏置 | 有符号时序差算术平均；用于判断整体偏早或偏晚 |
| 力度波动 | 所有命中 Note On 力度的总体标准差 |
| 力度基准偏移 | 所有带目标力度命中的 `实弹力度 - 目标力度` 平均；用于识别整台琴或演奏者普遍偏轻/偏重，不直接惩罚相对强弱轮廓 |
| 力度轮廓分 | 至少 4 个目标样本且谱面目标标准差至少 4 时计算；先移除会话级力度基准，再组合目标/实弹 Pearson 正相关（60%）与基准校正后的平均绝对残差（40%），限幅到 0–100 |
| 时值覆盖分 | 至少 4 个完整松键样本；对每音取 `min(踏板释放后的发声时长 / 谱面目标时长, 1)` 后平均。只惩罚声音过早消失，不把可能合理的踏板延长冒充错误 |
| 无踏板释放精度 | 至少 4 个未由 CC64 延长的样本；以实际按键时长与目标时长的对数比例计算，±15% 作为满分容差，半长/双长附近降至 0 |
| 提前收音率 | 发声时长不足目标 80% 的完整样本比例；进入复盘时间轨和弱点巡回 |
| 踏板延长 | 同时报告由踏板延长的音符数与 `发声时长 - 物理按键时长` 平均值；在缺少可靠踏板记号时不评价“踩得对不对” |
| 和弦展开宽度 | 只对乐谱起点相同、无漏音且至少两个唯一琴键都有实时 `timingMs` 的完整和弦取 `最晚落键 - 最早落键`；相邻琶音不合并，残缺和弦不产生虚假好成绩 |
| 谱面踏板 | MusicXML `pedal` 与 `sound damper-pedal` 解析为踩下、松开、换踏和半踏目标；CC64 阈值边沿与连续深度在 ±450 ms 内一对一匹配，误差按练习速度换算成真实毫秒；A–B 每遍独立判定，至少两个目标才发布综合分 |
| 和弦整齐度 | 至少 4 个完整和弦样本；展开不超过 30 ms 为满分，30–120 ms 线性降到 0，同时报告平均值、P95 与超过 70 ms 的松散和弦数 |
| 双手同步 | 同一跨手和弦内取 `右手平均落键 - 左手平均落键`；正值表示右手晚，负值表示左手晚。至少 4 个跨手样本才发布 0–100 同步分 |
| 最长连续命中 | 按事件顺序计算；错键或漏键会中断连续段 |
| 难点键 | 按每个 MIDI 音高汇总错键与漏键，先按错误次数、再按错误率排序 |

等我弹与跟随我没有外部播放时钟，因此不会伪造节奏精度或和弦同步分；它们仍统计准确率、力度、连续命中和难点键。

## 可视化复盘与趋势

- 进行中的练习以及最后完成的一次练习都生成 24 段时间轨与 88 键热区：绿色为命中，黄色为力度轮廓偏差、提前收音、松散和弦或踏板时机偏差，红色为漏音、错音、漏踏或多余踏板动作集中的位置。时间段提示会列出时值覆盖、提前收音、和弦展开、双手先后与踏板命中/偏差；点击任何时间段会把它精确设为下一轮 A–B，这是从统计回到可执行练习的桥梁。
- 每条历史记录可重新打开为同一种复盘。当前乐谱的内容 SHA-256 相同，才允许从历史时间段建立循环；乐谱不同仍可阅读历史，但按钮被禁用，绝不把旧曲目的秒数套到新曲目上。
- 进步轨迹最多显示同一内容身份的最近 12 次练习。准确率、绝对时序误差、有效力度轮廓、时值覆盖和和弦整齐度分别取最早与最新各最多三次的平均作比较；少于两次时只展示数据、不声称有进步。绝对时序误差变小，其余分数变大才记作正向改善。
- 瀑布流的 `✓`、`×`、`!` 是逐键、短暂的即时判定提示；其目的是让演奏者在不低头看统计卡片时发现问题，并不替代已保存的事件记录。

## 小节重新开始

MusicXML/MXL 五线谱或分屏视图会显示播放顺序的小节轨；反复后的同一书写小节仍作为不同播放 occurrence 保留。一次点击选择 A、第二次点击建立包含两个端点的整小节循环。若 A–B 未开启，可点击“从 A 开始”结束当前非空会话，并从该小节开始全新的判分会话。

此跳转不是简单改变动画时钟：实时 matcher 会从目标位置重置游标，不把前面跳过的音符累计成漏音；Wait/Follow 也会定位到该位置的下一个和弦。A–B 开启时显式禁用任意小节跳转，避免已筛选的循环和弦集与新的全曲位置混用。

## 存储、容量与隐私

- 历史使用独立 IndexedDB，最多保留最近 500 次；超限自动删除最旧记录。
- 单次最多保留 20,000 个事件；若极端长练习超过上限，会累计 `droppedEvents`，不会无限占用内存。
- JSON 导出信封带 `product`、`version` 和 `exportedAt`，便于以后迁移；当前版本为 2。
- 历史不会自动离开手机/平板/电脑，不含 Wi-Fi 密码、原始乐谱文件、USB 描述符或设备标识。
- 清除浏览器站点数据会删除历史，因此长期保存应定期导出 JSON。

## 自适应教练

教练只比较原始文件 SHA-256 完全相同的乐谱，最多使用最近 20 次记录；两份同名但内容不同的乐谱不会串曲。版本 1 的旧记录没有内容身份，仍可查看和导出，但不会在当前已知内容身份的乐谱中被猜测性合并：

1. 在谱面时间轴上扫描 4–12 秒窗口，漏键权重为 2、错键权重为 1；综合错误量、错误率、证据量和错误在窗口中央的程度，选择最值得重复的 A–B 段。
2. 分别计算有明确声部的左右手错误率；差距不足 10 个百分点时保持双手，避免用很少的数据武断拆手。
3. 准确率低于 70% 时建议“等我弹”并降一档；准确率或平均绝对时序未稳定时维持/降低实时速度；若音高和拍点已稳定但力度轮廓低于 60%、时值覆盖低于 75%、释放精度低于 60% 或和弦整齐度低于 65%，先降 5% 定向修正；这些指标没有反证时才允许升速。
4. 页面显示使用了多少次练习、多少个事件、历史准确率、可用的力度/时值/释放/和弦/双手分和低/中/高置信度。弱点巡回会把连续提前收音变成 `时值覆盖 ≥85%` 关卡，也会把松散和弦变成保持实时模式的 `和弦整齐度 ≥80%` 关卡；100% 音高准确率不能绕过表达或同步门槛。没有当前曲目的证据时不生成建议。

算法是确定性的规则系统，不宣称医学、教育学或机器学习结论；所有理由都能由导出的事件复算。

## 跨曲目今日练习

曲库面板会把单曲教练提升为跨曲目队列。它只使用原始文件 SHA-256 完全一致、没有 A–B 循环且判定事件达到目标音数 60%（至少 4 个）的记录；局部刷分、同名异谱和只练几个音不会被算作整曲掌握。

- 最近三次完整记录按 55% / 30% / 15% 加权；准确率是主轴，实时拍点与可用的力度、时值、和弦、谱面踏板分作为补充，缺失的表现力轴不会被当成零分。
- 综合掌握低于 70% 时约 6 小时后优先重练，低于 82% 时隔天重练；稳定记录连续出现后按 1、3、7、14、30、60 天延长复习间隔。
- 每次最多显示三首到期曲目，薄弱曲优先于普通复习，普通复习优先于新曲；若今天没有到期项，只显示最早到期的一首并允许提前练。
- 每一项显示来源清楚的掌握度、预计分钟数和安排理由；点击“开始”打开原始曲目和练习面板，不产生云账号、遥测或不可解释的机器学习分数。

## 自动验证

纯函数测试用固定事件验证拍点偏置、平均/P95、力度基准/轮廓、Note Off/CC64 分离、同音重触发、时值覆盖/释放、和弦分组边界、双手方向、连续命中和难点排序；`fake-indexeddb` 测试验证持久化顺序和版本化导出。真实浏览器回归用目标 `[40,60,80,100]` 与一致 `+10` 的实弹样本验证“轮廓 100% / 基准 +10”，用四个完整目标时值验证“覆盖 100% / 释放 100% / 未检测到踏板延音”，并用四个 20 ms 跨手和弦验证“和弦 100% / 右手晚 20 ms”，同时检查 390×844 页面无横向溢出、历史面板可滚动且不会遮住关闭按钮。

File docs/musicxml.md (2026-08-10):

# MusicXML、MXL 与五线谱边界

NoteFall 对一个乐谱保留两种互补表示：

- OSMD 读取原始 MusicXML，负责高质量五线谱排版与小节光标；
- NoteFall 自己的解析器生成统一秒时间线，供目标灯、瀑布流、左右手筛选、循环和判分使用。

两者共享同一份原始文件，但职责不同。不能从屏幕“看起来正确”推断目标时间线一定正确，因此解析器和真实曲目都需要单独测试。

## 当前支持

- `.xml`、`.musicxml` 和压缩 `.mxl`；根格式为 `score-partwise`；
- divisions、普通/加法/复合拍号、自由节拍、多个 part、多个 staff/voice、backup/forward、和弦、休止符、静默 cue 和装饰音近似时值；
- 升降音、八度、chromatic + octave-change transpose、速度变化；`metronome` 的 beat-unit、附点和 per-minute 会换算为四分音符 BPM；两个普通/附点 beat-unit 的 metric modulation 会按当时速度精确换算，并在反复后重新执行；
- `sound dynamics` 百分比和常见动态记号会换算为 MIDI 力度；可按 staff 保留左右手不同力度；
- tie start/stop 合并，避免连音被当成重复目标；
- 前向/后向反复、`times` 次数、第一/第二等多结尾，以及标准 `sound` 属性表达的 D.C./D.S./Fine/To Coda/Coda；统一时间线按真实演奏顺序展开；
- 展开后的每个播放小节保留原书写小节索引，每个目标音符保留小节内拍位置；OSMD 光标在同一小节内逐音前进，并在反复和跳转时回到正确的印刷位置；
- staff 2 默认左手，staff 1 默认右手；单谱表再结合声部名称和中央 C 做保守推断；
- MXL 读取 `META-INF/container.xml` 指定的根文件；
- 源文件与解压总量各限 32 MiB，并在解压前检查 ZIP 中央目录声明，拦截明显 zip bomb；
- OSMD 首次选择五线谱时才动态加载，手机瀑布流首屏不承担其解析成本。
- 用户移调时 NoteFall 时间线和 OSMD `TransposeCalculator` 同步更新，原始 MusicXML 与曲库哈希保持不变。
- 展开后的每个播放小节按当时的普通、`3+2/8` 加法或多组复合拍号生成强弱拍标记，再通过同一速度转换器变成秒；`senza-misura` 不虚构点击。节拍器因此能随反复回到正确拍号/速度，而不是用固定 BPM 覆盖乐谱。
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

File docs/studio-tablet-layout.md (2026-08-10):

# Studio 平板布局

NoteFall Studio 的主力现场视口是放在谱架上的 3:2 横屏平板。当前实机目标为用户的 Xiaomi Pad 7 Ultra（16 英寸、3200×2136、275 PPI，实际宽高比约 1.498:1）；布局不绑定商品名、物理英寸或单一像素宽度，而按浏览器实际 CSS 视口和宽高比匹配，因此 Android 的显示大小、DPR 或浏览器工具栏变化不会让规则失效。在 2× DPR/显示缩放下，该面板对应 1600×1068 CSS px，这就是自动化使用此视口的原因。

## 3:2 工作台规则

当横向 CSS 视口至少 1000 px，且宽高比位于 7:5 到 8:5 之间时：
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

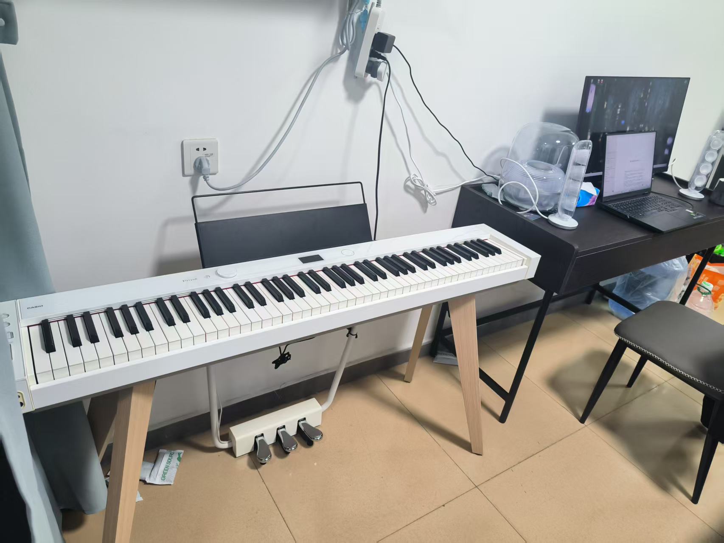
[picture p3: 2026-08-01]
piano_img/left.jpg

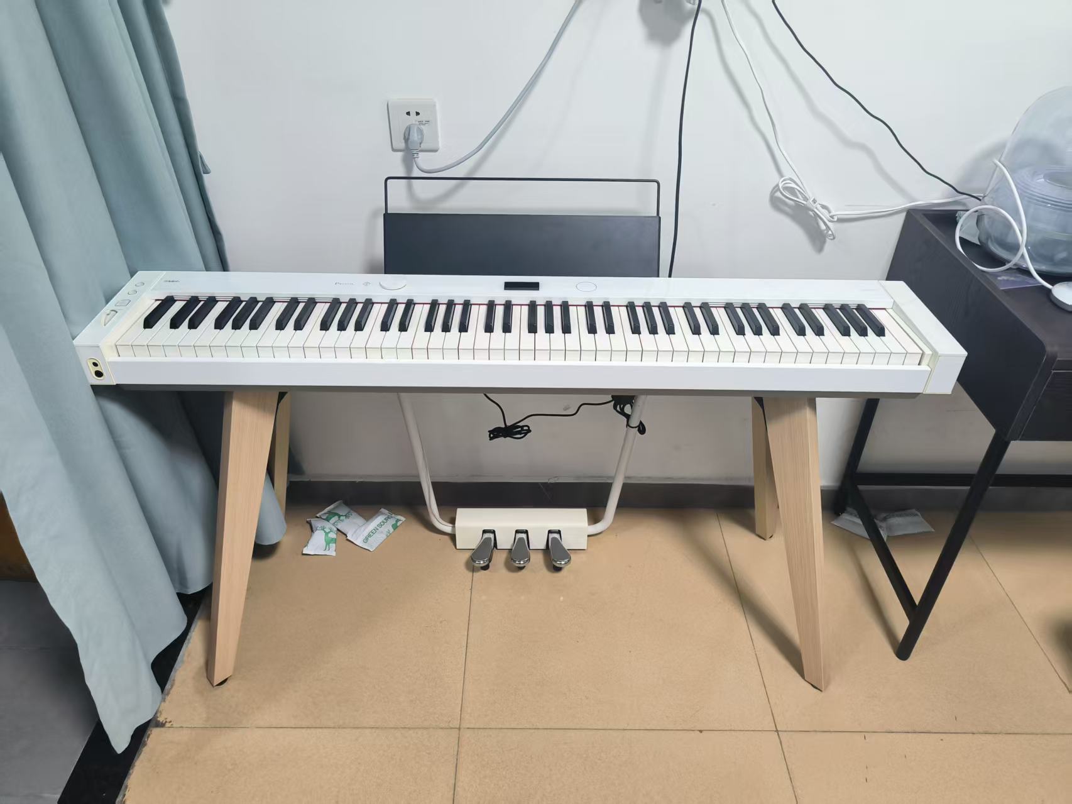
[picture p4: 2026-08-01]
piano_img/front.jpg

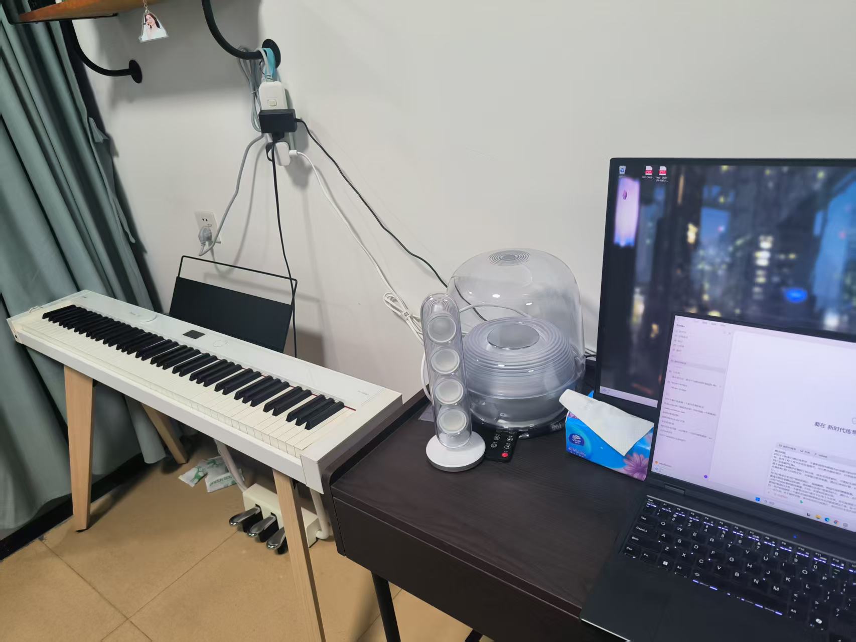
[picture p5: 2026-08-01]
piano_img/right.jpg

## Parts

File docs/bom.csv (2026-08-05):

类别 | 物料 | 规格 | 数量 | 是否最终件 | 淘宝搜索词 | 参考单价人民币 | 备注
控制 | ESP32-S3-DevKitC-1 | 乐鑫官方 N8R8 双 Micro-USB | 1 | 是 | ESP32-S3-DevKitC-1 N8R8 乐鑫 | 已有 | 用户已有
灯光 | APA102C 或 SK9822 灯带 | 5V 144灯每米 黑色PCB IP30 连续2米 | 1 | 是 | 5V 144灯 APA102 SK9822 黑板 IP30 | 120-260 | 最终裁到176灯约1.222米；余料作维修备件
信号 | 74AHCT125电平转换模块 | 5V供电 成品模块 | 1 | 是 | 74AHCT125 四路 电平转换 模块 | 8-25 | DATA和CLOCK各用一路
电源 | 成品电源适配器 | 5V 5A 有3C或同等认证 DC5521 | 1 | 是 | 5V5A 3C 电源适配器 DC5.5 2.1 | 35-80 | 整机唯一低压电源；禁止裸板电源
电源 | DC5521母座配电线 | 一进三出 20AWG 带绝缘和应力释放 | 1 | 是 | DC5521 母 一分三 20AWG 定制线 | 15-35 | 让线束店按harness.csv制作
保护 | 带座保险丝线 | 3A 汽车片式或慢断低压保险 | 1 | 是 | 3A 低压 保险丝座 线束 | 5-15 | 紧靠电源输入并保护全部下游；避免电容上电浪涌误熔断
保护 | 备用保险丝 | 同规格3A | 2 | 是 | 3A 保险丝 | 2-5 | 不可换成更大规格
保护 | 电解电容 | 1000uF 10V 低ESR 已焊引线并绝缘 | 2 | 是 | 1000UF 10V 低ESR 电解电容 引线 | 4-12 | 灯带首尾各一只
USB | 供电型OTG Y线 | Micro-USB公转USB-A母并带Micro-USB供电口 | 1 | 是 | Micro USB OTG 一分二 USB母 独立供电 | 5-20 | 用户已有；公头接开发板USB或OTG口，第三口由H7供电但不能给开发板反向供电
USB | 5V电源转Micro-USB供电线 | 配电端子转Micro-USB公 仅接VBUS/GND | 2 | 是 | DC5521 转 Micro USB 供电线 | 10-30 | H5接开发板USB-to-UART口；H7接OTG Y线第三口；两根均来自同一保险后5V
USB | 打印机数据线 | USB-A公转USB-B公 1至2米 | 1 | 是 | 打印机数据线 USB A公 B公 | 10-25 | 接PX-S7000 USB TO HOST
连接 | Micro-Fit 3.0兼容4芯锁扣公母线 | 4P 预压端子 带尾线 | 1对 | 是 | Micro-Fit 3.0 4P 公母 预压线 | 15-35 | 灯带输入：5V GND DATA CLOCK；供电侧用凹端子
连接 | XT30公母预焊线 | 20AWG 额定不低于10A | 1对 | 是 | XT30 公母 带线 20AWG | 8-15 | 灯带远端注电；供电侧用凹端子
线材 | 红黑硅胶线 | 20AWG 各2米 | 1套 | 是 | 硅胶线 20AWG 红黑 | 15-30 | 首尾注电
线材 | 双芯信号线 | 26AWG 绿蓝各1米 | 1套 | 是 | 硅胶线 26AWG 绿 蓝 | 8-15 | DATA/CLOCK；不得承担灯带电流
信号 | 串联电阻 | 100欧姆四分之一瓦 已焊引线并绝缘 | 2 | 是 | 100欧姆 1/4W 电阻 引线 | 1-3 | 靠近74AHCT125输出端
绝缘 | 热缩管与柔性护边 | 多规格热缩管 加控制盒开口U型护边 | 1套 | 是 | 热缩管 U型护边条 1mm | 8-20 | 所有焊点和壳体出线口
紧固 | 尼龙扎带 | 2.5mm宽 可重复或普通型 | 10 | 是 | 尼龙扎带 2.5mm | 5-10 | 板卡和线缆应力释放
紧固 | M3自攻螺钉 | M3x10 塑料用圆头 | 4 | 否 | M3x10 塑料 自攻螺丝 | 3-8 | 仅打印控制盒盖使用
结构 | 黑色PET或PVC薄载体 | 约1226x14x0.8毫米 卖家裁好 | 1 | 否 | 黑色 PET 硬片 0.8mm 裁条 | 10-30 | 灯带可拆载体；不遮挡灯珠
结构 | 拉伸移除式无痕固定条 | 薄型带外露拉伸尾片 | 3至5片 | 是 | 无痕固定条 拉伸移除 | 10-30 | 先做24小时表面兼容测试
结构 | 控制盒打印件或成品盒 | 黑色PETG 112x76x25毫米外廓 | 1 | 否 | 电子项目盒 通风 或 3D打印 PETG | 15-45 | 生成STL/STEP；琴键侧没有打印导轨
工具 | 数字万用表 | 通断蜂鸣和直流电压 | 1 | 否 | 数字万用表 自动量程 | 已有或30-80 | 装机前必用
工具 | 接触式温度计 | 量程至少0至100摄氏度 | 1 | 否 | 接触式 温度计 探头 | 20-50 | 可借用

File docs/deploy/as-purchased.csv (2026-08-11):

状态 | 类别 | 物料 | 已购数量或规格 | 项目用途 | 到货必须确认 | 处置
已有 | 控制 | ESP32-S3-DevKitC-1 | 乐鑫官方 N8R8 | USB Host与灯带控制 | 丝印为N8R8且两个Micro-USB口完好 | 保留为最终件
已有 | USB | 供电型OTG Y线 | Micro-USB公头加USB-A母口加Micro-USB供电口 | 连接ESP32原生USB Host与钢琴 | 三个接口类型正确且无破损；第三口只向USB-A外设侧供电 | 保留为最终件
已到待验 | 灯光 | SK9822灯带 | 5V 144像素每米；176灯为32+72+72三段焊接；照片中PCB呈白色；物理左端2线右端4线 | 覆盖88键的单排提示灯 | 通电前复核宽度、DIN/CIN方向、四焊桥隔离和头尾线定义；照片拟合两缝中心距11.17/10.92mm | 不再裁剪；台架逐灯与温升通过后保留为最终件
已买未到 | 电源 | 5V 5A适配器 | DC5521 | 整机唯一电源 | 铭牌5V/5A与认证；插头5.5x2.1；空载极性和电压 | 通过验收后为最终件
已买未到 | 电源 | DC015圆座 | 匹配DC5521 | 低压电源入口 | 中心针尺寸与正负极；接线端无松动 | 通过验收后为最终件
已买未到 | 保护 | 3A保险丝与保险座 | 含备件 | 保护所有下游5V支路 | 保险规格；保险座线径和绝缘；拔保险后下游断路 | 通过验收后为最终件
已买未到 | 保护 | 1000uF电解电容 | 2只且耐压不低于10V | 灯带首尾缓冲 | 容量和耐压；负极条纹；引脚无折断 | 通过验收后为最终件
已买未到 | 信号 | 100欧四分之一瓦电阻 | 2只 | DATA与CLOCK串联阻尼 | 阻值万用表抽测；引脚无折断 | 通过验收后为最终件
已买未到 | 连接 | KF301-2P共点端子 | 10只 | 局部连接与公共配电 | 商家已确认所购具体款可以共点；到货查清共点方向并逐孔蜂鸣；确认是否自带底板或仍有待焊直脚 | 复核通过后按实际共点结构使用；不按通用裸KF301外观猜接
已买未到 | 连接 | KF301-3P共点端子 | 10只 | 局部连接与公共配电 | 商家已确认所购具体款可以共点；到货查清共点方向并逐孔蜂鸣；确认是否自带底板或仍有待焊直脚 | 可与2P组合成所需节点但每个节点必须实测记录
已买未到 | 信号 | 74AHCT125N | DIP-14裸芯片 | 3.3V到5V DATA与CLOCK电平转换 | 完整料号必须含AHCT；方向缺口和引脚无损 | 只在面包板完成G1；最终装机前转成可靠焊接小板
已买未到 | 原型 | 170孔面包板 | 1块 | 74AHCT125N台架验证 | 中间沟槽可跨接DIP-14且接点夹持可靠 | 仅G1台架使用
已买未到 | 原型 | 杜邦线 | 公对公和母对公若干 | 低电流台架信号 | 插头夹持和导通 | 不得承担灯带主电流或作为最终装机线
已买未到 | USB供电 | Micro-USB公头供电线 | 2根H5和H7 | 从保险后5V分别给ESP32和Y线外设侧供电 | 确认裸线或输入端定义；逐线查出VBUS与GND；D加D减和ID不得误接 | 通过极性测试后使用
已买未到 | 线材 | 20AWG红黑硅胶线 | 各2米 | 灯带双端注电和电源主干 | 实测线径或铜截面；柔软无破皮 | 保留为最终线材
已买未到 | 线材 | 26AWG绿蓝硅胶线 | 各1米 | DATA与CLOCK | 导通且无破皮 | 保留为最终线材
已买未到 | USB | USB-A公转USB-B公打印机线 | 1根 | OTG Y线到PX-S7000 USB TO HOST | 两端接口和数据四芯导通 | 保留为最终件
已买未到 | 结构 | 3D打印控制盒 | 托盘与盒盖 | 收纳控制板与线束 | 尺寸和开口；无翘曲开裂；不挤压USB插头 | 台架通过后再装
已买未到 | 紧固 | M3x10塑料螺丝 | 4只 | 控制盒盖 | 与打印孔匹配且不过长 | 匹配后使用
已买未到 | 安装 | 拉伸移除式无痕固定带 | 3至5片 | 可拆固定灯带 | 包装用途与保质状态；先在隐蔽位置做24小时相容性测试 | 通过M1后使用
已买未到 | 工具 | 剪刀 | 1把 | 裁纸样和辅料 | 工作正常 | 不用于带电操作
已买未到 | 工具 | 数字万用表 | 1只 | 通断电阻与直流电压验收 | 通断蜂鸣和直流档工作正常；表笔绝缘完好 | 到货验收必需
待到货判定 | 绝缘 | 热缩管或等效绝缘 | 未采购 | 隔离元件裸脚与出线口 | 现有盒内是否仍有任何可触及裸导体 | 若存在则正式上电前补齐
待到货复核 | 配电 | KF301公共节点实现 | 使用已买KF301-2P和3P | 建立保险后5V与GND公共节点 | 商家已确认可共点；到货必须画出并蜂鸣确认共点关系；若与说明一致则无需补买配电端子 | 共点关系未记录前不得上电
待补必需 | 信号 | 0.1uF陶瓷去耦电容 | 1只 | 74AHCT125N的14脚到7脚就近去耦 | 容量约100nF且耐压不低于10V | 裸芯片台架上电前补齐或从可靠电子套件中取用
待G1判定 | 工具 | 接触式温度计 | 可借用 | 完成温升门禁 | 能稳定测量0至100摄氏度 | 最迟G1连续运行测试前准备

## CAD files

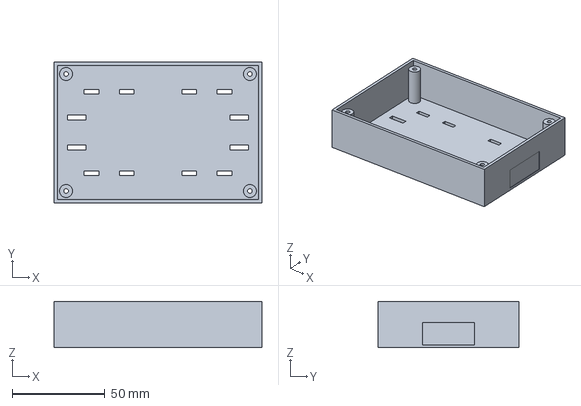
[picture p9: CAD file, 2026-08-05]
mechanical/exports/controller_tray.step
112.0 x 76.0 x 25.0 mm

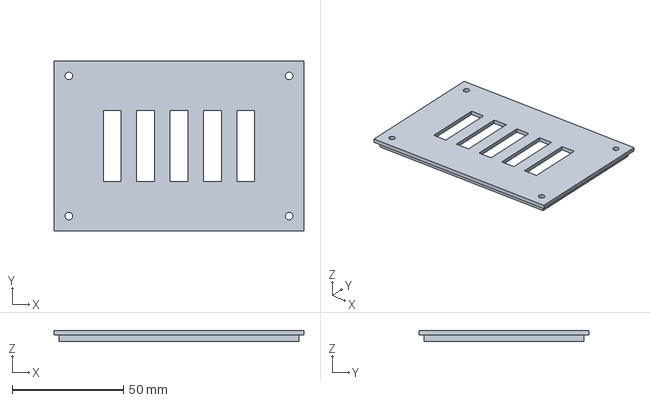
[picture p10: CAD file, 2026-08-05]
mechanical/exports/controller_lid.step
112.4 x 76.4 x 5.00 mm

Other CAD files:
mechanical/exports/controller_lid.stl
mechanical/exports/controller_tray.stl

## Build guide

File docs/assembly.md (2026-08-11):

# 装配说明

这是一套最终尺寸的单排灯系统。琴键侧使用一条逻辑连续的 176 灯串，竖直、裸露地安装在琴键后方固定立面上，不使用贯穿全长的打印导轨、黑色挡边或扩散盖。已购实物由 `32 + 72 + 72` 三段 PCB 焊成一条串行链，软件按两个物理焊缝建模。

## 1. 下单前只做一次现场复核

照片审查已确认琴键后方有约 18–22 mm 高的连续固定立面。按 [现场复核表](measurements.md) 用 `12 × 100 mm` 纸条在 C4 附近试放并全按相邻黑白键；通过后才能正式粘贴。此检查只验收安装间隙，不改变灯带、控制板或软件。

## 2. 只打印可选控制盒

- 琴键侧打印件：0 件。
- 可选控制盒：`controller_tray.stl` 和 `controller_lid.stl` 各 1 件。
- 材料：黑色 PETG；喷嘴 0.4 mm；层高 0.20 mm；4 周壁；顶/底 5 层；填充 20%。
- 盒盖不是松放平板：定位裙边插入托盘，四角用 `M3×10` 塑料自攻螺钉固定。先空拧攻丝一次，再装电子件；不得过度拧紧使层纹开裂。
- 如果不需要美观外壳，也可以把控制模块固定在有通风孔的成品塑料盒中，完全不进行 3D 打印。

## 3. 灯带准备

1. 断开所有电源。当前已购灯带已经是 176 灯成品，不再裁剪或重焊；从物理左端复核三段数量为 `32 + 72 + 72`，两个接头不得短路、翘起或在轻压时活动。若未来重新采购连续卷材，才从标有 `DIN/CIN` 的输入端数出 176 灯并只在第 176 与 177 灯之间剪一次。
2. 确认灯带箭头从控制盒端指向远端。当前照片中四线端位于物理右侧、箭头向左，因此网页校准时预计需要打开“灯带方向反向”；最终仍以 A0/C4/C8 三点测试为准。灯带不折叠、不打孔，发光面不得覆盖透明胶、扩散膜或打印挡边。
3. 如果不希望灯带自带背胶接触钢琴，可把灯带先贴到卖家裁好的黑色 PET/PVC 薄片上：约 `1226 × 14 × 0.8 mm`。薄片只是平直载体，不包裹灯带。
   当前拼接灯带按照片透视拟合总长约 `1230.42 mm`，使用 `1226 mm` 载体时允许两端各约 `2.2 mm` 的柔性 PCB 伸出；两个刚性焊点必须全部落在载体支撑范围内，不能位于载体边缘或固定条弯折处。
4. 灯带输入端留至少 60 mm 软线弯并做应力释放；拉动外部线缆时不得把力传到灯带焊盘。

## 4. 让卖家代焊的线束

把 [线束制造表](harness.csv) 和 [线束图](wiring-harness.svg) 发给灯带卖家、线束店或手机维修店，并明确要求：

- 灯带输入端焊 `5V、GND、DATA、CLOCK` 四线，输出端只焊 `5V、GND` 两线；
- DATA、CLOCK 各串联 100 Ω；1000 µF 电容在首尾各一只，电容负条纹接 GND；
- 所有焊点套热缩管，完成通断、5V-GND 短路与拉力检查；
- 输入使用 Micro-Fit 4P 锁扣（5V/GND/DATA/CLOCK），远端注电使用 XT30 2P；供电侧均为凹端子，不用松动的杜邦线作为永久连接；
- 线色、线径、长度、引脚号和逐项验收完全按 `harness.csv`，不得由装配者现场猜线。

## 5. 无损安装

1. 钢琴断电，用干燥超细纤维布清除琴键后方固定立面的灰尘，不使用酒精或强溶剂。
2. 逐个按下最高的黑键，确认安装面不随琴键运动。
3. 灯带 PCB 竖直，与键面约成 `90°`；发光面朝演奏者，底边距离自然状态键面约 `2–3 mm`，前方完全无遮挡。
4. 不得覆盖红色毡条，不得让灯带、载体或线束接触任何活动琴键。
5. 固定方式必须先在最右端不显眼区域做 24 小时材料相容性测试。优先把灯带粘在可拆载体上，再用带拉伸去除尾片的成品无痕固定条固定载体；禁止瞬干胶、热熔胶、泡棉强力双面胶直接接触琴体。
6. 安装后全键强奏并轻拉外部线缆；灯带不得位移、异响或碰键。

安装方向与光束位置见 [裸灯带剖面光路图](optical-installation.svg)。图中的 `2.5 mm` 是名义安装值，不是要求用户在琴上加工出的固定尺寸；实物以 12 mm 纸条全行程无接触为准。

拆卸时先断 5 V，再拔 USB，按固定条厂商说明沿表面方向缓慢拉伸尾片，不向外硬撬。若表面发黏、变色或固定条无法正常拉出，立即停止并由用户决定后续处理。

## 6. 控制盒

ESP32、74AHCT125 模块用尼龙扎带穿过通用托盘槽固定，模块间至少留 5 mm。H5 开发板供电线、H7 Y 线供电线和 OTG 数据线从 36 mm USB 开口出线，Micro-Fit/XT30 从 28 mm 线束开口出线；所有开口加柔性护边，线缆先穿专用扎带槽做应力释放。盒盖上四颗 M3 螺钉前先完成 [上电与测试](testing.md)。

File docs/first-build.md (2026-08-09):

# 第一次装机：用户只需完成的步骤

> 当前这台 PX-S7000 已购买商家确认可共点的 KF301‑2P/3P 端子与 74AHCT125N 裸芯片，不要照本页的通用 BOM 重复购买。包裹到齐后先执行 [本机到货验收清单](deploy/arrival-checklist.md)，用通断档确认 KF301 实物共点关系；通过后回到本页第 1–5 步。通用 Micro-Fit/XT30 厂家代工路线仍保留给其他复刻者。

在硬件到货前，可先从发布页下载 `notefall88-factory-*.zip`；全新 N8R8 板按包内 `FLASHING.md` 首刷，不需要为了烧录安装整套工程依赖。烧录时钢琴、灯带和外部 5V 必须保持断开。

这份清单是完整文档的最短执行路径。用户不需要设计电路、编译算法或焊板；采购件全部进入最终 88 键版本，没有“一八度测试废料”。

## 不需要购买

- MAX3421E 或其他 SPI USB Host 模块；
- 多条短灯带或额外测试灯带；
- 全长 3D 打印灯带盒/导轨；
- 定制 PCB；
- 第二只 5V 电源；
- 树莓派或专用电脑。

## 已有物品

- Casio PX-S7000；
- 乐鑫官方 ESP32-S3-DevKitC-1-N8R8；
- 带第三供电口的 Micro-USB OTG Y 线；
- 笔记本电脑、手机/平板和 Wi-Fi。

## 一次性采购最终件

按 [BOM](bom.csv) 购买，其中最关键的是：

1. 2m 连续 APA102C 或 SK9822，5V、144灯/m、黑色 PCB、IP30 裸板；最终裁 176 灯（约 1.222m），余料只作同批次维修备件；
2. 74AHCT125 成品模块；
3. 有认证的 5V/5A DC5521 电源和 3A 带座保险丝；
4. USB-A 公转 USB-B 公打印机线；
5. H5、H7 两根 5V/GND Micro-USB 供电线；
6. Micro-Fit 4P、XT30、20AWG 电源线、26AWG 信号线、两只 1000µF/10V 电容和两只 100Ω 电阻；
7. 3-5片拉伸移除式无痕固定条；可选 0.8mm 黑色 PET 载体。

## 把焊接一次性交给卖家

将以下三个文件直接发给淘宝线束店、灯带卖家或手机维修店：

- [逐线制造表](harness.csv)
- [生产线束图](wiring-harness.svg)
- [代工消息模板](vendor-order-template.md)

要求卖家完成灯带裁切、首尾注电、DIN/CIN、两只电容、100Ω 电阻、Micro-Fit/XT30 和 H5/H7，逐线蜂鸣与极性检查后发货。用户不焊开发板，也不需要定制 PCB。

## 收货后的五步

### 1. 只烧录 ESP32

电脑接开发板 `UART/USB-to-UART` 口，按 [烧录说明](flashing.md) 写入固件和 LittleFS。手机应看到 `NoteFall-88` 热点并能打开 `http://192.168.4.1`。首次密码是 `notefall88`；进入后立即在“设备维护”修改它，确认诊断显示“已修改默认密码”。

### 2. 只验证钢琴 USB

暂不接灯带。按 [ADR-001](decisions/001-native-usb-host-and-vbus.md) 连接 H5、H7、Y 线和打印机线。打开设备诊断，确认：

- PSRAM 约 8MiB；
- NVS 显示“正常”；
- 复位原因为 `power-on`；
- 钢琴连接后出现 VID:PID 和 MIDI IN 端点；
- 弹中央 C 后 MIDI 包计数增加。

这一屏截图是第一次必须回传的证据。如果没有枚举，只检查接线和日志，不接灯带扩大变量。

### 3. 台面连接灯带

断电后接 Micro-Fit、XT30 和灯带；不要先贴到钢琴。装 3A 保险，首次以 10% 亮度依次测试 A0、C4、C8。确认方向、颜色、无闪烁、无自行复位，诊断无 `brownout`/`watchdog`。

### 4. 无电纸条试装

剪一条 12mm 宽纸条，在 C4 附近模拟灯带：底边约高于自然白键面 2-3mm、正面朝演奏者，不盖红毡。缓慢按压相邻黑白键到全行程，纸条不得接触键帽。完成后再做 24 小时无痕胶兼容测试。

不确定方向时直接对照 [裸灯带剖面光路图](optical-installation.svg)：灯带竖直贴在钢琴自带黑色立面上，不是朝上平放，也没有琴键侧打印盒。

### 5. 正式贴装和自动验收

灯带断电时贴到黑色固定立面，完成 A0/C4/C8 三点和 88 键校准，再按网页“安装向导”逐项完成证据。最后执行 30 分钟温升、端到端压降、断网/拔线急停和 120fps 延迟测试。

## 暂时不要做

- USB 未枚举前不要接灯带；
- 台面灯带未通过前不要贴琴；
- 12mm 纸条未通过前不要正式粘贴；
- 功能和温升未通过前不必打印控制盒；
- 不得为了“试一下”跳过 3A 保险、公共地或 H7。

这样每一步只增加一个变量，失败时不需要拆整机，也不会产生专用测试废件。

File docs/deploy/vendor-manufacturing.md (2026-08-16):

# NoteFall 88 制作与采购操作手册

> **本机状态（2026-08-09）：已下单、尚未到货。** 先看 [本机部署入口](README.md)、[已购硬件台账](as-purchased.csv)和[到货验收清单](arrival-checklist.md)。本文件第 2 节是另一种通用厂家代工方案，不是要求本机重复购买。
>
> **2026-08-16 实物结论：** 已购 KF301‑3P 的三个相邻脚两两均不导通，属于标准独立极位 PCB 端子。商家所说的“可以连起来”并非电气共点；不得用作悬空主电源汇总。主电源需使用 5 V/GND 各一只、明确内部共点且额定不低于 5 A 的一进六出（或更多位）绝缘分线端子；KF301 仅保留给后续焊接小板。

> 用途：把“需要找厂家制作的东西”一次说清——做什么、找谁、发什么资料、怎么沟通、怎么验收、花多少钱、多久到货。默认路线是找厂家版；**本机实际采购覆盖见第 1 节**，优先按第 1 节执行。
> 依据：仓库内 `../bom.csv`、`../harness.csv`、`../wiring-harness.svg`、`../vendor-order-template.md`、`../assembly.md`、`../hardware.md`、`../../mechanical/exports/*`。
> 结论先行（默认路线）：真正需要“找厂家干活”的只有 **4 项**（灯带焊接代工、线束定制、控制盒 3D 打印、黑色载体裁条），其余都是直接下单买成品。本机实际不找灯带/线束店代工，采购与接线以 1 为准。不需要定制 PCB、不需要全长打印导轨、不需要第二只电源。

---

## 0. 零基础速成：灯带和线束是什么、怎么快速搞懂

> 给零基础的你。结论：**你不需要自己设计电路**。本机实际采购见第 1 节；裸 74AHCT125N 的最终小板仍需可靠焊接，下面这些名词是看懂接线和验收的基础。

### 0.1 灯带是什么（一句话：一条能逐颗控制的小彩灯）

- 灯带 = 一条软板，上面每隔固定距离焊一颗 LED 灯珠，可以整条发光，也能像屏幕一样逐颗控制“哪颗亮、什么颜色”。
- 我们用的规格，**只需要记这 5 个词**：
  1. **APA102C 或 SK9822**——灯珠型号。能独立控制每颗颜色/亮度、带时钟线、176 颗精确同步不乱闪。**别买成 WS2812**（另一种常见型号，单线协议，时序苛刻容易闪）。
  2. **144 灯/米**——每米 144 颗，很密；88 个琴键用 176 颗（每键约 2 颗）。
  3. **黑色 PCB**——底板黑色，贴黑色琴立面不显眼。
  4. **IP30 非防水**——室内用；防水款外面有硅胶套，会挡光、不好贴。
  5. **5V**——工作电压，配 5V/5A 电源。
- 灯带上有 **DIN / CIN**（数据输入 / 时钟输入）和一个箭头：**信号只能从箭头端进**，箭头方向 = 数据流向。所以“箭头从输入端指向远端”是验收要点（卡 A 会再次强调）。
- 灯带可以**按灯珠剪断**（灯珠之间是铜焊盘），我们剪成 176 颗 ≈ 1.222 米，余料当维修备件。
- 灯带干什么：贴在琴键后方黑色立面上，弹哪个键亮哪个键，跟随练习模式（等我弹/实时/跟随我）移动。

### 0.2 线束是什么（一句话：一组按规则接好的“电源线 + 信号线”，两头带插头）

- 线束 = 把多根电线按固定规则捆在一起、两头做好插头的一组线。电脑电源线、汽车线路、充电线都算“线束”。
- 这套系统的线束就是整台设备内部的全部连线（`../harness.csv` 里的 H0–H7），按功能分三类：
  1. **电源线（粗，红/黑）**：把 5V 电源送到灯带两端、ESP32、74AHCT125 模块、USB 供电口。电流大所以线粗（20AWG）。
  2. **信号线（细，绿/蓝）**：把 ESP32 的 DATA / CLOCK 信号送到灯带。只传信号、不承担电流（26AWG）。
  3. **USB 供电线（H5/H7）**：两头是 Micro-USB 公头、只接电源两针（VBUS/GND）的特殊线，给 ESP32 和钢琴 USB 口供电。
- 线的两头是**连接器**（插头/插座），你会见到的就 4 种：
- **DC5521**：电源适配器的圆头插头（像路由器电源那种圆孔），规格为 DC5.5×2.1。
  - **Micro-Fit 3.0 4P**：4 针带锁扣的插头，灯带输入端用，防松脱。
  - **XT30**：2 针大电流插头，灯带远端注电用。
  - **Micro-USB 公头**：H5/H7 供电线的头，插开发板和 OTG Y 线供电口。
- 线束干什么：把电源、ESP32、灯带、钢琴 USB 连成一个系统，保证电流够、压降小、不短路、不接错。**线束不用你做、也不用懂原理**——店家按 `harness.csv` 做好整组给你，你收货验货即可。

### 0.3 必须懂的 vs 可以不懂的

必须懂的（就 5 件事，都是“认东西”不是“学电”）：
1. 灯珠型号是 APA102C / SK9822（不是 WS2812）；
2. 灯带规格：144 灯/米、黑色 PCB、5V、非防水；
3. 数量：裁 176 灯 ≈ 1.222 米；
4. 方向：灯带箭头 = 数据流方向，从输入端指向远端；
5. 工具：万用表“通断档”（两根表笔碰到一起会“哔”），验收时用来检查“通不通、短没短”。

可以不懂的（交给卖家/文档）：
- 为什么 20AWG/26AWG、为什么串 100 Ω、为什么用 74AHCT125 做电平转换、连接器内部怎么锁扣——这些是设计细节，菜谱已写好，你不需要会解释，也不会被问到。

### 0.4 快速上手三步（不用先看书）

1. **看 10 分钟视频**：B 站搜“APA102 灯带 接线”或“SK9822 灯带 教程”，看一遍“接 5V/GND/DATA/CLOCK 四根线 + 按灯珠剪断”就够。
2. **到手先台面试**：不贴琴，接好电源在桌面点亮，网页依次点 A0、C4、C8 三个键，看对应位置的灯亮不亮、颜色对不对、方向反没反（反了在设置里打开“灯带反向”）。这一步能暴露 80% 的问题。
3. **验收只做三件事**：看（焊点有没有热缩管、有没有露铜）、量（万用表通断档：5V-GND 不“哔”、DATA/CLOCK 不互换、每个接头每根线对得上 `harness.csv`）、拉（轻拉线头不脱落）。全程不需要懂电学。

所有具体数字和验收项都在本文档 2.2–2.6 节和 `../harness.csv`、`../vendor-order-template.md`，用的时候对着看，不用背。

---

## 1. 本机实际方案（2026-08-09 复核）

> 本机不按通用 Micro-Fit/XT30 线束再次采购。实际为“灯带自带约 10 cm 裸线 + 商家确认可共点的 KF301 端子 + 74AHCT125N 裸芯片”。除 ESP32-S3 和 OTG Y 线外，本次采购记录合计约 250 元；所有物料尚未到货。

已买/已有：

| 类别 | 已买/已有 |
|---|---|
| 灯带 | SK9822 灯带 1 条，头尾自带约 10cm 裸线 |
| 电源 | 5V/5A 电源适配器、DC015 圆座、3A 保险丝 + 备件 |
| 电气件 | 1000µF 电容 ×2、100Ω 电阻 ×2、KF301‑2P ×10、KF301‑3P ×10（商家确认可共点） |
| 控制 | ESP32-S3-DevKitC-1、OTG Y 线（已有）、74AHCT125N、170 孔面包板、杜邦线 |
| USB 供电 | Micro-USB 公头供电线 ×2（H5/H7） |
| 线材 | 20AWG 红黑硅胶线各 2 米、26AWG 绿蓝信号线各 1 米 |
| 连接 | USB-A 公 → USB-B 公打印机线 |
| 装机 | 3D 打印控制盒、M3×10 塑料螺丝 ×4、无痕固定带 3–5 片、剪刀、万用表 |

接线变更（对照默认线束方案）：

- 不买/不用：`Micro-Fit`、`XT30`、`XT60`、`DC5521 一进三出`、黑色 PET 载体条。
- 电源入口：电源适配器 → DC015 → 3A 保险 → 经过逐孔蜂鸣确认的绝缘共点分线端子（5V/GND 各一只，至少六个可用分支）。
- 灯带两端：用灯带自带约 10 cm 裸线与长线连接，不增加 Micro-Fit/XT30；最终端接方式按 KF301 到货结构确定。
- 灯头预计有 4 根短线、灯尾预计有 2 根短线；颜色定义只是下单记录，必须按灯带焊盘 `5V/GND/DI/CI` 与箭头实物复核后再接。
- 灯尾只做 5V/GND 远端注电，不连接末端 DATA/CLOCK。
- H5：Micro-USB 公头供电线 → ESP32 `USB-to-UART` 口。
- H7：Micro-USB 公头供电线 → OTG Y 线第 3 个 Micro-USB 供电口。
- 74AHCT125N：先用面包板测试；正式装盒前找手机维修店/来料焊接焊成 DIP-14 IC 座小板。
- 贴琴：不买 PET，无痕固定带直接固定灯带；正式贴装前先做 24 小时表面测试。

线材剪裁（本机灯带首尾已经各带约 10 cm 引线，下列是另购整线的裁剪长度）：

- 红/黑 20AWG 各 2 米均裁为：远端注电 `140 cm`、输入端注电 `35 cm`、盒内短接 `10 cm + 10 cm`，剩余约 `5 cm` 备用。接上灯带自带线后，远端总长约 150 cm、输入端约 45 cm；控制盒必须放在灯带四线输入端附近。
- 绿/蓝 26AWG 各 1 米均裁一段 `40 cm` 作为 DATA/CLOCK；接上灯带自带约 10 cm 输入线后总长约 50 cm，剩余约 60 cm 整段备用。
- H5/H7 是已带 Micro-USB 插头的独立供电线，不从上述红黑 20AWG 长线中裁；保险丝座自带引线优先直接进入 DC015 与 5V 公共点。

KF301 端子记录：

| 已购物料 | 数量 | 到货验收 |
|---|---|---:|
| KF301‑2P | 10 | 商家确认可共点；逐孔蜂鸣并记录共点方向 |
| KF301‑3P | 10 | 与 2P 组合后的预定公共孔必须全通，5V/GND 两组必须不通 |
| Micro-Fit / XT30 / XT60 | 0 | 本机不采用 |

实物蜂鸣已经证明这批 KF301 只有机械拼接能力、各极位电气隔离。停止自由搭接；主电源另用绝缘共点分线端子，KF301 改为焊接小板用途。

74AHCT125N 是裸 DIP‑14：面包板只用于 G1 台架，最终件仍需可靠小板；14 脚 VCC 与 7 脚 GND 旁必须有 0.1 µF（100 nF）陶瓷去耦。绝缘、护边、扎带及接触式温度计按到货状态和 G1 门禁准备。详见 `as-purchased.csv` 与 `arrival-checklist.md`。

---

## 2. 默认找厂家方案（参考）

> 以下 2.1–2.10 是原“默认找厂家版”的完整流程；本机实际不按这套下单，只留作参考。

### 2.1 一句话分工

> 本机实际：采用第 1 节已购物料覆盖；下面的卡 A/B 只作为通用默认路线参考。

| 谁 | 干什么 |
|---|---|
| **你（用户）** | 下单、发资料给厂家、收货后按清单验收、按顺序装机 |
| **灯带/线束店（代工）** | 裁灯带、焊首尾注电、做整组线束、焊电容/电阻、逐线检查 |
| **3D 打印店** | 打印控制盒托盘 + 盒盖（黑色 PETG） |
| **板材裁切店** | 裁黑色 PET/PVC 载体条（1226×14×0.8 mm） |
| **你自己不用做的** | 不焊开发板、不做定制 PCB、不设计电路 |

---

### 2.2 速查表：默认找厂家版的 4 项外协 + 成品采购

#### 2.2.1 需要找厂家做的（外协）

| # | 事项 | 找什么店 | 发什么资料 | 参考价（元） |
|---|---|---|---|---|
| A | 灯带裁切 176 灯 + 首尾注电 + 焊电容/电阻 + 输入端 Micro-Fit | 灯带卖家（支持代焊）/ 线束定制店 / 手机维修店 | 代工消息模板 + harness.csv + wiring-harness.svg | 灯带 120–260，代工费一般含或另收 30–80 |
| B | 整组线束：DC5521 一进三出、H5/H7 两根 Micro-USB 供电线、Micro-Fit 4P、XT30 | 线束定制店 / 端子线加工店（可与 A 同一家） | 同上三个文件 | 40–110 |
| C | 控制盒 3D 打印：托盘 + 盒盖（黑色 PETG，各 1 件） | 淘宝 3D 打印服务店 / 嘉立创 3D / 本地打印店 | controller_tray.stl + controller_lid.stl（可选 .step）+ 渲染图 | 15–45 |
| D | 黑色 PET/PVC 载体条裁切 1226×14×0.8 mm | 板材裁切店（PET/PVC 硬片） | 尺寸 + 材质要求（可附 assembly.md 说明） | 10–30 |

#### 2.2.2 直接买成品（不用厂家做）

| 物料 | 规格 | 搜索词 | 参考价（元） |
|---|---|---|---|
| ESP32-S3-DevKitC-1 N8R8 | 乐鑫官方 | `ESP32-S3-DevKitC-1 N8R8 乐鑫` | 已有 |
| 74AHCT125 模块 | 3.3V→5V 四路电平转换成品模块 | `74AHCT125 四路 电平转换 模块` | 8–25 |
| 5V/5A 电源适配器 | DC5521（5.5×2.1）、带 3C 或同等认证 | `5V5A 3C 电源适配器 DC5.5 2.1` | 35–80 |
| 3A 保险丝座 + 2 只备件 | 5×20 玻璃管，3A 慢断/延时型，带线座 | `3A 5x20 玻璃管保险丝 带线座` | 5–15 |
| 1000 µF/10 V 低 ESR 电容 ×2 | 已焊引线并绝缘 | `1000UF 10V 低ESR 电解电容 引线` | 4–12（若 A 店已焊可省） |
| 100 Ω/0.25 W 电阻 ×2 | 已焊引线并绝缘 | `100欧姆 1/4W 电阻 引线` | 1–3（若 A 店已焊可省） |
| Micro-USB OTG Y 线 | 公转 USB-A 母 + 第三供电口 | `Micro USB OTG 一分二 USB母 独立供电` | 已有或 5–20 |
| USB-A 公 → USB-B 公打印机线 | 1–2 m | `打印机数据线 USB A公 B公` | 10–25 |
| 热缩管 + U 型护边 | 多规格 | `热缩管 U型护边条 1mm` | 8–20 |
| 尼龙扎带 2.5 mm | 可重复或普通 | `尼龙扎带 2.5mm` | 5–10 |
| M3×10 塑料自攻螺钉 ×4 | 打印盒盖用 | `M3x10 塑料 自攻螺丝` | 3–8（选 C 才需要） |
| 无痕固定条（拉伸移除式）×3–5 | 薄型带外露拉伸尾片 | `无痕固定条 拉伸移除` | 10–30 |
| 数字万用表 | 通断蜂鸣 + 直流电压 | `数字万用表 自动量程` | 已有或 30–80 |
| 接触式温度计 | 0–100 ℃ | `接触式 温度计 探头` | 20–50（可借用） |

> 红黑硅胶线（20AWG）、绿蓝信号线（26AWG）通常已包含在 A/B 代工里，自己不用单买；如需备用再按 `bom.csv` 加购。

> 本机实际：不买 `Micro-Fit`、`XT30`、`XT60`、`DC5521 一进三出`，也不走卡 A/B 代工；实际清单与接线见 1。

---

### 2.3 先准备“制造资料包”（发给厂家的东西）

所有给厂家的文件都已存在仓库里，不用自己画图。推荐直接从 GitHub Releases 下载 `notefall88-manufacturing-v0.7.2-rc.1.zip`（发布页说明里写着“找淘宝代做线束或打印控制盒：下载 manufacturing 包”）；没有网络时，从仓库直接拷以下文件：

| 发给谁 | 文件 | 作用 |
|---|---|---|
| 灯带/线束店 | `../vendor-order-template.md` | 代工消息模板（10 条硬性要求），直接复制发过去 |
| 灯带/线束店 | `../harness.csv` | 逐线制造表：每一根线的起点/终点/引脚/颜色/线径/长度/端接/验收 |
| 灯带/线束店 | `../wiring-harness.svg` | 接线图，配合 CSV 看 |
| 3D 打印店 | `../../mechanical/exports/controller_tray.stl` + `controller_lid.stl` | 托盘 + 盒盖模型 |
| 3D 打印店 | `../../mechanical/exports/controller_tray.step` + `controller_lid.step` | 可选，给能收 STEP 的店 |
| 3D 打印店 | `../../mechanical/renders/controller_case.png` | 成品渲染图，让店家确认外观 |
| 板材裁切店 | 尺寸数字（1226×14×0.8 mm）即可，可附 `../assembly.md` | 载体条 |

> 给厂家前建议把 `bom.csv` 里对应的那一行也发过去（有“淘宝搜索词”和“备注”），减少沟通歧义。

---

### 2.4 外协操作卡（默认找厂家版，逐项：干什么 / 找谁 / 怎么干 / 验收）

> 默认路线为找灯带/线束店代工。本机实际采用第 1 节采购覆盖，卡 A/B 只留作参考。

#### 卡 A：灯带裁切 + 焊接代工（最关键，唯一强烈建议交给卖家的部分）

**干什么**：买一条 2 m 连续灯带，让卖家一次裁好 176 灯（约 1.222 m），完成首尾注电、两只电容、两只 100 Ω 电阻、输入端 Micro-Fit 4P 与远端 XT30 的焊接，并逐线检查后再发货。

**找谁**：淘宝/1688 卖 APA102C/SK9822 灯带的店（多数支持代焊）；或“线束定制”店；应急可找本地手机维修店。
- 搜索词：`5V 144灯 APA102 SK9822 黑板 IP30`、`APA102C 灯带 黑色 PCB 144灯`、`SK9822 灯带 黑色 非防水`

**怎么干（直接把 `vendor-order-template.md` 全文发过去，核心 10 条）**：
1. 灯带 APA102C 或 SK9822，5V、144 灯/m、黑色 PCB、非防水，从连续 2 m 裁 176 灯；箭头从 DIN/CIN 指向远端。
2. 灯带输入端：Micro-Fit 3.0 兼容 4P，Pin1 红 5V、Pin2 黑 GND、Pin3 绿 DATA、Pin4 蓝 CLOCK；**供电侧必须用凹端子**。
3. 灯带远端：只用 XT30 并联注入 5V/GND，**不接末端 DATA/CLOCK**。
4. 首尾各焊一只 1000 µF/10 V 电容，带条纹负极接 GND；焊点热缩绝缘 + 扎带应力释放。
5. DATA、CLOCK 各串一只 100 Ω 电阻，靠近 74AHCT125 输出端；DATA/CLOCK 不得互换。
6. H5：保险后 5V/GND → ESP32 的 `USB-to-UART` 口（Micro-USB 公头），只接 VBUS/GND。
7. H7：保险后 5V/GND → OTG Y 线第三供电口（Micro-USB 公头），只接 VBUS/GND。**H5、H7 是两根独立支路，不能合并**。
8. 5V 总入口后 100 mm 内串 3 A 保险丝；红黑主电源线 20AWG，H5/H7/模块供电不细于 24AWG，信号线 26AWG。
9. 交货前逐线蜂鸣：5V-GND 不短路、DATA/CLOCK 不互换、连接器极性正确，并**提供万用表检查照片**。
10. 所有焊点和裸铜双层热缩或等效绝缘；线缆轻拉 10 N 不脱落。

**一句话红线**：告诉店家“用途是数码钢琴灯带，不接市电裸线”；如附件与口头描述不一致，**先暂停并逐项提问，不允许自行改针脚、线色、保险丝或连接器方向**。

**验收（收货时）**：对照 `harness.csv` 用万用表逐线蜂鸣——5V-GND 不导通、DATA/CLOCK 不互通、Micro-Fit 1/2/3/4 依次为红/黑/绿/蓝、XT30 只有红黑两线、供电侧无裸露带电公针。不接电先检查，不通过就找店家返工。

**参考**：灯带 120–260 元；代工费通常含在灯带价里或另收 30–80 元；3–7 天到货。

---

#### 卡 B：线束定制（可与卡 A 同一家店，也可单独线束店）

**干什么**：做 4 样东西——
- DC5521 母座“一进三出”配电线（5V 总入口分三路：灯带左端、灯带右端、控制盒支路），20AWG、带绝缘和应力释放；
- H5、H7 两根 Micro-USB 公头供电线（只接 VBUS/GND）；
- Micro-Fit 3.0 兼容 4P 公母预压锁扣线（灯带输入）；
- XT30 公母预焊 20AWG 线（灯带远端注电）。

**找谁**：淘宝“线束定制 / 端子线加工”店。搜索词：`线束定制 20AWG`、`DC5521 母 一分三 20AWG 定制线`、`Micro-USB 供电线 定制`、`Micro-Fit 3.0 4P 公母 预压线`、`XT30 公母 带线 20AWG`。

**怎么干**：发 `harness.csv` + `wiring-harness.svg` + `vendor-order-template.md`，要求按表逐线制作：线色、线径、长度、引脚号、端接全部按表，**不得现场猜线**。特别强调 H5/H7 只接 VBUS 和 GND（不接 D+/D-/ID），H5 与 H7 必须独立存在。

**验收**：万用表逐线对照 harness.csv；H5、H7 空载电压应为 4.75–5.25 V 且极性正确（上电测，最好在保险后测）。

**参考**：DC5521 一分三 15–35；H5/H7 两根 10–25；Micro-Fit 一对 15–35；XT30 一对 8–15；合计约 40–110 元；3–7 天。

---

#### 卡 C：控制盒 3D 打印（可选，只要好看才做）—— 3D 打印执行单

**一句话结论**：控制盒只是“好看 + 收纳”的**可选美观件**，不是功能必需——不打印也能用带通风孔的成品塑料盒（见“备选”）。要打就一次打 2 件（托盘 + 盒盖），一起下单最省事。

**干什么**：打印 1 个托盘 + 1 个盒盖，黑色 PETG，用来收纳 ESP32 和 74AHCT125 模块。托盘外廓 112×76×25 mm、盒盖 112.4×76.4×5 mm；模型实体积约 50 cm³（托盘约 34 cm³ + 盒盖约 16 cm³），按 PETG 密度 1.27 g/cm³ 折算约 63 g；实际 20% 填充会略轻，约 50–65 g，以切片软件为准。

**找谁**（三选一）：
- 淘宝 3D 打印服务店：搜 `3D打印 PETG 黑色`、`3D打印服务 手板`，把下面的“询价消息”直接复制发旺旺；
- 嘉立创 3D（JLC3DP）：官网/小程序直接上传两个 STL，自动报价，适合不想聊天；
- 本地打印店：把两个 STL 拷 U 盘带去，当面说清参数。

**要发的文件**（给 3D 打印店的，共 4 个文件 + 1 张图）：
- `../../mechanical/exports/controller_tray.stl` —— 托盘模型（**必发**，嘉立创直接传这个）
- `../../mechanical/exports/controller_lid.stl` —— 盒盖模型（**必发**）
- `../../mechanical/exports/controller_tray.step` + `controller_lid.step` —— 原始 CAD 档，厂家要改尺寸时才给
- `../../mechanical/renders/controller_case.png` —— 成品渲染图，给店家确认外观用

**怎么干（把下面参数原样复制给店家）**：

> 材料：黑色 PETG，FDM 打印。喷嘴 0.4 mm；层高 0.20 mm；4 周壁厚；顶/底各 5 层；填充 20%。
> 数量：`controller_tray.stl` ×1、`controller_lid.stl` ×1，共两件。
> 关键尺寸（模型里已做好，**不要改**）：
> - 托盘外廓 112 × 76 × 25 mm，四角 M3 螺丝柱（直径 7 mm、高 23 mm、导孔 2.5 mm），盒盖四角对应 3.4 mm 通孔；
> - 一侧 36 × 12 mm 出线口（USB），对侧 28 × 12 mm 出线口（线束）；
> - 托盘底部 8 个扎带槽（8 × 2.4 mm）+ 4 个线束固定槽（10 × 2.8 mm），全部要通孔；
> - 盒盖带 5 条通风槽（各 8 mm 宽、长 32 mm），底部有 3 mm 定位裙边，裙边与托盘内腔配合间隙 0.4 mm，要能扣入。
> 请报：打印价 + 运费 + 交期。有参数看不懂先问我，**不要自行缩放模型或改孔位**。

**下单前让店家确认（发货前回复这几点）**：
1. 是不是黑色 PETG、层高 0.2 mm、填充 20%；
2. 两个出线口（36 mm 和 28 mm）尺寸准确、没被支撑料堵住；
3. 四角 M3 螺丝柱与盒盖 3.4 mm 通孔位置能对上；
4. 盒盖裙边能扣入托盘、不松不紧（间隙 0.4 mm）；
5. 托盘底部 8 + 4 个槽全部通孔、没堵。

**验收（收货时 2 分钟检查）**：
- 盒盖能扣上、晃动不松垮，四角螺丝孔能对齐；
- 两个出线口边缘无毛刺，能穿过 Micro-USB 头和线束插头；
- 层间无开裂、底面平整；
- 重量约 50–65 g（参考值，看打印店填充设置）；
- 先空拧一次 M3 螺丝（攻丝）确认能拧进，再装电子件，不要一次拧死。

**到货后怎么装（等台面测试通过后再装盒）**：
- 按 `../assembly.md` 第 6 节：ESP32、74AHCT125 用尼龙扎带穿托盘槽固定，模块间至少留 5 mm；
- USB 出线走 36 mm 开口、线束走 28 mm 开口，所有开口加柔性护边；
- 线先穿专用扎带槽做应力释放再进开口，避免拽到 USB 口和焊盘；
- 确认能正常开机、无过热后，再盖盒盖、四角上 M3×10 塑料自攻螺钉。

**备选（不想打印就这么干）**：买一个带通风孔的成品塑料盒（15–40 元）把模块固定进去，效果等同、省事，省掉打印沟通。

**参考**：打印 15–45 元 + 运费；2–5 天。

---

#### 卡 D：黑色 PET/PVC 载体条裁切（可选）

**一句话解释（先看这个）**：灯带是软的、自带背胶。直接贴琴怕两件事——时间久了背胶留印/撕不下来，或者想重新定位时伤到琴面。PET 条就是一根**黑色硬塑料“托盘”**：先把灯带贴在它上面，再用无痕固定条把这根条贴到琴上。这样真正接触琴的全是“无痕胶”，灯带本体不碰琴。它只是平直硬底，**不包裹灯带、不挡灯珠**（发光面仍朝演奏者）。

**干什么**：裁 1 条黑色 PET（或 PVC）硬片，`1226 mm 长 × 14 mm 宽 × 0.8 mm 厚`，正好托住裁好的 176 灯灯带（约 1.222 m）。
**为什么是 14 mm 宽**：灯带 PCB 标准宽 12 mm（`../../config/system.json` 的 `led.pcb_width_mm`），14 = 12 + 每边 1 mm 余量——背胶贴正不溢出、边缘有富余。实际买到的 144 灯/米灯带常见 10–12 mm 宽，14 mm 载体条两种都托得住。

**找谁**：淘宝板材裁切店。搜索词：`黑色 PET 硬片 0.8mm 裁条`、`PVC 硬片 裁切 定制`。

**怎么干（把下面这句直接复制给店家）**：

> 你好，我要裁 1 条黑色 PET 硬片（PVC 也行）：长 1226 mm、宽 14 mm、厚 0.8 mm，黑色不透光，要一整条。要求裁边平整、无毛刺、边缘不刮手。请报：材料价 + 裁切费 + 运费 + 交期。

**下单前确认**：黑色不透光；厚 0.8 mm；长 1226 mm **一整条**（不要截成几段拼）；边缘平整。

**验收**：长度约 1226 mm、宽 14 mm、厚 0.8 mm、黑色不透光、边缘不刮手。

**参考**：10–30 元；2–4 天。
**价格提醒**：文档参考 10–30 元；个别店报 40+（长条/起订/运费），可换店再问或砍价（PET、PVC 都行，哪家便宜用哪家）。超过 40 元就不值——此件是**可选件**，不买也能用灯带自带背胶直接贴琴（先在最右端不起眼处做 24 小时材料相容性测试，见 `../assembly.md` 第 3 节）。

---

### 2.5 通用流程：找店 → 问价 → 下单 → 验收

#### 2.5.1 找店
- 首选 **淘宝**（项目文档默认渠道，个人单量小、客服易沟通）；**1688** 适合一次要多家或想省一点；**嘉立创 3D** 只用于控制盒打印（上传 STL 自动报价）。
- 灯带/线束：在同一家店能同时搞定卡 A + 卡 B 最好，省运费、少一次沟通；不行就分开。

#### 2.5.2 问价（可直接复制发给店家）

> 你好，我想做一套数码钢琴的 5V 低压灯带和线束（不接市电裸线）。请看附件三个文件：`vendor-order-template.md`（要求）、`harness.csv`（逐线表）、`wiring-harness.svg`（接线图）。
> 需要你：1）2m APA102C/SK9822 黑色 144灯 灯带裁 176 灯并焊好首尾注电、电容、电阻；2）按 harness.csv 做整组线束（含 DC5521 一分三、H5/H7 两根 Micro-USB 供电线、Micro-Fit 4P、XT30）。
> 请报：灯带价 + 代工费 + 线束价 + 运费 + 交期。如果附件里有什么看不懂或做不到，先问我，不要自行改针脚、线色、保险丝或连接器方向。谢谢！

#### 2.5.3 下单确认（发货前让店家回复这几点）
- 灯带是不是 144 灯/m、黑色 PCB、非防水；
- 是不是裁 176 灯、箭头 DIN→远端；
- 输入端 Micro-Fit 供电侧是凹端子；
- H5、H7 两根独立、只接 VBUS/GND；
- 3A 保险丝在 5V 入口 100 mm 内；
- 发货前逐线蜂鸣并附万用表照片。

#### 2.5.4 收货验收（先不接电）
按 `../testing.md` 的“A. 断电检查”做一遍：
1. 万用表通断档：灯带 5V-GND 不蜂鸣；ESP32 GND、74AHCT125 GND、灯带 GND 互通；DATA 与 CLOCK 不互通。
2. 首尾电容负条纹接 GND；3A 保险串在 5V 正极且距入口 ≤100 mm；灯带箭头从输入端指向末端。
3. 按 harness.csv 逐线蜂鸣：Micro-Fit 1/2/3/4 = 红 +5V / 黑 GND / 绿 DATA / 蓝 CLOCK；XT30 只含红 +5V、黑 GND；供电侧无裸露带电公针。
4. 不接任何模块，在 DC5521 入口上电（带 3A 保险），所有 +5V 节点应为 4.75–5.25 V 且极性正确，然后断电。

全部通过再进入装配（见 2.7 节）。

---

### 2.6 预算与周期汇总

| 项 | 最低（元） | 最高（元） | 交期 |
|---|---:|---:|---|
| 灯带 + 代工（卡 A） | 150 | 340 | 3–7 天 |
| 线束（卡 B） | 40 | 110 | 3–7 天（可与 A 同店） |
| 控制盒打印（卡 C，可选） | 15 | 45 | 2–5 天 |
| 载体条（卡 D，可选） | 10 | 30 | 2–4 天 |
| 其余成品（2.2.2 节，不含已有项） | 约 120 | 约 330 | 与上并行 2–5 天 |
| **合计** | **约 350** | **约 850** | **全部到齐约 1 周** |

> 已剔除了你已有的 ESP32 开发板和 OTG Y 线；万用表若没有需另算 30–80 元。A/B 可同店合并下单，C/D 可同时下单，整体一周内能凑齐。

---

### 2.7 到货后的装配顺序（不要乱序）

1. **先烧录 ESP32**（`../flashing.md` 或发布页 `notefall88-factory-*.zip`）：只连开发板 UART 口，钢琴和灯带断开；确认手机能看到 `NoteFall-88` 热点、网页能打开。
2. **台面验证 USB**（不接灯带）：按 `../decisions/001-native-usb-host-and-vbus.md` 接 H5/H7、Y 线和打印机线；诊断页确认 PSRAM ≈8 MiB、钢琴枚举出 VID:PID 和 MIDI IN、弹中央 C 包计数增加。
3. **台面接灯带测试**：断电接 Micro-Fit、XT30、灯带；装 3A 保险；首次 10% 亮度依次测 A0、C4、C8；确认方向、颜色、无闪烁、无 `brownout`/`watchdog`。
4. **纸条试装**：12 mm 宽纸条在 C4 附近模拟灯带，底边距键面 2–3 mm、正面朝演奏者、不盖红毡；全按相邻黑白键不得接触。先做 24 小时无痕胶兼容测试。
5. **正式贴装 + 安装向导 + 完整验收**：灯带断电时贴到琴键后方黑色固定立面（发光面朝演奏者、底边 2–3 mm），完成三点/88 键校准，按网页“安装向导”收集证据，再执行 `../testing.md` 的温升、压降、断网/拔线急停和 120 fps 延迟测试。

顺序每步只增加一个变量：USB 未枚举前不接灯带；台面灯带未通过前不贴琴；纸条未通过前不正式粘贴；功能和温升未通过前不必装控制盒。

---

### 2.8 明确不找厂家/不买的东西（省下这些钱）

- **定制 PCB**：不需要，开发板 + 成品模块直接插接。
- **全长 3D 打印灯带导轨 / 扩散盖 / 挡边**：不需要，灯带竖直裸装，琴键侧打印件 0 件。
- **第二只 5V 电源**：禁止，整机只用一只 5V/5A 认证电源。
- **MAX3421E（SPI USB Host 模块）**：不需要，ESP32-S3 原生 USB Host。
- **树莓派 / 专用电脑**：不需要。
- **多条测试灯带 / “一八度测试废料”**：不需要，只买一条 2 m，裁 176 灯，余料当维修备件。

---

### 2.9 安全红线（违反会烧东西，务必转告店家和你自己）

1. 整机只接一只 5V/5A 带 3C 认证的成品电源；**禁止裸板电源、禁止两只适配器同时接**（会互相回灌）。
2. **3A 保险丝必须串在 5V 正极、距电源入口 ≤100 mm**，保护灯带、控制器和 USB Host 全部支路；坏了只能换同规格 3A，**不可换大**。
3. 供电侧连接器一律用**凹端子**（不露带电公针）；不用松动的杜邦线做永久大电流连接。
4. 灯带箭头必须从 `DIN/CIN` 指向远端；首尾两端**只并联供电**，不把末端数据接回首端。
5. **H5、H7 是两根独立支路，不能合并**；H5 插开发板 `USB-to-UART` 口、H7 插 OTG Y 线第三口，不能插反（Y 线不能插 UART 口）。
6. 所有焊点热缩绝缘；线缆轻拉 10 N 不脱落；不焊开发板、不现场猜线、不让店家改规格。
7. 出现问题（过热、闪烁、随机重启、USB 反复掉线、5V-GND 短路）**立即断电**，不靠调高亮度或换大保险丝掩盖。

---

### 2.10 工程里的图纸与说明文件清单（每个文件给谁看）

> 这些文件都在仓库里，不用自己画。发布页的 `notefall88-manufacturing-<版本>.zip` 已把与制造相关的全部打包，可直接解压使用。

#### 2.10.1 电气接线（≈原理图，灯带/线束店看）

| 文件 | 是什么 | 给谁看 / 什么时候用 |
|---|---|---|
| `../wiring-harness.svg` | 整机接线图（图形版原理图） | 灯带/线束店：下单必发 |
| `../harness.csv` | 逐线制造表 H0–H7（起点/终点/引脚/颜色/线径/长度/端接/验收） | 灯带/线束店：下单 + 收货验收必用 |
| `../vendor-order-template.md` | 发给厂家的 10 条硬性要求 | 灯带/线束店：下单时复制发过去 |
| `../hardware.md` | 接线文字说明 + USB 三条连接 + 灯带接线图 | 自己装机时对照 |
| `../decisions/001-native-usb-host-and-vbus.md` | H5/H7 双供电原理与禁止接法 | 自己理解“为什么这么接”；H5/H7 有疑问时看 |

#### 2.10.2 机械图纸/模型（3D 打印店看）

| 文件 | 是什么 | 给谁看 / 什么时候用 |
|---|---|---|
| `../../mechanical/exports/controller_tray.stl` + `.step` | 控制盒托盘模型 | 3D 打印店：下单必发 |
| `../../mechanical/exports/controller_lid.stl` + `.step` | 控制盒盒盖模型 | 3D 打印店：下单必发 |
| `../../mechanical/renders/controller_case.png` | 控制盒成品渲染图 | 3D 打印店：确认外观 |
| `../../mechanical/renders/vertical_strip_mount.png` | 灯带安装方式渲染图 | 自己贴装前参考 |
| `../optical-installation.svg` | 裸灯带剖面光路图（灯珠朝演奏者、距键面 2–3 mm） | 自己贴装时对照 |
| 私人实琴照片（不入仓库） | 只用于确认安装面 | 不发厂家、不上传 GitHub；公开资料只保留去敏测量结论 |

#### 2.10.3 参数表（数字依据，一般不用发给厂家）

| 文件 | 是什么 | 什么时候用 |
|---|---|---|
| `../../config/system.json` | 全部参数：引脚 11/12、176 灯、144 灯/米、5V、亮度上限 4、机械尺寸、供电 | 需要核对规格时 |
| `../../generated/power_budget.json` | 供电预算：满亮 6.8W/1.36A、设计电流 2.0A、压降 1.45% | 电源/线径有疑问时 |
| `../../firmware/include/layout_generated.h` | 固件硬编码参数与 88 键灯位映射 | 一般不用看，调试用 |
| `../bom.csv` | 采购清单 + 淘宝搜索词 + 备注 | 自己下单时逐项核对 |

#### 2.10.4 说明书/验收（自己用）

| 文件 | 是什么 | 什么时候用 |
|---|---|---|
| `../assembly.md` | 装配步骤（下单复核、灯带准备、让卖家代焊、无损安装、控制盒） | 装机全程 |
| `../first-build.md` | 最短执行路径（采购 → 代工 → 五步装机） | 第一次装机 |
| `../testing.md` | 断电检查 + 完整验收清单（含温升/压降/120 fps 延迟） | 装机后验收 |
| `../commissioning.md` | 网页安装向导的证据模型 | 装机后走安装向导 |
| `../measurements.md` | 现场复核 M1–M3（12 mm 纸条试装） | 正式贴装前 |
| `../flashing.md` | 烧录固件/网页 | 第一步烧录时 |

> **一句话记忆**：灯带/线束店只发 3 个文件（`wiring-harness.svg` + `harness.csv` + `vendor-order-template.md`）；3D 打印店发 4 个（`tray.stl` + `lid.stl` + 对应 `.step` + 渲染图）；板材店报尺寸即可；其余都是你自己装机验收时看。

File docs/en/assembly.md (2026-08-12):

# First build and non-destructive installation

## Before permanent attachment

Do not first glue the LED strip to the piano and hope software can repair a bad placement. The correct order is:

1. Bench-test the controller and all 176 LEDs at low brightness.
2. Temporarily place the strip on the piano with low-tack tape.
3. Align and calibrate it while it is still movable.
4. Verify full key travel and cable strain relief.
5. Make the final removable attachment, then repeat verification.

## Position and orientation

- The strip PCB is vertical (roughly 90 degrees to the key surface).
- LED faces point toward the player; their lower wide-angle light reaches the corresponding keys.
- Keep its lower edge about 2–3 mm above the natural white-key surface.
- Do not cover the red felt or let any part touch a moving black or white key.
- Do not use a full-length printed housing, diffuser, or black baffle in front of the LEDs. A thin black PET/PVC carrier is optional only to keep the strip straight and removable.

## Three-point placement anchors

For the measured purchased strip, count LEDs from the **physical left** (the two-wire end):

| Key | Target LED |
| --- | --- |
| A0, far left | 3rd LED |
| C4, middle C | 80th LED |
| C8, far right | 174th LED |

You do not need to count all LEDs by eye: the calibration UI has test buttons that illuminate these three anchors. The strip is centred across the 88-key span; a small PCB overhang at each end is expected. If all three anchors are displaced in the same direction, move the strip physically. Use a software global offset only for the remaining sub-pixel/one-pixel error.

The splice boundaries are near C2 and C#5. Check these areas especially carefully, but do not try to mechanically remove the gaps.

## Final attachment

First test the chosen removable mounting strip for 24 hours on an inconspicuous, non-key surface. Prefer a stretch-release removable mounting strip holding the optional carrier, rather than aggressive double-sided foam, hot glue, screws, or adhesive directly on the piano finish. If removal causes discoloration, stickiness, or unusual resistance, stop rather than prying.

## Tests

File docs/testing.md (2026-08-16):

# 上电、校准与验收

## A. 断电检查

1. 钢琴、ESP32 和 5 V 灯带电源全部拔掉。
2. 万用表通断档确认：灯带 `5V-GND` 不蜂鸣；ESP32 GND、74AHCT125 GND、灯带 GND 互通；DATA 与 CLOCK 不互通。
3. 确认首尾两个电解电容负条纹接 GND，3 A 保险丝串在 5 V 正极且距入口不超过 100 mm，灯带箭头从输入端指向末端。
4. 按 `docs/harness.csv` 逐线蜂鸣：Micro-Fit 1/2/3/4 必须依次为红 +5V、黑 GND、绿 DATA、蓝 CLOCK；XT30 只含红 +5V 和黑 GND；供电侧均无裸露带电公针。
5. 不接任何模块，在 DC5521 输入端用实验限流源或带 3 A 保险丝的成品电源上电，所有 +5V 节点必须为 `4.75–5.25 V` 且极性正确，然后断电。
6. 首次上电前不连接钢琴 USB。

## B. 分级上电

1. 首次刷机可只给 ESP32 的 UART 口供电，串口应出现启动日志，手机能看到 `NoteFall-88` 热点；完成后拔掉 UART 线。
2. 手机连接该热点（首次密码 `notefall88`），打开 `http://192.168.4.1`；状态应为“ESP 已连接、钢琴未连接”。立即修改公开默认密码，确认安装向导“控制密码”自动变为通过。
3. 断电，接入 74AHCT125、灯带和 H5→USB-to-UART 供电线，原生 USB/OTG 口暂不接钢琴，再接整机唯一的 5 V/5 A 电源。先以 10% 亮度点亮，网页依次点 A0、C4、C8；每次只应亮一处黄色灯。
4. 如果方向相反，在设置中打开“灯带反向”；若三点整体平移，用像素偏移调整。设置保存在 ESP32，重启后仍有效。
5. 应用“本机实测建议”后打开逐键微调，并保持“按琴键时自动选中”开启。从 A0 到 C8 弹半音阶：位置正确的键直接略过；只有偏位键才点“灯向低音侧一格”或“灯向高音侧一格”。每次修正立即写入 ESP32 NVS 并保持测试灯，不需要逐键填写 88 个数字。
6. 最后连接 PX-S7000。钢琴的方形 `USB TO HOST` → 打印机线 → OTG Y 线 USB-A 母口；Y 线 Micro-USB 公头 → 开发板 `USB/OTG` 口。H5 始终插在开发板 `UART/USB-to-UART` 口给板子供电；H7 插入 Y 线第 3 个 Micro-USB 口给钢琴 USB 设备侧提供 VBUS。H5、H7 必须来自同一保险后的 5V 电源，不能用两只互不相关的适配器。

## C. 功能验收

| 测试 | 方法 | 通过标准 |
|---|---|---|
| USB 枚举 | 开关钢琴 5 次 | 每次网页在 3 s 内显示“钢琴 USB 已连接”，无重启 |
| 全键映射 | 从 A0 到 C8 半音阶弹 88 键 | 每键横向位置唯一；最大视觉偏差不超过半个 LED 间距 |
| 和弦 | 同时按 10 个键，重复 20 次 | 无漏键、无卡灯；松键后状态清除 |
| 等待练习 | 导入包含和弦的 MIDI；先反复逐音点按并松开，观察统计，再同时按住目标和弦；最后加入一个持续按住的错误键 | 逐音点按期间命中数不增加；已松开的目标音不累计；目标和弦同时按住后整组只记分一次；错误键仍按住时不推进，松开错误键且正确和弦仍保持时立即提交并进入下一组 |
| 跟随伴奏 | 选择“跟随我”和右手，故意以 50%、100%、约 140% 的个人速度逐组弹奏 | 左手由 PX-S7000 音源播放；下一目标从实际命中时刻按谱面间隔推进，不突然追赶 |
| 跟随循环 | A–B 内包含左右手交替、长音和重复同音，连续 5 轮 | 跨 B 后回到 A；同音重触发无意外截断，循环间无挂音 |
| 乐谱示范 | 分别选左手/右手/双手，在 50%/100%/150% 和 A–B 循环中从曲首与曲中开始；样例含重复同音、超过 60 s 长音、CC64 半踏与换踏 | PX-S7000 仅演奏所选声部，谱面/瀑布/目标灯同步；中途开始恢复踏板状态，重复音先断后启，长音不在 60 s 被提前断开；无 OUT 时为静音预览且不计分 |
| 录音直接回放 | 录制两个 MIDI 通道、重复同音、CC64/66/67 和无关 CC7，以 50%/100%/150% 回放，中途改速并手动停止 | 通道/力度/演奏踏板保留，CC7 不回写；改速时间线连续；停止、断连、锁屏、失去控制权均立即释放踏板和全音，回放事件不进入判分或新录音 |
| 手机后台/锁屏 | 分别在实时播放、预备拍、Follow 两组音之间和录音时锁屏或切换 App，再返回页面 | 目标灯熄灭、伴奏急停且无挂音；乐谱停在原位置，后台时间不计漏键，不自动恢复发声；录音停止并保留可下载前缀 |
| MIDI OUT 安全 | 伴奏长音期间关闭网页、拔手机 Wi-Fi、按“全部熄灭”各一次 | 每次钢琴伴奏在 1 s 内停止，无持续挂音；重新连接后可继续练习 |
| 多页面互斥 | 手机和平板同时打开网页并先后启动跟随模式 | 第一台持有伴奏输出，第二台明确显示“被其他页面占用”且不重复发声；第一台关闭后第二台可接管 |
| 协议错配/畸形消息 | 用测试客户端依次发送 `hello.v=5`、未握手 `target/config`、无效 JSON 和超过 8192 字节消息 | 灯光、校准、Wi-Fi 和 MIDI OUT 均不改变；诊断“拒绝的网页消息”逐项增加；正常 v6 页面继续工作 |
| 家庭 Wi-Fi 控制认证 | 从 STA 地址打开页面，不输入密码尝试测试灯、校准和 MIDI OUT；再分别输入错误及正确管理密码 | 未授权时只能看基础诊断，收不到演奏/校准且控制无变化；错误计数增加；密码不写入客户端存储，正确密码换取持久随机控制令牌；刷新和普通 ESP 重启后可恢复，修改管理密码后旧令牌立即失效 |
| WebSocket 生命周期 | 建连、握手、恢复当前目标、接收全部事件类型、断线和再次连接；发送 49 个伴奏事件 | 先发 v5 hello，再恢复目标并启动心跳；无效入站消息只增加浏览器拒绝计数；重连采用 1–10 秒退避；伴奏拆成 48+1 两批且字节/延迟在发送前限幅 |
| 真浏览器响应式与乐谱导入 | `cd web` 后安装 Chromium/WebKit，分别以默认环境和 `NOTEFALL_BROWSER=webkit` 运行 `npm run smoke:browser` | 两个引擎下 390×844、1280×900、1600×1068 与 3200×2136 均无横向溢出；3:2 单谱面至少使用容器宽度 90%，Studio 分屏给瀑布流至少 280 px；手机练习抽屉不越界且关闭按钮可见；经真实文件选择器导入 `parser-etude.musicxml` 后显示 4 音符、00:04 和非空 OSMD SVG；截图、快照和控制台记录写入 `output/playwright/smoke-*` |
| Studio 离线高级导谱 | 设置 `NOTEFALL_EDITION=studio` 运行 Chromium smoke，分别导入仓库 MSCX 探针和自动生成的原生 MIDI；断开公网后重复，再检查资源时间线与 IndexedDB | MSCX 在本地 Worker 转为 3 音符 MusicXML 并显示 OSMD；转换模块 URL 只来自当前本地 origin，不能出现 CDN；MIDI 仍以原始 96 B 事件流作为判分/时序真值，同时生成并持久化非空 MusicXML 五线谱伴侣，二次打开不重新转换；Studio PWA、Android/iOS 资源内同时包含四个锁定 webmscore 文件、GPL-3.0 正文和第三方声明 |
| 全屏演奏 | 在 Studio/浏览器依次进入单谱面、单瀑布流、分屏并点击画面右上角“全屏演奏”；再启用“播放时自动进入全屏”开始一次练习；浏览器拒绝 Fullscreen API 时重复一次 | 入口不占顶部工具条；顶部控制区全部隐藏、可视化覆盖安全区内的整个可用视口、右上角退出按钮可见；自动偏好重启后保留；分屏图例位于瀑布流而非谱面；Android 同时隐藏状态栏/导航栏，边缘滑动仅临时显示系统栏；拒绝平台全屏时 CSS 沉浸布局仍成立，退出后控件完整恢复 |
| 逐音谱面跟随 | 导入同一小节含多个四分音符、左右手交替且带反复的固定样例，分别定位第一遍与第二遍并注入早/错/漏判定 | 光标在同小节音符间横向移动，按手别改变颜色；每次播放出现次数独立，但反复时回到同一正确印刷位置；判定标签位于谱面视口内，不依赖顶部成绩栏 |
| 小节练习热力带 | 对含二小节反复的固定样例，在第一遍注入稳定命中、第二小节注入慢命中与漏音；Core/Studio Chromium 与 Core WebKit 读取热力 DOM 和实际几何 | 展开后的 4 个播放小节分别保持独立统计；稳定段为绿、薄弱段为红、未练段为中性，当前薄弱段高于 7 px 基准带且相邻小节按钮同步着色；点击段走正式小节重开流程 |
| 和弦星座 | 以跨双谱表 C4/C6 同时音和 25 ms 人工铺开的三音和弦验证；在对比主题、6.5 秒视野下对两条音柱之间的弧顶区域做 Canvas 像素采样 | 35 ms 内近同时音符合并，单音和超过 100 ms 的琶音不合并，重复同音不制造假和弦；Core/Studio Chromium 与 Core WebKit 均检出弧线，Android 原生 View 编译门禁通过 |
| 瀑布流演奏视野 | 在练习选项依次选择 2.8、4.2、6.5 秒，重载页面并在 Android 原生瀑布流复核 | 选择持久化；Web Canvas 与 Android 原生 View 显示相同时间跨度；实体灯提前量数值不随之变化；旧版 v1 设置自动使用 4.2 秒默认值 |
| 长谱自动跟随 | `npm run smoke:browser` 自动生成 48 小节、240 音符、双谱表且每 4 小节显式换系统的 MusicXML，在实时模式实际播放 | MusicXML 显式换系统被尊重；当前系统仅在离开 16%–72% 稳定阅读带时平滑滚动；Core/Studio Chromium 与 Core WebKit 的 `scrollTop` 均向后推进且不出现页面横向溢出 |
| 全曲指纹 | 同一长谱在 Studio 分屏播放后读取 Canvas 右缘 72 个采样点，并在 Android API 36 构建后人工核对原生 View | 至少 8 个采样点具有左右手主题色；空密度段近乎透明；白色当前位置/预览框随播放移动；单手选择和 A–B 循环分别弱化非练习声部、标出练习区间；Web/Android 算法单测与编译均通过 |
| 目标力度可视化 | 真浏览器导入同时落键的 `p` 与 `fff` 标准 MusicXML 探针，切换单瀑布后读取两键落键端像素；再在 Android API 36 构建后核对原生 View | 两个音符键位与宽度不因力度变化；强音落键端峰值亮度至少比弱音高 28，当前 Chromium 实测 219.7 对 163.0；图例显示“亮度＝力度”；Web/Android 使用相同绝对力度 + 曲内分位算法 |
| 逐键时序反馈 | 真浏览器向 C4/C6 注入 -90 ms / +110 ms 的正确命中并读取落键线附近像素；Android API 36 构建后核对原生 View | C4 显示蓝色“早”、C6 显示橙色“晚”，±25 ms 显示绿色“准”；偏移量在 ±250 ms 截断；当前 Chromium 检出 151/115 个蓝/橙像素，WebKit 检出 44/34；窄键位无文字重叠 |
| MusicXML/MXL | 运行三份带 SHA-256 的仓库固定语料，并按 `docs/musicxml.md` 审计共 1016 个 W3C、MuseScore、跨厂商和 OSMD 固定版本文件；再运行可选的 `music21 9.9.1` 内容交叉验证；分别导入同一首 `.musicxml` 与 `.mxl`，再导入含 `quarter = dotted-quarter` 且两声部重复标记的固定样例 | 1012 解析 + 4 预期安全拒绝、0 意外异常；6 首真实曲目 2638 个音符的数量/音高序列完全一致，最大起音差 0.109 ms；UTF-16LE/BE、MXL 内 UTF-16、相邻多组 volta、复杂反复和有歧义导航均有明确结果；五线谱、音符数、时长和目标灯一致；速度关系只应用一次且四分音符 BPM ×1.5；谱面可切回瀑布流 |
| 乐谱导航 | 导入含反复、第一/第二结尾、D.C. al Fine、D.S. al Coda 的固定样例 | 目标/判分按真实演奏顺序，OSMD 光标回到正确书写小节；跳转只执行一次且能终止 |
| 本地曲库 | 重复导入同一文件，再新建文件夹并移动乐谱 | 内容哈希去重，只保留一份；刷新页面后仍存在 |
| 曲库备份 | 导出 JSON，在空浏览器配置中恢复 | 文件夹、原始乐谱、名称和统计恢复；篡改内容、悬空目录引用或超出安全规模时校验失败且不产生半恢复数据 |
| 演奏录制 | 在 PX-S7000 分别关闭/开启 `Hi-Reso Velocity MIDI Out`，录制力度、重叠同音、CC64 半踏板、CC66/67 后导出 MIDI，再用 MIDI 检查器查看事件 | 音高/通道/力度和真实 Note Off 正确；开启时每个高分辨率音符前保留同通道 CC88；CC64 中间值及 CC66/67 原值、时刻保留；停止录制时补 CC64=0，回放无挂音 |
| 长录制边界 | 用自动 MIDI 源达到测试版低阈值，并对生产阈值做单元测试 | 达到 4 小时或 200,000 事件即自动停止；页面说明原因，已保存前缀仍可下载，无无限增长或静默截断 |
| 长时间等待 | 在一个目标和弦停留 30 s | 目标灯全程保持；关闭网页后 3 s 内熄灭 |
| 实时练习 | 选择实时模式和 50/100/150% 速度 | 瀑布、目标灯、计时一致，无持续漂移 |
| 节拍器/预备拍 | 用含 3/4→2/4 拍号变化、120→60 BPM 和反复的 MIDI/MusicXML；分别以 50/100/150% 播放 | 强拍跟随每小节起点，变速与反复处拍点正确；开始前只倒数一小节且预备期间不判漏；暂停/复位后无残留点击 |
| 设置恢复 | 修改模式、声部、速度、提前量、节拍器和预备拍后刷新 | 所有支持项恢复；注入损坏或未知版本的本地数据时安全回默认值，页面仍可使用 |
| 更新访问控制 | 分别从家庭 Wi-Fi 和设备热点上传，并各自使用错误/正确管理密码 | 两条网络路径的错误密码均返回 403；正确密码进入写入流程，响应和日志不泄露密码 |
| 自动回滚 | 分别模拟上传中断、候选固件复位、内部自检失败、90 秒无 HTTP/WebSocket 客户端 | 中断不切槽；其余情况回到上一槽；通过自检且真实可访问的版本才确认 |
| 救援入口 | 删除/破坏 LittleFS 后访问 `/recovery` | 固件内置救援页仍可打开并重刷固件或网页镜像 |
| 更新失败安全 | 依次上传过小文件、错误扩展名、超过分区上限和损坏固件 `.bin` | 浏览器前三者不发送；固件端拒绝损坏镜像且不报告成功；伴奏/灯光先安全停止，原固件重启后仍可启动 |
| 双槽固件更新 | 在 app0/app1 间连续更新两个有效测试版本并各断电重启 5 次 | 每次只写非运行槽；版本与运行槽正确交替，NVS 校准/热点密码保留，USB 与灯带功能不退化 |
| 网页文件系统更新 | 上传有效 `littlefs.bin`，重启后强制刷新 | 根页面、所有 gzip JS/CSS、曲库和练习历史可用；版本与发布清单一致 |
| 安装向导防跳过 | 只勾选所有人工项，不连接 ESP/钢琴 | 进度停在 8/12；完成按钮禁用；明确列出 ESP、USB 枚举、IN 端点和中央 C 四项自动证据 |
| 安装向导完成/失效 | 完成全部证据并导出报告，再更新到不同固件版本 | 报告含版本、VID/PID、端点和人工项但不含密码；升级后完成状态失效，必须重新观测 USB 与中央 C |
| 左右手 | 分别选择双手、左手、右手 | 未选声部不进入实体目标或判分；屏幕仅低亮度保留 |
| 移调 | 对同一 MIDI/MusicXML 分别选择 -12、0、+2、+12 | 五线谱/瀑布流/目标灯同步变化；恢复 0 后与原谱一致；曲库原文件哈希不变 |
| A–B 循环 | 设置 A=60 s、B=90 s，连续播放两轮 | 到 B 自动回到 A；没有越界目标，累计成绩不清零 |
| 细粒度变速 | 分别输入 25%、35%、95%、105% 和 200%，在实时/Follow/节拍器模式各运行一段 | 输入统一吸附到 5% 步进；时间线、Follow 间隔和节拍器同步缩放，无负延迟、跳段或界面溢出 |
| 实时判分 | 在目标前后故意制造正确、错键和漏键 | 三类计数分别增加；重复按同一正确音不重复计分 |
| 练习洞察 | 实时模式分别稳定提前约 100 ms、稳定延后约 100 ms，再弹一组力度由弱到强的音 | 拍点分别显示偏早/偏晚；平均与 P95 非负；力度均值和波动随输入改变；重复正确音不污染统计 |
| 练习历史 | 完成一次练习，刷新网页，再改变速度和循环完成第二次并导出 JSON | 两次记录均存在且按新到旧排列；模式/速度/循环上下文正确；JSON 不包含 Wi-Fi 凭据或乐谱原文件 |
| 自适应建议 | 在全曲不同位置制造一组集中错漏，并让一只手错误率明显更高 | 建议锁定包含错漏簇的 A–B 段和较弱手；显示证据量/置信度；一键应用后模式、声部、速度和循环控件完全一致 |
| 弱点巡回 | 对含反复的乐谱完成至少一次有错漏的练习，生成巡回；先用错误设置或未覆盖完整片段的事件提交，再按关卡设置完成一次达标、一次失败、最后连续两次达标 | 各播放出现次数独立聚合；最多三关且不重叠，首关含进入薄弱处前的上下文小节；错误设置/未覆盖该关全部目标音不计尝试，达标计数为 1，失败归零，连续两次才进下一关；刷新后仍恢复同谱进度，同名不同内容与畸形缓存不得载入 |
| 判定时钟同步 | 人工给 `ping/pong` 注入不同 RTT，再给 MIDI 消息注入 20–100 ms 不等的 WebSocket 延迟；另覆盖 uint32 回绕、ESP 重启、未来/过旧消息和无 `deviceTs` 旧固件 | 选择最低 RTT 样本；同一 USB 采集时刻得到同一谱面判定时刻，不随消息到达抖动漂移；回绕连续，重启清空旧偏移，异常消息与旧固件安全退回到达时刻；录音 Note On/Off/踏板使用同一采集时间轴 |
| 自适应判定窗口 | 以 250/500/1000 ms 局部拍间隔、25%–200% 练习速度和 100 ms 重复同音生成判定窗口；真浏览器导入 MusicXML 后切换严格/自适应档并重载偏好 | 快段窗口收紧、慢段受档位上限约束；变速保持音乐拍值比例；相邻同音两侧窗口不超过间隔 48%；档位持久化且界面显示当前现实毫秒范围 |
| 表现力度评分 | 用目标 `[40,60,80,100]` 分别输入精确、统一偏移、压缩和反向实弹力度；再把统一 `+10` 样本注入真浏览器会话 | 精确与统一偏移的轮廓均为 100%，但后者基准显示 `+10`；压缩/反向显著降分；目标无有效对比时不产生分数；时间复盘、历史趋势和教练均消费同一事件字段 |
| 时值与踏板表达 | 对同音重触发、普通 Note Off、CC64 踩下后松键/再抬踏板、All Notes Off、提前收音和精确释放做纯函数测试；MusicXML 注入 staccato/staccatissimo/detached-legato/tenuto；真浏览器注入四个完整目标时值及两种松键反馈 | 物理按键时长与踏板发声时长分离；丢失 Note Off/急停不伪造证据；目标门控为 0.5/0.25/0.65/0.95；实时卡显示“覆盖 100% / 释放 100% / 未检测到踏板延音”；瀑布流用青色 `↔/时值` 与橙色 `↘/短 xx%` 区分达标和提前收音；提前收音时间段为黄色并可生成带时值门槛的巡回关卡 |
| 和弦与双手同步 | 构造同起点跨手和弦、同手和弦、20–100 ms 展开、相邻琶音、重复事件和含漏音残缺组；真浏览器注入四个右手晚 20 ms 的完整跨手和弦 | 只对精确同起点且完整命中的唯一琴键分组；≤30 ms 满分、120 ms 为 0；琶音/漏音不伪造样本；实时卡显示“和弦 100% / 平均 20 / P95 20 ms”和“右手晚 20 ms”；复盘标出松散时间段，教练阻止盲目提速，专项巡回要求 `和弦整齐度 ≥80%` |
| 断网安全 | 练习中关闭手机 Wi-Fi | 3 s 内目标灯自动熄灭；钢琴仍可正常发声 |
| 断电恢复 | 重启 ESP32 | 亮度、反向和偏移保持 |
| 逐键微调 | 将 C4 修正 +1、A0 修正 -1 后重启 | 两键各移动一枚灯珠，其余键不变；网页重新打开仍显示修正值 |
| 校准存储诊断 | 重启后查看“设备诊断 → 校准存储 NVS”，再确认逐键修正仍存在 | 显示“正常”且修正保持；若显示异常，停止校准并先重刷/检查 Flash，不误报已保存 |
| 复位原因诊断 | 正常断电重启一次，再在固件亮度上限连续点亮并强奏 | 正常启动显示 `power-on`；测试中不得自行重启，之后不得出现 `brownout`、`panic` 或 `watchdog` |
| USB→灯内部延迟 | 连续弹奏单音、和弦与快速音阶至少 200 个 Note On/Off，读取设备诊断 | 样本持续增长、最大值 `<10 ms`、丢包/坏包/传输错误均为 0；它只覆盖 USB 回调到 SPI 完成，仍需视频测端到端 |
| 输出镜像辨识 | 双手离开琴键，用跟随伴奏单独播放至少 100 个音符，记录输入包数和“疑似输出镜像”前后值 | 钢琴能发声；输入包数和镜像计数不应随纯输出增加。若增加，保存串口日志与精确计数；固件仍不得吞输入或把启发式结果冒充事实 |
| 30 min 温升 | 最亮允许值下运行混合图案 | 灯带、接头、线束任何点低于 55°C，无异味或变色 |
| 供电压降 | 最亮允许值运行 10 min，分别测电源入口、灯带首端和远端 | 入口不低于4.75 V；任一灯带端相对入口下降不超过0.25 V；无肉眼可见首尾色差 |
| 保险保护 | 断电取下3 A保险丝再尝试上电 | 灯带、ESP32和OTG支路均不得上电；装回同规格保险丝后恢复 |
| 机械 | 全键强奏、移动谱架和轻拉线缆 | 竖直灯带不触键、不位移、不产生异响；灯光能落到对应琴键 |

完成 USB 枚举和和弦测试后打开“设备设置 → 设备诊断”：VID/PID、IN 端点和 OUT 端点应为非零值；输入包数应随弹奏增加，OUT 发送数应随跟随伴奏增加，排程最终回到 0；PSRAM 总量应约为 8 MiB，输入侧 `丢包 / 坏包 / 传输错误` 必须保持 `0 / 0 / 0`，输出侧 `丢包 / 错误` 必须保持 `0 / 0`。合法但未使用的 SysEx、时钟和 Active Sensing 不计为坏包。正常枚举后“USB 最近原因”应为“无”；若不是，导出的验收 JSON 会保留这个不含凭据的原因。正常使用时 ESP/浏览器两侧“拒绝消息”都应保持 0；只有故障注入或旧页面连接时才允许增加。USB→灯内部延迟样本应随按键增长且最大值低于 10 ms。若 OUT 显示“设备未提供”，先保存 VID/PID、完整串口日志和端点截图，再使用无伴奏跟随，不更换为 SPI USB Host 模块。若丢包或内部延迟增加，先保存页面截图和串口日志，不要通过增大队列掩盖 USB/任务阻塞问题。

发布构建还必须执行 `platformio run -d firmware -t buildfs`，并用 `mklittlefs -l` 读取生成镜像确认其中同时存在 `index.html` 和全部 `.gz` 资源。PlatformIO 旧打包器曾出现命令返回成功但单文件加入失败，不能只看最后一行 `SUCCESS`。

出现过热、闪烁、随机重启、USB 反复掉线或 5V-GND 短路时立即断电，不通过增加亮度或换大保险丝掩盖故障。

## D. 延迟记录

网页同时显示 WebSocket 往返、判定时钟误差上界和近期 MIDI 路径估计。网络不影响“琴键 → ESP32 → 灯带”本地链路；网页判定和录音虽经网络接收，但使用 ESP32 的 USB 采集时间戳，不再直接使用每个 WebSocket 包的到达时刻。验收时录制 120 fps 手机视频，同时拍到手指、灯和屏幕，抽查 20 次按键。目标为按键反馈灯中位数 <25 ms、95 百分位 <40 ms；超过时先排除手机省电和 Wi-Fi 拥堵，再检查固件串口日志。

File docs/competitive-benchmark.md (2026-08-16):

# 竞争能力与领先性审计

> 固定快照：2026-08-05。比较对象与源码提交见 [开源项目技术调研](open-source-review.md)。这里的“领先”仅指“PX-S7000 单条实体灯带练习系统”这一目标，不把 VST、视频导出或通用吉他谱转换等旁支功能硬算成钢琴灯带能力。

## 可审计结论

NoteFall 88 已经不是“ESP32 点亮一条灯带”的演示，而是当前对标项目中唯一同时具备下列组合的开源工程：

1. PX-S7000 USB-B → ESP32-S3 原生双向 USB-MIDI，按键反馈不经过手机、浏览器或 Wi-Fi；同批事件先完成 SPI 灯帧、再广播网页，并自测 USB 回调到 SPI 完成延迟；
2. APA102/SK9822 硬件时钟灯带、5 V 电平转换、双端注电、固件亮度硬上限和故障熄灯；
3. Core 原生 MIDI + MusicXML/XML/MXL，Studio 另有离线 MSCZ/MSCX/Guitar Pro/KAR 转换、五线谱 + 瀑布流、真实反复/结尾/D.C./D.S./Fine/Coda 播放顺序；
4. Realtime、Wait for Me、Follow Me、左右手、25%–200% 五个百分点步进变速、移调、A–B、谱面节拍器和预备拍；
5. 双向 Follow Me、所选声部全谱示范和刚录演奏回放均直接调用 PX-S7000 音源；具备有界时间窗排程、长音延后 Note Off、踏板状态恢复、疑似输出镜像诊断、控制授权、多页面互斥和 16 通道急停；不会用不可区分的时间启发式删除真实琴键输入；
6. 逐音时序、力度基准/相对强弱轮廓、物理松键/踏板发声时值、和弦/双手同步与 MusicXML 谱面踏板（含换踏、半踏深度）分析，带表现力趋势的持久历史、难点键、可解释的单轮建议，按反复展开小节自动编排、连续达标才进阶、可中断恢复的多片段弱点巡回，以及不会被短循环刷分欺骗的跨曲目间隔复习队列；
7. IndexedDB 曲库、去重、校验备份、保留真实 Note Off、CC88 高分辨率力度与连续 CC64/66/67 的通道化演奏录制、标准 MIDI 导出及长录制内存上限；
8. ESP32 USB 回调采集时间驱动判定与录音，浏览器以最低 RTT 样本同步单调时钟并处理 uint32 回绕/重启，使 Wi-Fi 到达抖动不直接污染早晚评分；
9. 逐和弦节拍自适应判定窗、宽容/自适应/严格三档、变速下音乐比例保持，以及快速重复同音防串音匹配；
10. 逐键灯位校准、设备诊断、有自动证据的安装向导、SoftAP 限定认证 OTA，以及 STA 默认只读/会话再认证控制面；
11. 参数化键位/CAD、可采购 BOM、逐引脚线束表、功耗/压降计算、可重复制造包和跨层 CI。

这是“组合领先”，不是声称每个不相关功能都最多。Studio 已补齐 PTS 原先明确领先的 MuseScore/Guitar Pro 浏览器转换，并将它改造为锁版本、无 CDN、Worker 隔离、转换后入曲库的离线链路；Core 仍维持约 436 KiB 并且不承担 GPL/WASM 容量。Piano-LED-Visualizer 仍有成熟的树莓派/Linux 部署经验；Openthesia 仍领先于本项目不追求的桌面 VST、音频和视频工作流。

### 可视化专项证据

固定源码快照中，Openthesia 提供成熟 GPU 瀑布流、配色与发光效果，PTS 提供五线谱跟随和练习判定，Piano-LED-Visualizer 提供灯带/网页模拟器；对四个参考仓库的产品源码检索未发现全曲音符密度图或把“整曲位置、当前预览窗、A–B、左右手密度”合并在瀑布流边缘的实现。NoteFall 当前同时具备：

1. 单谱面、单瀑布流、谱面 + 瀑布流三种布局，以及不占顶部高度的 Web/Android 沉浸全屏；
2. 2.8/4.2/6.5 秒可调视野、真实拍号/小节线、临近落键跑道、按键状态、逐键命中/错键/漏键反馈、带毫秒方向的早/准/晚琴键时序尺、MusicXML 踏板提前提示轨，以及不改变键位几何的目标力度亮度/高光/落键帽编码；35 ms 内近同时到达的和弦会生成连接各音的“和弦星座”弧线，跨双手时在弧顶显示协调菱形；五线谱导航另有 7 px 全曲练习热力带，把命中、错漏与时序偏差按反复展开后的小节着色，点击薄弱段即可从该处重练；
3. MusicXML 显式换系统、16%–72% 稳定阅读带自动翻谱；
4. 72 段双手全曲指纹，叠加当前位置、当前预览窗和 A–B 区间，并在只练单手时弱化另一声部；
5. Web Canvas 与 Android 硬件加速原生 View 两套渲染器保持同一语义，浏览器回归会对指纹颜色、`p`/`fff` 力度像素和长谱滚动作实际检查。

这证明的是**练琴信息可视化组合**已超过固定参考快照，不等同于宣称 NoteFall 的纯舞台特效、VST 或视频导出超过 Openthesia；后者仍属于明确的对标边界。

## 逐项矩阵

符号：`●` 完整；`◐` 部分或需额外设备；`—` 无。每个 NoteFall `●` 都必须在仓库中有实现、测试或实物验收条目，不能只写在路线图里。

| 目标内能力 | PTS | Piano-LED-Visualizer | PianoLux | Openthesia | NoteFall 88 |
|---|:---:|:---:|:---:|:---:|:---:|
| 钢琴到灯的本地确定性链路 | ◐ 浏览器/WLED/helper | ◐ Linux/Python | ● | — | **● USB→ESP→SPI** |
| 不依赖电脑或 Web MIDI | ◐ | ● | ● | — | **●** |
| MIDI + MusicXML/MXL | ● | ◐ MIDI | ◐ MIDI | ◐ MIDI | **●** |
| MuseScore / Guitar Pro / KAR 离线导入 | ● | — | — | — | **● Studio Worker，无 CDN** |
| 谱面与瀑布双视图 | ◐ 谱面 | ◐ | ◐ | ◐ 瀑布 | **●** |
| 沉浸全屏 + 双手全曲指纹 | — | — | — | ◐ 全屏瀑布 | **● Web/Android** |
| 三种练习模式 | ● | ◐ | ◐ | ◐ | **●** |
| 琴内音源 Follow Me | ◐ 由浏览器MIDI输出 | ◐ | — | ◐ | **● 带安全排程** |
| 所选声部示范 + 录音直接回放 | ◐ 乐谱播放 | ◐ 录音回放 | — | ● 本机音源 | **● PX-S7000 音源，跨通道/踏板/变速/长音安全** |
| 完整反复/跳转语义 | ● | ◐ | ◐ | ◐ | **●** |
| 逐音时序、力度、历史 | ◐ | ◐ | — | ◐ | **●** |
| 目标力度轮廓评分、趋势与教练反馈 | — | — | — | ◐ 视觉/演奏输入 | **●，基准校正且无对比不伪造分数** |
| Note Off 时值、CC64 发声覆盖、释放趋势与关卡 | — | ◐ 录制/回放 | — | — | **●，指尖/踏板分离，断奏门控感知** |
| 和弦展开、左右手同步评分/趋势/专项关卡 | — | — | — | ◐ 仅视觉和弦 | **●，精确起点分组且残缺和弦不伪评分** |
| MusicXML 谱面踏板时机/半踏深度评分、趋势与关卡 | — | — | — | — | **●，逐遍隔离且无记号不伪评分** |
| 可解释自适应建议 | — | — | — | — | **●** |
| 多片段掌握路线与连续达标进阶 | — | — | — | — | **●，反复安全且本机恢复** |
| 跨曲目掌握度与间隔复习队列 | — | — | — | — | **●，全曲证据防短循环刷分** |
| 硬件采集时间判定，不受逐包 Wi-Fi 抖动污染 | — | — | — | — | **●，带误差上界/回绕/重启保护** |
| 局部节拍自适应判定 + 快速同音防串匹配 | — | — | — | — | **●，三档且变速保持音乐比例** |
| 逐键灯位校准 | ● | ◐ | ◐ | — | **●** |
| 自动实机证据向导 | — | — | — | — | **●** |
| 认证 OTA + 双槽更新边界 | — | — | ◐ | — | **●** |
| 参数化机械/电气制造包 | — | ◐ | ◐ | — | **●** |
| 可重复生成和跨层 CI | ◐ | ◐ | ◐ | ◐ | **●** |

## 性能与资源预算

| 指标 | 数字门禁 | 当前可审计证据 |
|---|---:|---|
| 176 像素 SPI 帧 | 理论线速 `< 1 ms` | 固定 `719 B`、`8 MHz`，理论线速 `0.719 ms`；固件另上报 SPI last/max，实际总耗时待台架测量 |
| 浏览器 HiDPI 画布 | `DPR ≤ 2`、后备像素 `≤ 7,500,000` | Pad 7 Ultra 的 `1600×1068 @2x` 为 `6,835,200` 像素；超过预算时自动降低栅格比例 |
| 浏览器绘制负载 | 重绘约 `≤60 Hz`；空闲 `500 ms` 心跳；谱面跟随间隔 `≥80 ms` | 事件驱动调度、时间窗二分裁剪与 `>160` 可见音符简化路径已有单元/真浏览器门禁；实机持续帧时间待验 |
| Android 原生瀑布流 | 动画绘制间隔 `≥15 ms` | 硬件加速原生 View、单调时钟推进、时间窗裁剪及 debug APK 构建通过；Pad 7 Ultra 持续帧时间待验 |
| 键中心到主像素理论误差 | `≤ 最大物理灯距的一半` | `3.408 mm`（已纳入 31/32、103/104 两个实物焊缝） |
| 固件亮度上限设计电流 | `< 3 A × 80%` | `2.013 A` |
| 20 AWG 最坏支路压降 | `≤ 5%` | `1.45%` |
| 5 V / 5 A 电源利用率 | `< 60%` | `40.3%` |
| 固件 RAM / Flash | 最新生产构建通过并保留诊断裕量 | 不在文档冻结会随固件变化的早期百分比；以当前 CI 构建报告为准 |
| 嵌入网页压缩资源 | `< 500 KiB` | 由最新发行构建和包内容门禁核验，不在基准文档冻结易过期字节数 |
| 离线发行一致性 | 清单字节数/SHA-256、内容寻址 cache、离线重载全通过 | 分发校验器与真实浏览器 PWA 离线 smoke 同时执行，避免旧 HTML 与新 chunk 混装 |
| 自动测试 | Python、Web、真浏览器、生产构建及适用原生/固件门禁全通过 | 以 **latest automated suite** 为准，不冻结会随回归增长的数量；Web 覆盖率 CI 门限 S/B/F/L 为 `85/75/85/90%`，另保留 1016 文件语料审计与 6 首/2638 音符 music21 交叉验证 |

计算值不能代替实物：LED 克隆批次的真实电流、最远端电压、接头温升、USB 端点、USB→SPI 总延迟与平板持续帧时间只能在装机后测量。完整数字门禁和实物边界见 [English quality and performance evidence](en/quality-and-performance.md)。

## 领先性成立的边界

- **数字工程领先：** 源码、协议、安全、可重复生成、发布包和测试门禁全部通过后成立。
- **目标内产品领先：** 还需一台 PX-S7000 完成 [实机验收](testing.md)，特别是 USB 双向端点、88 键、30 分钟温升、断线急停，以及用 120 fps 视频采集至少 20 个样本的端到端延迟（中位数 `<25 ms`、P95 `<40 ms`）。
- **量产领先：** 还需至少一套由第三方按 `harness.csv` 制作的线束与一个 PETG 控制盒通过装配反馈；在此之前只能称 release candidate，不能虚称量产验证。

## 明确不塞进 Core 的功能

- MuseScore/Guitar Pro 转换：已进入 NoteFall Studio 的离线 Worker，但不进入 Core，不让大体积 GPL/WASM 成为 ESP32 启动或救援网页条件。
- VST/SoundFont/视频录制：PX-S7000 自己发声，手机负责练习，不让音频工作站职责污染实时灯光链路。
- 云账号、订阅和远程遥测：项目离线可用，练习历史默认只留本机。

这些不是“没做完的核心功能”，而是经过目标、可靠性、许可证和移动端资源边界审计后的分层决定。

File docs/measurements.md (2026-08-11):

# PX-S7000 一次性现场复核

2026-08-05 的去敏照片审查已经确认：琴键后方存在连续、固定、朝向演奏者的黑色立面，照片比例估算可用高度约 `18–22 mm`，足以容纳宽约 12 mm 的 APA102C/SK9822 裸灯带。该数值是照片估算，不是 0.5 mm 级制造测量；原始照片含私人信息，不属于项目资料，不复制、不提交、不发布。

因此竖直裸灯带方案和 1222 mm 标准 88 键基准可继续，不需要琴键侧打印导轨。2026-08-11 实物照片与计数确认，已购 176 灯并非无接头连续 PCB，而是 `32 + 72 + 72` 三段串联；两个焊点分别位于从物理左端数第 32、104 灯之后。以名义 `6.944 mm` 节距作照片内标尺，对焊缝两侧各 8–11 颗灯的中心做局部透视拟合，得到 31/32 缝中心距约 `11.17 mm`（额外 `4.22 mm`），103/104 缝约 `10.92 mm`（额外 `3.98 mm`）；模型残差约 0.25–0.43 图像像素，工程不确定度按约 `±0.15 mm` 使用。生成器已经按三段真实坐标计算最近灯珠，残余误差由三点/逐键校准吸收。

| 编号 | 复核方法 | 通过条件 | 需要反馈的数值 |
|---|---|---:|---:|
| M1 | A0 最左白键左边缘到 C8 最右白键右边缘；非阻塞，装好后用三点校准复核 | 约 1222 mm | ____ mm |
| M2 | 剪一条 `12 × 100 mm` 普通纸条贴在 C4 附近拟安装位置，不用胶接触琴体 | 纸条完全位于固定黑色立面，不盖红毡 | 通过 / 不通过 |
| M3 | 纸条底边距自然白键面约 2–3 mm，依次全按相邻白键和黑键 | 任意行程均不接触、不夹纸 | 通过 / 不通过 |

M2/M3 是安装验收，不是重新设计。若不通过，不购买另一条测试灯带：先在同一立面上移纸条；仍不通过才选择同协议、同密度的更窄 PCB 批次。只有纸条通过后才允许撕灯带背胶或安装无痕固定条。

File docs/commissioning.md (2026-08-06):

# 引导式安装与实机验收

设备网页右上角的“硬件尚未验收”不是装饰状态。安装向导把必须由人确认的物理事实与能由设备直接观测的数字证据分开；缺任何强制项都不能生成“已完成”状态。

## 证据模型

| 类别 | 项目 | 来源 |
|---|---|---|
| 断电人工 | 5V-GND、DATA/CLOCK 万用表检查 | 用户在断电实物上确认 |
| 断电人工 | 3 A 保险丝，距电源入口不超过 100 mm | 用户确认线束 |
| 断电人工 | 灯带电流不经过 ESP32，全部 5 V 支路受 3 A 总保险保护 | 用户确认接线 |
| 机械人工 | 琴体接触材料无永久胶/硬边 | 用户确认材料 |
| 自动 | 兼容协议的 ESP WebSocket 状态 | 设备状态帧 |
| 自动 | 已修改公开的默认热点密码 | 设备只读 `defaultPassword=false` 状态，不记录密码内容 |
| 自动 | PX-S7000 枚举、VID/PID、MIDI IN 端点 | ESP32 原生 USB Host |
| 自动 | 钢琴实际中央 C Note On | USB MIDI 事件，不接受页面按钮代替 |
| 灯位人工 | A0、C4、C8 三点亮点对应 | ESP 发测试灯，用户看实物确认 |
| 机械人工 | 强奏/谱架/线缆扰动后无触键、位移、异响 | 用户完成实物试验 |

MIDI OUT 是跟随伴奏能力，不是基本目标灯的阻塞条件；缺失时报告保留“设备未提供/尚未观测”，产品明确降级。USB 输入错误大于 0 或仍使用公开默认热点密码都会阻止完成，不能靠勾选覆盖。报告还保留固件最近一次不含凭据的 USB 枚举/传输原因，方便区分描述符畸形、无 MIDI IN 与底层提交失败；成功连接后该字段应为空。

## 状态、升级与报告

完成状态保存在浏览器本地并记录当时固件版本。检测到固件版本变化后，物理接线勾选保留，但完成标志、USB 枚举和中央 C 证据失效；新固件必须重新观测后再完成。若密码后来改回公开默认值，完成标志也立即失效。

任何时候都能导出版本 1 JSON，包含：

- 完成与否和缺失项目；
- 固件/协议；
- VID/PID、IN/OUT 端点；
- 已观测输入包、错误数；
- 所有人工作业布尔项和完成时间。

报告不含热点/家庭 Wi-Fi 密码、曲库、演奏历史或原始乐谱。它是可审计的安装记录，不是加密签名或第三方认证；用户仍能手工修改浏览器存储，所以量产质检若需要防篡改，应由工厂工具签署序列号报告。

## 通过后的下一步

引导完成只证明基础接线、USB、三个灯位和机械干涉已检查。完整发布仍需执行 [上电、校准与验收](testing.md) 中的 88 键映射、和弦、断线、跟随伴奏、温升和 120 fps 延迟项目。

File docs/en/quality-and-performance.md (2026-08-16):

# Quality and performance evidence

This report records the current, auditable quality baseline for NoteFall 88. It separates properties demonstrated by source inspection and automation from results that can only be measured on the delivered ESP32-S3, LED strip, and PX-S7000. A passing software gate is not presented as proof of physical latency, thermal safety, optical comfort, or piano compatibility.

The continuously updated release decision remains in the [release-readiness gate](../release-readiness.md). See also the [system architecture](architecture.md), [protocol](protocol.md), [Studio guide](studio.md), [test procedure](testing.md), [competitive benchmark](../competitive-benchmark.md), and [completion audit](../completion-audit.md).

## Large-tablet visual path

The primary tablet target is the Xiaomi Pad 7 Ultra: a 3200 x 2136, approximately 3:2 panel. At a device-pixel ratio of 2 this corresponds to a 1600 x 1068 CSS viewport, so browser automation exercises both that representative viewport and the full physical-pixel dimensions as a worst-case 1x layout stress test. The same smoke suite also covers 390 x 844 and 1280 x 900.

Studio supports notation-only, waterfall-only, and split views. Focus mode removes the top bar, transport, and score strip from layout rather than merely making them transparent. At 3200 x 2136, the browser probe measured a 2130 px-high performance surface starting 3 px from the top. At 1600 x 1068, notation-only mode occupies at least 90% of its container without horizontal overflow. Controls use tablet-sized touch targets, the layout remains usable with browser fullscreen denied, and CSS includes reduced-motion and increased-contrast adaptations.

The browser renderer keeps coordinates in CSS pixels while [`canvasRasterSize`](../../web/src/layout.ts) limits device-pixel ratio to 2 and backing-store area to 7,500,000 pixels. The Pad target at 1600 x 1068 and DPR 2 needs 3200 x 2136, or 6,835,200 backing pixels, and therefore retains full 2x detail within the budget. Extremely large or unusual display scales are reduced rather than allowing an unbounded multi-megapixel surface to be repainted continuously.

## Rendering work is bounded

The web [`waterfall renderer`](../../web/src/waterfall.ts) does not scan an entire long score on every frame. Notes, beats, chords, and pedal events are time ordered; binary lower-bound searches select only the visible window, including notes that began before the window but are still held. Key geometry is indexed for constant-time lookup. When more than 160 notes are visible, the renderer selects a simpler dense-frame drawing path instead of constructing the most expensive rounded and gradient shapes for every note.

The [`render scheduler`](../../web/src/render-scheduler.ts) is dirty/event driven when playback is idle. It paints continuously only while the score clock, demonstration, recorded-performance replay, or feedback animation is active. High-refresh displays are gated to at most approximately 60 expensive Canvas paints per second; idle diagnostics request a refresh every 500 ms, and sheet-follow scrolling is coalesced to no more than once per 80 ms. Canvas contexts request an opaque, desynchronized surface where the browser supports it. These are deterministic workload gates, not a claim that every device has already sustained 60 fps under every score.

Browser smoke tests cover Chromium and WebKit across the four viewports above, real MusicXML/OSMD rendering, long-score following, repeated measures, dynamics, cross-hand chord guides, early/late feedback, release feedback, and the three view modes. They assert layout and rendered evidence; hardware GPU timing, battery use, and thermal throttling remain device measurements.

## Native Android path

The Android package is more than a WebView-only wrapper for the performance surface. [`NativeWaterfallPlugin`](../../studio/android/app/src/main/java/io/notefall/studio/NativeWaterfallPlugin.java) installs a hardware-accelerated native `View`, advances playback from Android's monotonic clock between lower-rate bridge updates, sorts and window-prunes notes, beats, and pedal events, and reuses cached gradients. Its animated-paint gate has a 15 ms minimum interval. App lifecycle and immersive-system-bar behavior are bridged explicitly, while the PWA/Canvas implementation remains a compatible fallback and desktop route.

The Android debug build proves compilation and packaging of this native path. It does not prove Xiaomi-specific sustained frame time, hotspot reconnection after lock-screen transitions, signed release installation, or the still-pending iOS native/signing path.

## Practice claims use evidence, not a raw percentage

The [`practice evidence model`](../../web/src/practice-evidence.ts) uses a 95% Wilson interval so a tiny perfect or failed sample cannot masquerade as certainty. Automated boundary examples include 0/10 attempts with an upper bound of 27.8% and 10/10 with a lower bound of 72.2%.

Confidence and coaching use explicit gates:

| Decision | Gate |
|---|---|
| High confidence | complete telemetry, at least 5 sessions, at least 80 judged attempts, and Wilson interval width no greater than 14 percentage points |
| Medium confidence | complete telemetry, at least 2 sessions, at least 20 attempts, and interval width no greater than 28 points |
| Improving or declining | absolute change of at least 4 percentage points, with non-overlapping recent and older Wilson intervals in the claimed direction |
| Automatic tempo increase | complete telemetry, lower 95% accuracy bound at least 88%, no declining trend, and session consistency at least 70 when available |

Imported duplicate sessions are deduplicated, session consistency is reported separately, and any dropped or truncated event makes telemetry incomplete and blocks automatic tempo increases. Whole-piece mastery and spaced-practice decisions additionally require meaningful score coverage, so a short repeated loop cannot promote the entire piece. These rules make recommendations conservative and explainable; they are learning aids, not medical or psychometric certification.

## Firmware real-time path and observability

The ESP32-S3 native USB Host callback records a timestamp, places the complete USB transfer into fixed storage, and wakes a dedicated Core 0 real-time task. That task merges the queued batch into one coherent LED frame before browser/network JSON work runs on the Arduino loop. USB input and output queues each have capacity 128, the browser-forwarding queue has capacity 128, and scheduled MIDI output has capacity 256. The real-time task uses a 6144-byte stack, priority 7, and a 5 ms idle poll. Network congestion therefore cannot directly block the USB-to-LED critical section.

One 176-pixel APA102/SK9822 frame is exactly 719 bytes. At 8 MHz, its theoretical wire time is 0.719 ms, inside the `< 1 ms` digital budget; unchanged idle frames are skipped. This calculation excludes task wake-up, processing, and hardware-library overhead, so the firmware reports the real SPI last/max duration rather than treating the calculation as a physical measurement.

Additive optional protocol-v6 status fields expose:

- USB input/output queue depth and high-water marks, the largest input batch, resubmit retries, and client/daemon watchdog state;
- callback-to-MIDI-dispatch and callback-to-LED-SPI-complete latency, including last/average/max samples;
- LED frame count, skipped frames, SPI last/max duration, and frame bytes;
- browser MIDI queue depth, high-water mark, drops, and recovery resynchronizations;
- real-time task readiness, watchdog, heartbeat age, wakeups, and free stack; and
- current and maximum Arduino main-loop duration.

All new fields are optional and the protocol version is unchanged, preserving compatibility with older firmware and web clients. Queue growth, drops, watchdogs, and stack margin are acceptance evidence: a larger queue is not an acceptable way to conceal sustained overload.

## Offline release consistency and supply chain

Studio's [`service worker`](../../studio/public/sw.js) uses a `notefall-studio-` cache prefix plus a content-derived 16-hex-digit release version. Installation fetches the complete immutable precache with `cache: "reload"`; activation deletes only older NoteFall caches. Navigation and hashed assets are served from the same versioned cache, while dynamic same-origin requests and byte-range requests are not replayed from a stale runtime cache. This prevents an old HTML shell from being mixed with new JavaScript chunks during an update.

The [`distribution verifier`](../../web/scripts/verify-studio-dist.mjs) checks the generated asset manifest's byte lengths and SHA-256 values, the injected cache version, precache completeness, cache scoping, and the absence of unscoped cache lookup. The [`offline PWA smoke test`](../../web/scripts/pwa-offline-smoke.mjs) installs and activates the worker in a real browser, reloads while offline, checks asset lengths and version continuity, and exercises offline MSCX conversion under the production content-security policy.

Dependency inputs are reviewable: JavaScript installs use lockfiles, Python engineering dependencies are version pinned, GitHub Actions references use immutable commit SHAs, [dependency review](../../.github/workflows/dependency-review.yml) rejects newly introduced moderate-or-higher vulnerabilities on pull requests, and [Dependabot](../../.github/dependabot.yml) checks Actions, both npm workspaces, and Python dependencies weekly. This controls reproducibility and stale dependency risk; it does not replace artifact signing, upstream provenance review, or timely remediation.

## Numeric gates

| Area | Automated or design gate | Physical acceptance boundary |
|---|---:|---:|
| Responsive layouts | 390 x 844, 1280 x 900, 1600 x 1068, and 3200 x 2136 in Chromium and WebKit smoke coverage | repeat the landscape check at the tablet's default and daily display-size settings |
| HiDPI Canvas | DPR no greater than 2; backing area no greater than 7,500,000 pixels | sustained frame time, battery draw, and thermal throttling on the Xiaomi tablet |
| Web painting | expensive Canvas paint no faster than about 60 Hz; idle refresh 500 ms; sheet follow no faster than 80 ms | visual smoothness with representative long and dense personal scores |
| Dense score | simplified draw path above 160 visible notes | no dropped or misleading notes in stress repertoire |
| Native Android paint | minimum 15 ms between animated draws | measured frame-time distribution and lifecycle recovery on the installed tablet |
| Firmware queues | USB IN 128, USB OUT 128, browser 128, scheduled MIDI 256 | zero drops/resyncs in normal playing; depths and high-water marks return toward idle |
| Real-time task | Core 0, priority 7, 6144-byte stack, 5 ms idle poll | healthy heartbeat/watchdog and stable free-stack margin |
| LED SPI | 719 bytes at 8 MHz; theoretical wire time 0.719 ms | reported SPI last/max plus scope or logic-analyser confirmation if anomalous |
| Internal input-to-light path | instrumented maximum below 10 ms over at least 200 Note On/Off events | must be measured after real PX-S7000 USB enumeration |
| Visible end-to-end latency | test method: at least 20 samples in 120 fps video | median below 25 ms and P95 below 40 ms |
| Power and heat | calculated brightness/current and voltage-drop budgets remain in CI | 30-minute run below 55 °C and far-end voltage drop no greater than 0.25 V |
| Practice promotion | Wilson/confidence/coverage gates described above | user evaluation that recommendations remain musically useful across repertoire |

The repository reports the **latest automated suite** rather than freezing a test count in this document. The count changes as regression coverage grows; the meaningful claim is that the current CI, browser smoke tests, production builds, distribution verification, and applicable native/firmware builds pass together.

## What remains dependent on real hardware

Automation has established type safety, parser and state-machine behavior, protocol compatibility, bounded data structures, layout geometry, browser-rendered evidence, offline release integrity, Android debug packaging, and host-executed firmware core tests. It has not established the following physical facts:

- PX-S7000 USB enumeration, actual endpoint topology, bidirectional MIDI OUT behavior, CC88 behavior, and disconnect/reconnect recovery;
- measured callback-to-SPI and visible key-to-light latency on the target board and piano;
- all 88 calibrated key-to-pixel positions, including the two strip seams, and the seams' electrical reliability;
- far-end voltage, connector temperature, LED-strip temperature, brightness, glare, and optical visibility;
- key-travel clearance, removable adhesive behavior, and absence of cosmetic damage after removal;
- Xiaomi Pad 7 Ultra frame pacing, power use, hotspot/STA switching, lock-screen recovery, and long-session persistence; or
- signed iOS build, native lifecycle behavior, and distribution.

Until the corresponding steps in the [physical test procedure](testing.md) pass and their measurements are recorded, NoteFall 88 remains a digitally verified release candidate rather than a hardware-validated production release.

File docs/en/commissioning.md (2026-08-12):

# Commissioning and calibration

## Acceptance order

1. With the piano disconnected, inspect polarity, fuse, capacitance polarity, insulation, and strain relief.
2. Power the controller and run the low-brightness LED chase. Confirm every LED and both splice regions work.
3. Connect the piano through native USB host and confirm USB MIDI enumeration.
4. Press middle C on the piano and confirm a real MIDI Note On appears in diagnostics.
5. Temporarily mount the strip and run A0, C4, and C8 light tests.
6. Select strip direction, then set global offset. Physically reposition the strip if the gross alignment is wrong.
7. Use bounded individual-key correction only after three-point alignment is correct.
8. Test all 88 keys, both splice regions, pedals, Wi-Fi reconnect, USB reconnect, and safe-off behavior.

## Calibration rules

- Direction reversal handles a strip installed from the opposite data end.
- Global offset handles a uniform one-pixel placement residual.
- Per-key correction is intentionally limited to +/-4 pixels. It is for small mechanical tolerance, never for disguising a badly positioned strip.
- Calibration is saved in ESP32 NVS and survives a normal restart.

## Pass criteria

- Every target key lights its intended local key area.
- No two piano keys share a primary LED.
- No LED, solder joint, carrier, or cable contacts a key during a full-travel press.
- A USB loss, target timeout, invalid command, or reboot turns target lights off.
- The controller remains cool and the power supply/fuse wiring show no abnormal behavior.

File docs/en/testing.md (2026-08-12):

# Test and acceptance

## Electrical tests

- Power off: verify no 5 V-to-GND short, connector polarity, fuse rating, and capacitor polarity.
- Power on at the firmware brightness limit: inspect every LED, measure for unexpected heating, and test both ends of power injection.
- Exercise the cable harness gently; lights must not flicker and no force may reach a strip solder pad.

## Functional tests

- USB MIDI enumeration, keyboard Note On/Off, pedal CC64, disconnect/reconnect.
- A0/C4/C8 anchors plus all 88-key calibration sweep.
- Real-time, Wait for Me, Follow Me, part filtering, loop, tempo, transpose, recording and playback.
- Score-only, piano-roll-only, and combined tablet layouts.
- Wi-Fi reconnect, browser refresh, offline library recovery and settings persistence.

## Safety tests

- Full travel of every black and white key with the fixture installed.
- Controller clears lights on watchdog reset, USB loss, WebSocket target timeout, and invalid input.
- Confirm that loss of the tablet or Wi-Fi cannot prevent physical key feedback from functioning safely.

Record each result in the Chinese deployment checklist (`docs/deploy/arrival-checklist.md`).

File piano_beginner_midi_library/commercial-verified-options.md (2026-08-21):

# 已核验但需购买的真人演奏 MIDI

本文件**不是曲库内容**，也不包含任何 MIDI 二进制文件。它只记录已经核验过来源、但不能未经购买下载的真人演奏选项。

筛选标准与本曲库完全相同：页面必须明确说明该 MIDI 是具名演奏者直接演奏/录制的结果，而不是乐谱导出或音频转写。购买前仍应由购买者自行确认商品页与授权范围；以下产品目前均标价 **US$9.95**，仅供个人使用的授权以商店最终条款为准。

| 目标曲目 | 演奏者 / 录制声明 | 产品页 | 状态 |
| --- | --- | --- | --- |
| River Flows in You — Yiruma | Jacob Ladegaard（Jacob's Piano），商品页明确写 `Performance by Jacob Ladegaard` / `MIDI file of my performance` | [购买页](https://jacobspiano.com/product/river-flows-in-you-midi/) | 已核验真人演奏；未购买 |
| Comptine d'un autre été — Yann Tiersen | Jacob Ladegaard，商品页明确写 `Performance by Jacob Ladegaard` | [购买页](https://jacobspiano.com/product/amelie-midi/) | 已核验真人演奏；未购买 |
| Canon in D — Pachelbel | Jacob Ladegaard，商品页明确写 `Performance by Jacob Ladegaard` / `my performance` | [购买页](https://jacobspiano.com/product/canon-in-d-midi/) | 已核验真人演奏；未购买 |
| Merry-Go-Round of Life — Joe Hisaishi | Jacob's Piano，商品元数据明确写 `Merry-Go-Round`、`Recorded by Jacob's Piano` | [购买页](https://jacobspiano.com/product/howls-moving-castle-midi/) | 已核验真人演奏；未购买 |
| Nuvole Bianche — Ludovico Einaudi | Jacob's Piano，商品元数据明确写 `MIDI file containing the performance of Nuvole Bianche by Jacob's Piano` | [购买页](https://jacobspiano.com/product/nuvole-bianche-midi/) | 已核验真人演奏；未购买 |
| Experience — Ludovico Einaudi | Jacob's Piano，商品页标题与描述明确标示为其 performance MIDI | [购买页](https://jacobspiano.com/product/experience-midi/) | 已核验真人演奏；未购买 |

## 明确不做的事

- 不把试听片段、乐谱 MIDI、MuseScore 导出、音频转 MIDI 或来源不明的 `.mid` 冒充真人演奏。
- 不绕过付费、下载限制或个人使用许可证。
- 不把这些尚未购买的曲目列为“已导入”。

## 当前缺失但仍在继续寻找的目标

`Merry Christmas Mr. Lawrence`、`Castle in the Sky`、`Moonlight Sonata I`、`Prelude Op. 28 No. 4`、`Waltz Op. 69 No. 2`：截至本次检索，尚未找到可免费合法下载且能证明确为真人直录的版本；它们继续保留为缺失，不以低质量 MIDI 替代。

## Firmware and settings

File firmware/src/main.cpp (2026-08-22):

#include <Arduino.h>
#include <ArduinoJson.h>
#include <ESPmDNS.h>
#include <LittleFS.h>
#include <Preferences.h>
#include <Update.h>
#include <WebServer.h>
#include <WebSocketsServer.h>
#include <WiFi.h>
#include <WiFiUdp.h>

#include <algorithm>
#include <atomic>
#include <cstdio>
#include <cstring>
#include <esp_ota_ops.h>
#include <esp_partition.h>
#include <esp_system.h>
#include <esp_task_wdt.h>
#include <esp_timer.h>
#include <freertos/FreeRTOS.h>
#include <freertos/portmacro.h>
#include <freertos/task.h>

#include "Apa102Strip.h"
#include "UsbMidiHost.h"
#include "app_config.h"
#include "control_policy.h"
#include "layout_generated.h"
#include "midi_core.h"
#include "realtime_core.h"

// Arduino otherwise marks a newly booted OTA image valid before setup().
// Keeping it pending lets NoteFall prove that storage, networking, the main
// loop and the realtime task are healthy; an unconfirmed image is rolled back.
extern "C" bool verifyRollbackLater() { return true; }

namespace {

using notefall::Apa102Strip;
using notefall::Rgb;
using namespace notefall::app;
using namespace notefall::layout;

struct NoteState {
  bool target = false;
  bool pressed = false;
  uint8_t hand = 1;
  uint8_t velocity = 0;
};

struct ScheduledMidiMessage {
  uint32_t dueMs = 0;
  uint8_t status = 0;
  uint8_t data1 = 0;
  uint8_t data2 = 0;
};

struct OutputMirrorProbe {
  uint32_t expiresMs = 0;
  uint8_t status = 0;
  uint8_t data1 = 0;
  uint8_t data2 = 0;
};

struct WebUpdateState {
  bool authorized = false;
  bool started = false;
  bool success = false;
  bool firmwareTarget = false;
  bool filesystemUnmounted = false;
  size_t written = 0;
  String error;
};

enum class BrowserMidiKind : uint8_t { Note, Control };

struct BrowserMidiEvent {
  BrowserMidiKind kind = BrowserMidiKind::Note;
  bool on = false;
  uint8_t channel = 1;
  uint8_t firstData = 0;
  uint8_t secondData = 0;
  uint16_t highResolutionVelocity = 0;
  bool hasHighResolutionVelocity = false;
  uint32_t timestampMs = 0;
};

Apa102Strip strip(kPixelCount, kDataPin, kClockPin, kSpiHz);
notefall::UsbMidiHost usbMidi;
WebServer http(kHttpPort);
WebSocketsServer websocket(kWebSocketPort);
WiFiUDP discoveryUdp;
Preferences preferences;
NoteState notes[kNoteCount];
notefall::midi::HighResolutionVelocityTracker velocityTracker;

std::atomic<bool> pianoConnected{false};
bool mdnsStarted = false;
bool restartRequested = false;
bool preferencesReady = false;
bool littleFsReady = false;
bool stripReady = false;
bool usbHostReady = false;
bool accessPointReady = false;
bool otaPendingVerification = false;
bool otaExternalHealthSeen = false;
uint8_t previousApStationCount = 0;
wl_status_t previousStationStatus = WL_NO_SHIELD;
uint32_t lastStationReconnectMs = 0;
uint8_t stationReconnectAttempts = 0;
uint32_t otaBootStartedMs = 0;
esp_reset_reason_t bootResetReason = ESP_RST_UNKNOWN;
uint8_t webClients = 0;
uint8_t brightness = kDefaultGlobalBrightness;
int8_t pixelOffset = 0;
int8_t keyPixelOffsets[kNoteCount]{};
bool stripReversed = false;
// Persistent user preference: suppress every physical LED state until re-enabled.
bool stripEnabled = true;
uint32_t lastTargetMs = 0;
uint32_t lastStatusMs = 0;
int16_t testNote = -1;
uint32_t testUntilMs = 0;
constexpr size_t kScheduledMidiCapacity = 256;
constexpr size_t kOutputMirrorProbeCapacity = 48;
constexpr size_t kBrowserMidiCapacity = 128;
constexpr char kLittleFsPartitionLabel[] = "littlefs";
ScheduledMidiMessage scheduledMidi[kScheduledMidiCapacity]{};
size_t scheduledMidiCount = 0;
OutputMirrorProbe outputMirrorProbes[kOutputMirrorProbeCapacity]{};
size_t nextOutputMirrorProbe = 0;
uint32_t midiScheduleDropped = 0;
uint32_t midiOutputMirrorCandidates = 0;
int16_t midiOutOwner = -1;
static_assert(WEBSOCKETS_SERVER_CLIENT_MAX <= 255, "WebSocket client id must fit uint8_t");
bool webProtocolCompatible[WEBSOCKETS_SERVER_CLIENT_MAX]{};
bool webControlAuthorized[WEBSOCKETS_SERVER_CLIENT_MAX]{};
bool webAccessPointClient[WEBSOCKETS_SERVER_CLIENT_MAX]{};
uint32_t webMessagesRejected = 0;
uint32_t webAuthRejected = 0;
notefall::realtime::FixedQueue<BrowserMidiEvent, kBrowserMidiCapacity> browserMidiEvents;
uint32_t browserMidiDropped = 0;
uint32_t browserMidiResyncs = 0;
uint16_t browserMidiQueueHighWater = 0;
bool browserMidiResyncPending = false;
uint64_t pendingLedInputUs = 0;
notefall::realtime::LatencyAccumulator ledInputLatency;
notefall::realtime::LatencyAccumulator midiDispatchLatency;
portMUX_TYPE ledStateMux = portMUX_INITIALIZER_UNLOCKED;
portMUX_TYPE browserMidiMux = portMUX_INITIALIZER_UNLOCKED;
portMUX_TYPE realtimeMetricsMux = portMUX_INITIALIZER_UNLOCKED;
portMUX_TYPE outputMirrorMux = portMUX_INITIALIZER_UNLOCKED;
TaskHandle_t realtimeTaskHandle = nullptr;
bool ledDirty = true;
std::atomic<bool> realtimeTaskReady{false};
std::atomic<bool> realtimeWatchdogArmed{false};
std::atomic<bool> outputResetRequested{false};
std::atomic<bool> statusBroadcastRequested{false};
std::atomic<uint32_t> realtimeHeartbeatMs{0};
std::atomic<uint32_t> realtimeWakeups{0};
std::atomic<uint32_t> ledRenderGeneration{0};
uint32_t mainLoopLastUs = 0;
uint32_t mainLoopMaxUs = 0;
String activeApPassword;
String controlSessionToken;
String configuredStationSsid;
String configuredStationPassword;
WebUpdateState webUpdate;

constexpr Rgb kLeftTarget{28, 178, 255};
constexpr Rgb kRightTarget{255, 42, 175};
constexpr Rgb kCorrect{35, 255, 104};
constexpr Rgb kWrong{255, 55, 28};
constexpr Rgb kTest{255, 210, 32};
constexpr int8_t kMaxKeyPixelOffset = 4;
constexpr uint32_t kMaxMidiScheduleDelayMs = 60000;
constexpr uint32_t kOutputMirrorProbeMs = 80;
constexpr size_t kMaxWebMessageBytes = 8192;
constexpr size_t kBrowserMidiFlushBatch = 12;
constexpr uint32_t kRealtimeIdlePollMs = 5;
constexpr uint32_t kRealtimeTaskStackBytes = 6144;
constexpr UBaseType_t kRealtimeTaskPriority = 7;
constexpr char kUpdateAuthHeader[] = "X-NoteFall-Admin";
constexpr char kRecoveryPage[] PROGMEM = R"HTML(<!doctype html>
<html lang="zh-CN"><meta charset="utf-8"><meta name="viewport" content="width=device-width,initial-scale=1">
<title>NoteFall 88 Rescue</title><style>body{font:16px system-ui;max-width:720px;margin:30px auto;padding:0 18px;background:#0b1020;color:#eef}fieldset{margin:18px 0;padding:16px;border:1px solid #667;border-radius:12px}input,select,button{font:inherit;padding:10px;margin:5px 0;max-width:100%;box-sizing:border-box}button{cursor:pointer}pre{white-space:pre-wrap}progress{width:100%}</style>
<h1>NoteFall 88 救援页</h1><p>这个页面内置在固件中，即使普通网页损坏也可以恢复。救援热点 <b>NoteFall-88</b> 会一直保留。</p>
<button onclick="status()">刷新状态</button><pre id="s">正在读取…</pre>
<fieldset><legend>恢复更新</legend><input id="p" type="password" placeholder="设备管理密码"><br><select id="t"><option value="firmware">固件</option><option value="filesystem">网页文件</option></select><input id="f" type="file" accept=".bin"><button onclick="upload()">开始恢复</button><progress id="g" max="1" value="0"></progress><pre id="r"></pre></fieldset>
<fieldset><legend>重新设置家庭 Wi-Fi</legend><input id="n" placeholder="2.4GHz Wi-Fi 名称"><input id="w" type="password" placeholder="Wi-Fi 密码"><button onclick="wifi()">保存并重启</button></fieldset>
<script>
async function status(){try{s.textContent=JSON.stringify(await (await fetch('/api/status',{cache:'no-store'})).json(),null,2)}catch(e){s.textContent=String(e)}}
function auth(){return p.value}function upload(){if(!f.files[0]||!auth())return r.textContent='请选择文件并输入管理密码';let x=new XMLHttpRequest;x.open('POST','/api/update?target='+t.value);x.setRequestHeader('X-NoteFall-Admin',auth());x.upload.onprogress=e=>{if(e.lengthComputable)g.value=e.loaded/e.total};x.onload=()=>r.textContent=x.responseText;x.onerror=()=>r.textContent='上传中断；旧固件仍然安全';let d=new FormData;d.append('image',f.files[0]);x.send(d)}
async function wifi(){if(!auth())return r.textContent='请输入管理密码';let b=new URLSearchParams({ssid:n.value,password:w.value});let q=await fetch('/api/wifi',{method:'POST',headers:{'Content-Type':'application/x-www-form-urlencoded','X-NoteFall-Admin':auth()},body:b});r.textContent=await q.text()}
status();
</script></html>)HTML";

template <typename T>
T clampValue(T value, T low, T high) {
  return value < low ? low : (value > high ? high : value);
}

const char* resetReasonName(esp_reset_reason_t reason) {
  switch (reason) {
    case ESP_RST_POWERON: return "power-on";
    case ESP_RST_EXT: return "external-reset";
    case ESP_RST_SW: return "software-reset";
    case ESP_RST_PANIC: return "panic";
    case ESP_RST_INT_WDT: return "interrupt-watchdog";
    case ESP_RST_TASK_WDT: return "task-watchdog";
    case ESP_RST_WDT: return "watchdog";
    case ESP_RST_DEEPSLEEP: return "deep-sleep";
    case ESP_RST_BROWNOUT: return "brownout";
    case ESP_RST_SDIO: return "sdio";
    default: return "unknown";
  }
}

String generateControlSessionToken() {
  char encoded[33]{};
  for (size_t word = 0; word < 4; ++word) {
    snprintf(encoded + word * 8, 9, "%08lx", static_cast<unsigned long>(esp_random()));
  }
  return String(encoded);
}

bool validNote(int note) { return note >= kFirstMidiNote && note <= kLastMidiNote; }

bool constantTimeEquals(const String& first, const String& second) {
  const size_t maximum = std::max(first.length(), second.length());
  uint8_t difference = static_cast<uint8_t>(first.length() ^ second.length());
  for (size_t index = 0; index < maximum; ++index) {
    const char a = index < first.length() ? first[index] : 0;
    const char b = index < second.length() ? second[index] : 0;
    difference |= static_cast<uint8_t>(a ^ b);
  }
  return difference == 0;
}

size_t noteIndex(uint8_t note) { return static_cast<size_t>(note - kFirstMidiNote); }

bool timeReached(uint32_t now, uint32_t target) {
  return notefall::midi::timeReached(now, target);
}

bool validOutputMessage(uint8_t status, uint8_t data1, uint8_t data2) {
  if ((status & 0x80U) == 0 || data1 > 127 || data2 > 127) return false;
  const uint8_t command = status & 0xF0U;
  return command >= 0x80U && command <= 0xE0U;
}

void registerOutputMirrorProbe(uint8_t status, uint8_t data1, uint8_t data2, uint32_t now) {
  portENTER_CRITICAL(&outputMirrorMux);
  OutputMirrorProbe& probe = outputMirrorProbes[nextOutputMirrorProbe];
  probe.expiresMs = now + kOutputMirrorProbeMs;
  probe.status = status;
  probe.data1 = data1;
  probe.data2 = data2;
  nextOutputMirrorProbe = (nextOutputMirrorProbe + 1) % kOutputMirrorProbeCapacity;
  portEXIT_CRITICAL(&outputMirrorMux);
}

void observeOutputMirrorCandidate(uint8_t status, uint8_t data1, uint8_t data2, uint32_t now) {
  portENTER_CRITICAL(&outputMirrorMux);
  for (auto& probe : outputMirrorProbes) {
    if (probe.expiresMs == 0 || timeReached(now, probe.expiresMs)) {
      probe.expiresMs = 0;
      continue;
    }
    const bool exact = probe.status == status && probe.data1 == data1 && probe.data2 == data2;
    const bool probeIsOff = (probe.status & 0xF0U) == 0x80U ||
        ((probe.status & 0xF0U) == 0x90U && probe.data2 == 0);
    const bool messageIsOff = (status & 0xF0U) == 0x80U ||
        ((status & 0xF0U) == 0x90U && data2 == 0);
    const bool equivalentNoteOff = probeIsOff && messageIsOff &&
        (probe.status & 0x0FU) == (status & 0x0FU) && probe.data1 == data1;
    if (exact || equivalentNoteOff) {
      probe.expiresMs = 0;
      ++midiOutputMirrorCandidates;
      portEXIT_CRITICAL(&outputMirrorMux);
      return;
    }
  }
  portEXIT_CRITICAL(&outputMirrorMux);
}

bool scheduleMidiMessage(uint32_t dueMs, uint8_t status, uint8_t data1, uint8_t data2) {
  if (!validOutputMessage(status, data1, data2) || scheduledMidiCount >= kScheduledMidiCapacity) {
    ++midiScheduleDropped;
    return false;
  }
  ScheduledMidiMessage& message = scheduledMidi[scheduledMidiCount++];
  message.dueMs = dueMs;
  message.status = status;
  message.data1 = data1;
  message.data2 = data2;
  return true;
}

void panicMidiOutput() {
  scheduledMidiCount = 0;
  portENTER_CRITICAL(&outputMirrorMux);
  for (auto& probe : outputMirrorProbes) probe.expiresMs = 0;
  portEXIT_CRITICAL(&outputMirrorMux);
  usbMidi.panic();
}

void processScheduledMidi() {
  if (scheduledMidiCount == 0) return;
  if (!usbMidi.outputAvailable()) {
    midiScheduleDropped += scheduledMidiCount;
    scheduledMidiCount = 0;
    return;
  }
  const uint32_t now = millis();
  size_t retained = 0;
  const size_t originalCount = scheduledMidiCount;
  for (size_t index = 0; index < originalCount; ++index) {
    const ScheduledMidiMessage message = scheduledMidi[index];
    const bool due = timeReached(now, message.dueMs);
    const bool sent = due && usbMidi.sendMidiMessage(
        message.status, message.data1, message.data2);
    if (sent) {
      registerOutputMirrorProbe(message.status, message.data1, message.data2, now);
    } else {
      scheduledMidi[retained++] = message;
    }
  }
  scheduledMidiCount = retained;
}

void notifyRealtime() {
  const TaskHandle_t task = realtimeTaskHandle;
  if (task != nullptr) xTaskNotifyGive(task);
}

void clearTargets() {
  portENTER_CRITICAL(&ledStateMux);
  for (auto& note : notes) note.target = false;
  lastTargetMs = 0;
  ledDirty = true;
  portEXIT_CRITICAL(&ledStateMux);
  notifyRealtime();
}

bool renderStrip() {
  NoteState snapshot[kNoteCount];
  int8_t offsetSnapshot[kNoteCount];
  uint8_t brightnessSnapshot = 1;
  int8_t globalOffsetSnapshot = 0;
  int16_t testNoteSnapshot = -1;
  bool reversedSnapshot = false;
  bool enabledSnapshot = true;
  const uint32_t now = millis();

  portENTER_CRITICAL(&ledStateMux);
  if (lastTargetMs != 0 && now - lastTargetMs > kTargetStaleMs) {
    for (auto& note : notes) note.target = false;
    lastTargetMs = 0;
    ledDirty = true;
  }
  if (testNote >= 0 && timeReached(now, testUntilMs)) {
    testNote = -1;
    ledDirty = true;
  }
  if (!ledDirty) {
    portEXIT_CRITICAL(&ledStateMux);
    return false;
  }
  ledDirty = false;
  std::memcpy(snapshot, notes, sizeof(snapshot));
  std::memcpy(offsetSnapshot, keyPixelOffsets, sizeof(offsetSnapshot));
  brightnessSnapshot = brightness;
  globalOffsetSnapshot = pixelOffset;
  testNoteSnapshot = testNote;
  reversedSnapshot = stripReversed;
  enabledSnapshot = stripEnabled;
  portEXIT_CRITICAL(&ledStateMux);

  strip.clear();
  if (enabledSnapshot) for (uint8_t midiNote = kFirstMidiNote; midiNote <= kLastMidiNote; ++midiNote) {
    const size_t index = noteIndex(midiNote);
    const int pixel = notefall::midi::mapPixel(
        midiNote, kFirstMidiNote, kLastMidiNote, kPixelCount, kPixelByNote,
        offsetSnapshot, globalOffsetSnapshot, reversedSnapshot);
    if (pixel < 0) continue;
    Rgb color{};
    if (snapshot[index].target) {
      color = snapshot[index].hand == 0 ? kLeftTarget : kRightTarget;
    }
    if (snapshot[index].pressed) color = snapshot[index].target ? kCorrect : kWrong;
    if (midiNote == testNoteSnapshot) color = kTest;
    strip.setPixel(static_cast<size_t>(pixel), color);
  }
  const bool transmitted = strip.show(
      std::min<uint8_t>(brightnessSnapshot, kMaxGlobalBrightness));
  if (pendingLedInputUs != 0) {
    const uint64_t elapsed = static_cast<uint64_t>(esp_timer_get_time()) - pendingLedInputUs;
    portENTER_CRITICAL(&realtimeMetricsMux);
    ledInputLatency.observe(elapsed);
    portEXIT_CRITICAL(&realtimeMetricsMux);
    pendingLedInputUs = 0;
  }
  ledRenderGeneration.fetch_add(1, std::memory_order_release);
  return transmitted;
}

void sendStatus(uint8_t client = 255) {
  if (client == 255) {
    for (uint8_t index = 0; index < WEBSOCKETS_SERVER_CLIENT_MAX; ++index) {
      if (websocket.clientIsConnected(index)) sendStatus(index);
    }
    return;
  }
  const auto usb = usbMidi.diagnostics();
  const auto led = strip.diagnostics();
  notefall::realtime::LatencySnapshot ledLatency;
  notefall::realtime::LatencySnapshot dispatchLatency;
  portENTER_CRITICAL(&realtimeMetricsMux);
  ledLatency = ledInputLatency.snapshot();
  dispatchLatency = midiDispatchLatency.snapshot();
  portEXIT_CRITICAL(&realtimeMetricsMux);
  uint32_t mirrorCandidates = 0;
  portENTER_CRITICAL(&outputMirrorMux);
  mirrorCandidates = midiOutputMirrorCandidates;
  portEXIT_CRITICAL(&outputMirrorMux);
  uint32_t webMidiDroppedSnapshot = 0;
  uint32_t webMidiResyncsSnapshot = 0;
  uint16_t webMidiDepth = 0;
  uint16_t webMidiHighWater = 0;
  portENTER_CRITICAL(&browserMidiMux);
  webMidiDroppedSnapshot = browserMidiDropped;
  webMidiResyncsSnapshot = browserMidiResyncs;
  webMidiDepth = static_cast<uint16_t>(browserMidiEvents.size());
  webMidiHighWater = browserMidiQueueHighWater;
  portEXIT_CRITICAL(&browserMidiMux);
  JsonDocument doc;
  doc["t"] = "status";
  doc["protocol"] = kProtocolVersion;
  doc["firmware"] = kFirmwareVersion;
  doc["controlSessionReady"] = webProtocolCompatible[client];
  doc["controlAuthorized"] = webControlAuthorized[client];
  doc["accessPointClient"] = webAccessPointClient[client];
  doc["defaultPassword"] = activeApPassword == kApPassword;
  if (webControlAuthorized[client] && !webAccessPointClient[client]) {
    doc["controlToken"] = controlSessionToken;
  }
  doc["piano"] = pianoConnected.load();
  doc["clients"] = webClients;
  doc["brightness"] = brightness;
  doc["offset"] = pixelOffset;
  doc["reversed"] = stripReversed;
  doc["stripEnabled"] = stripEnabled;
  doc["rssi"] = WiFi.status() == WL_CONNECTED ? WiFi.RSSI() : 0;
  doc["stationConnected"] = WiFi.status() == WL_CONNECTED;
  doc["stationIp"] = WiFi.status() == WL_CONNECTED ? WiFi.localIP().toString() : "";
  doc["hostname"] = String(kHostname) + ".local";
  doc["rescueSsid"] = kApSsid;
  doc["otaPending"] = otaPendingVerification;
  doc["uptimeMs"] = millis();
  doc["freeHeap"] = ESP.getFreeHeap();
  doc["psramBytes"] = ESP.getPsramSize();
  doc["freePsram"] = ESP.getFreePsram();
  doc["nvsReady"] = preferencesReady;
  doc["resetReason"] = resetReasonName(bootResetReason);
  doc["usbPackets"] = usb.packetsReceived;
  doc["usbDropped"] = usb.packetsDropped;
  doc["usbMalformed"] = usb.packetsMalformed;
  doc["usbErrors"] = usb.transferErrors;
  doc["usbLastError"] = usbMidi.lastError();
  doc["usbConnections"] = usb.connections;
  doc["usbLastPacketMs"] = usb.lastPacketMs;
  doc["usbVid"] = usb.vendorId;
  doc["usbPid"] = usb.productId;
  doc["usbEndpoint"] = usb.endpointAddress;
  doc["usbPacketSize"] = usb.endpointPacketSize;
  doc["usbOut"] = usbMidi.outputAvailable();
  doc["usbOutEndpoint"] = usb.outputEndpointAddress;
  doc["usbOutPacketSize"] = usb.outputEndpointPacketSize;
  doc["usbOutPackets"] = usb.packetsSent;
  doc["usbOutDropped"] = usb.outputPacketsDropped + midiScheduleDropped;
  doc["usbOutErrors"] = usb.outputTransferErrors;
  doc["usbOutQueued"] = scheduledMidiCount;
  doc["usbInputQueueDepth"] = usb.inputQueueDepth;
  doc["usbInputQueueHighWater"] = usb.inputQueueHighWater;
  doc["usbOutputQueueDepth"] = usb.outputQueueDepth;
  doc["usbOutputQueueHighWater"] = usb.outputQueueHighWater;
  doc["usbLargestInputBatch"] = usb.largestInputBatch;
  doc["usbInputResubmitRetries"] = usb.inputResubmitRetries;
  doc["usbClientWatchdog"] = usb.clientWatchdogArmed;
  doc["usbDaemonWatchdog"] = usb.daemonWatchdogArmed;
  doc["usbOutputMirrorCandidates"] = mirrorCandidates;
  doc["usbOutOwned"] = midiOutOwner >= 0;
  doc["webRejected"] = webMessagesRejected;
  doc["webAuthRejected"] = webAuthRejected;
  doc["webMidiDropped"] = webMidiDroppedSnapshot;
  doc["webMidiResyncs"] = webMidiResyncsSnapshot;
  doc["webMidiQueueDepth"] = webMidiDepth;
  doc["webMidiQueueHighWater"] = webMidiHighWater;
  doc["midiDispatchLatencyLastUs"] = dispatchLatency.lastUs;
  doc["midiDispatchLatencyAvgUs"] = dispatchLatency.averageUs;
  doc["midiDispatchLatencyMaxUs"] = dispatchLatency.maxUs;
  doc["midiDispatchLatencySamples"] = dispatchLatency.samples;
  doc["ledInputLatencyLastUs"] = ledLatency.lastUs;
  doc["ledInputLatencyAvgUs"] = ledLatency.averageUs;
  doc["ledInputLatencyMaxUs"] = ledLatency.maxUs;
  doc["ledInputLatencySamples"] = ledLatency.samples;
  doc["ledFrames"] = led.framesSent;
  doc["ledFramesSkipped"] = led.unchangedFramesSkipped;
  doc["ledSpiLastUs"] = led.lastTransferUs;
  doc["ledSpiMaxUs"] = led.maxTransferUs;
  doc["ledFrameBytes"] = led.frameBytes;
  doc["realtimeReady"] = realtimeTaskReady.load();
  doc["realtimeWatchdog"] = realtimeWatchdogArmed.load();
  doc["realtimeHeartbeatAgeMs"] = millis() - realtimeHeartbeatMs.load();
  doc["realtimeWakeups"] = realtimeWakeups.load();
  doc["realtimeStackFreeBytes"] = realtimeTaskHandle == nullptr
      ? 0
      : uxTaskGetStackHighWaterMark(realtimeTaskHandle);
  doc["mainLoopLastUs"] = mainLoopLastUs;
  doc["mainLoopMaxUs"] = mainLoopMaxUs;
  String payload;
  serializeJson(doc, payload);
  websocket.sendTXT(client, payload);
}
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
void loop() {
  const int64_t loopStartedUs = esp_timer_get_time();
  if (realtimeTaskHandle == nullptr) serviceRealtimePipeline();
  if (outputResetRequested.exchange(false)) {
    midiOutOwner = -1;
    scheduledMidiCount = 0;
    panicMidiOutput();
  }
  flushBrowserMidi();
  processScheduledMidi();
  recoverHttpAfterAccessPointDeparture();
  serviceDiscovery();
  http.handleClient();
  websocket.loop();

  const uint32_t now = millis();
  maintainStationConnection(now);
  serviceOtaBootVerification(now);
  if (statusBroadcastRequested.exchange(false) ||
      now - lastStatusMs >= kStatusBroadcastMs) {
    lastStatusMs = now;
    sendStatus();
  }
  if (restartRequested) {
    delay(300);
    ESP.restart();
  }
  const int64_t elapsedUs = esp_timer_get_time() - loopStartedUs;
  mainLoopLastUs = static_cast<uint32_t>(
      std::min<int64_t>(std::max<int64_t>(0, elapsedUs), UINT32_MAX));
  mainLoopMaxUs = std::max(mainLoopMaxUs, mainLoopLastUs);
  delay(1);
}

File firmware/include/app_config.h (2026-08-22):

#pragma once

#include <Arduino.h>

namespace notefall::app {
constexpr char kFirmwareVersion[] = "0.7.2";
constexpr uint8_t kProtocolVersion = 6;
constexpr char kApSsid[] = "NoteFall-88";
constexpr char kApPassword[] = "notefall88";
constexpr char kHostname[] = "notefall";
constexpr uint16_t kHttpPort = 80;
constexpr uint16_t kWebSocketPort = 81;
constexpr uint16_t kDiscoveryPort = 32188;
constexpr uint32_t kStatusBroadcastMs = 1000;
constexpr uint32_t kTestNoteMs = 1800;
constexpr uint32_t kStationReconnectMs = 10000;
// A plain WiFi.reconnect() can remain stuck on a stale association after an
// access point reboot.  Periodically restart the STA association without
// erasing credentials; the rescue AP remains available throughout.
constexpr uint8_t kStationReconnectsBeforeFreshBegin = 3;
constexpr uint32_t kOtaHealthDelayMs = 10000;
constexpr uint32_t kOtaConfirmationDeadlineMs = 90000;
constexpr int8_t kMinPixelOffset = -8;
constexpr int8_t kMaxPixelOffset = 8;
}  // namespace notefall::app

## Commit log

2026-08-01 建立 PX-S7000 下落音符系统 V0 工程基线
    [bom_v0.csv, v0_alignment_jig.step, v0_alignment_jig.stl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]
2026-08-04 重构为单灯带 USB-MIDI 完整系统
    [bom.csv, bom_v0.csv, controller_lid.step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]
2026-08-05 添加 PX-S7000 安装效果概念图
2026-08-05 补充3D打印导轨安装近景
2026-08-05 取消琴键侧打印盒并改用竖直裸灯带
    [bom.csv, controller_lid.step, controller_tray.step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]
2026-08-05 docs: analyze open-source piano LED projects
2026-08-05 feat: add per-key calibration and score transposition
2026-08-05 feat: harden production hardware package
    [bom.csv, controller_lid.step, controller_lid.stl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]
2026-08-05 fix: separate USB host data and board power
    [bom.csv, harness.csv]
2026-08-05 fix: power USB device VBUS through OTG Y cable
    [bom.csv, harness.csv]
2026-08-05 feat: make library restore atomic and bounded
    [bom.csv]
2026-08-05 fix: validate persisted calibration state
    [app_config.h, main.cpp]
2026-08-05 docs: lock USB power decision and completion evidence
2026-08-05 feat: diagnose resets and polish mobile maintenance
    [app_config.h, main.cpp]
2026-08-05 docs: add no-solder first build handoff
2026-08-05 feat: prioritize local LED latency and validate protocol
2026-08-05 fix: never suppress ambiguous piano input
    [app_config.h, main.cpp]
2026-08-05 feat: support high-resolution piano velocity
2026-08-05 test: pin W3C MusicXML compatibility corpus
2026-08-05 fix: align wifi credential byte limits
    [main.cpp]
2026-08-05 build: target exact N8R8 board profile
2026-08-05 test: cover device link lifecycle
2026-08-05 test: automate real browser smoke flow
2026-08-06 ci: compare CAD geometry with platform tolerance
2026-08-09 docs: record purchased hardware and arrival checks
    [as-purchased.csv]
2026-08-10 feat: add score practice heatmap
2026-08-10 feat: add adaptive weak-passage circuits
2026-08-11 fix: model purchased LED strip splice geometry
    [as-purchased.csv]
2026-08-16 fix: mount the configured LittleFS partition
    [main.cpp]
2026-08-16 feat: add portable field calibration profiles
2026-08-16 fix: recover HTTP after access point departure
    [main.cpp]
2026-08-16 feat: harden device discovery and recovery
2026-08-16 feat: streamline physical key calibration
2026-08-19 feat: add jianpu notation, unified top timeline, and format-based library filtering
2026-08-19 feat(musicxml): add piano part detection, DOM filtering and score-partwise contract
2026-08-20 fix(studio): stabilize rendering and simplify library
    [NativeWaterfallPlugin.java]
2026-08-20 fix(android): stabilize native waterfall compositor
    [NativeWaterfallPlugin.java]
2026-08-20 Revert "fix(android): stabilize native waterfall compositor"
    This reverts commit c6ea7bca975ed15112f11edc18ddd62d6133396f.
    [NativeWaterfallPlugin.java]
2026-08-29 Fix score import destination flow
2026-09-06 build(deps): bump @capacitor/android from 8.5.0 to 8.5.1 in /studio
    Bumps [@capacitor/android](https://github.com/ionic-team/capacitor) from 8.5.0 to 8.5.1.
    - [Release notes](https://github.com/ionic-team/capacitor/releases)
    - [Changelog](https://github.com/ionic-team/capacitor/blob/main/CHANGELOG.md)
    - [Commits](https://github.com/ionic-team/capacitor/compare/8.5.0...8.5.1)
    ---
    updated-dependencies:
    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

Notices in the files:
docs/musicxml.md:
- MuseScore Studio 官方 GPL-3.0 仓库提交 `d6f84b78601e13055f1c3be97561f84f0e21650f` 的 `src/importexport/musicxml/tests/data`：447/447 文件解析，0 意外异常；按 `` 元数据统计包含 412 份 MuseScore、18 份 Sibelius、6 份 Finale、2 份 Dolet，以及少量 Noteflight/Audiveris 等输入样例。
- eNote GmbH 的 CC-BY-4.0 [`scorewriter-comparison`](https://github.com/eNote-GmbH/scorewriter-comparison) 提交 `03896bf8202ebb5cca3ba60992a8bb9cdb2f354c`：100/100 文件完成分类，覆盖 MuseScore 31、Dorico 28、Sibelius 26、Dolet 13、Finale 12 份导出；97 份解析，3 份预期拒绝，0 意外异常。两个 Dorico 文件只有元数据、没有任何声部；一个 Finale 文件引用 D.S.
